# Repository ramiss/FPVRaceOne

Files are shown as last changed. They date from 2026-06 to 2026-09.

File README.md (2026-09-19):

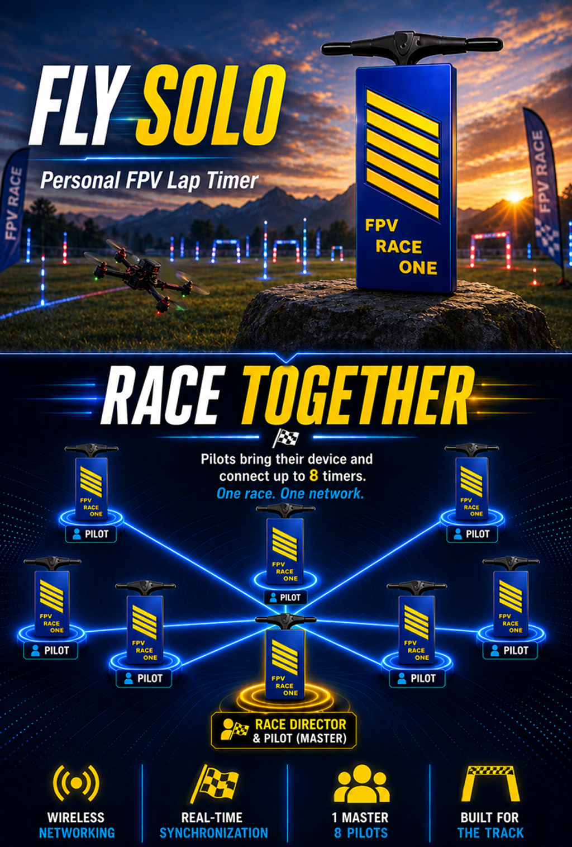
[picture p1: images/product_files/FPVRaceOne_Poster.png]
Poster


# FPVRaceOne

**Personal FPV Lap Timer**

[Build one yourself](docs/BUILD_FROM_SCRATCH.md) OR
[Purchase FPVRaceOne ready to use](https://fpvwidgets.square.site)



A single node personal lap timing solution for 5.8 GHz FPV drones that can be networked to other units (8 total) for multi-pilot racing. Perfect for personal race or practice sessions with one unit (indoor and large scale) up to MultiGP race events with multiple units. No additional networking hardware required — just plug in a USB power, connect over wifi, calibrate, and fly.

**Up to 8 devices can wirelessly network with each other to act as a single multi-node lap timer (no additional hardware or software needed)** — one device is set to master mode and acts as race director with up to 7 additional clients. Manually connect clients or have the master automatically recruit clients in range.  Master can see all pilot times and control the race, while single pilots can remain logged into their device and see all other racer times - or initiate individual practice races. 

**Documentation**  
[Quick Start](QUICKSTART.md) - To get started as a single pilot with the bare minimum information  
[Getting Started](docs/GETTING_STARTED.md) - For a more comprehensive step by step guide  
[User Guide](docs/USER_GUIDE.md) - The full manual, but not necessarily a step by step  
[Build From Scratch](docs/BUILD_FROM_SCRATCH.md) - Wiring, assembly and flashing, if you'd rather build your own

---

## Screenshots - Single Mode

| Race Screen | Configuration |
|:---:|:---:|
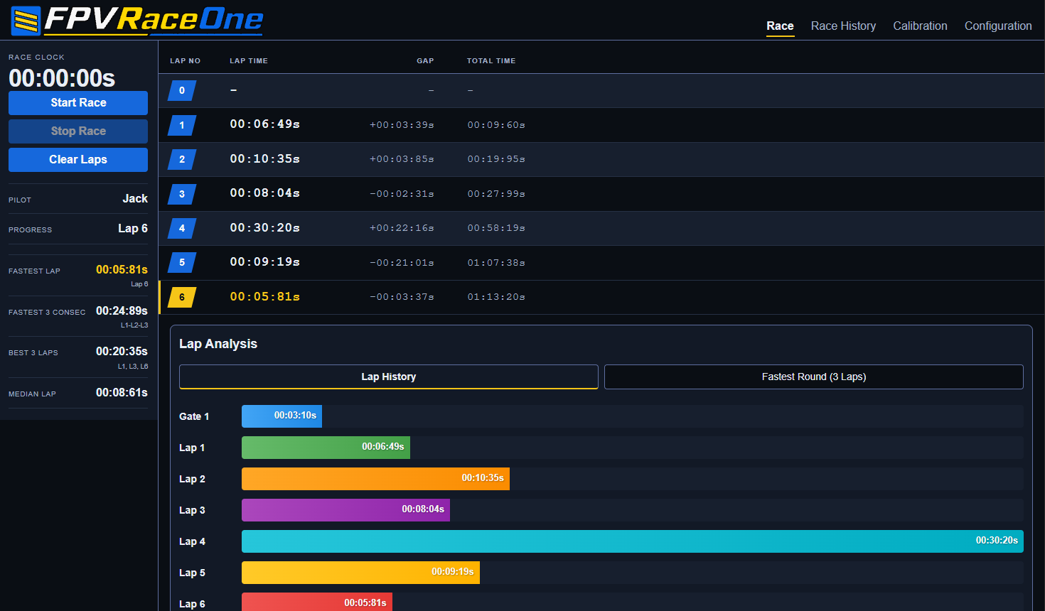
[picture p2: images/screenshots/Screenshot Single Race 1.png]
Race Screen
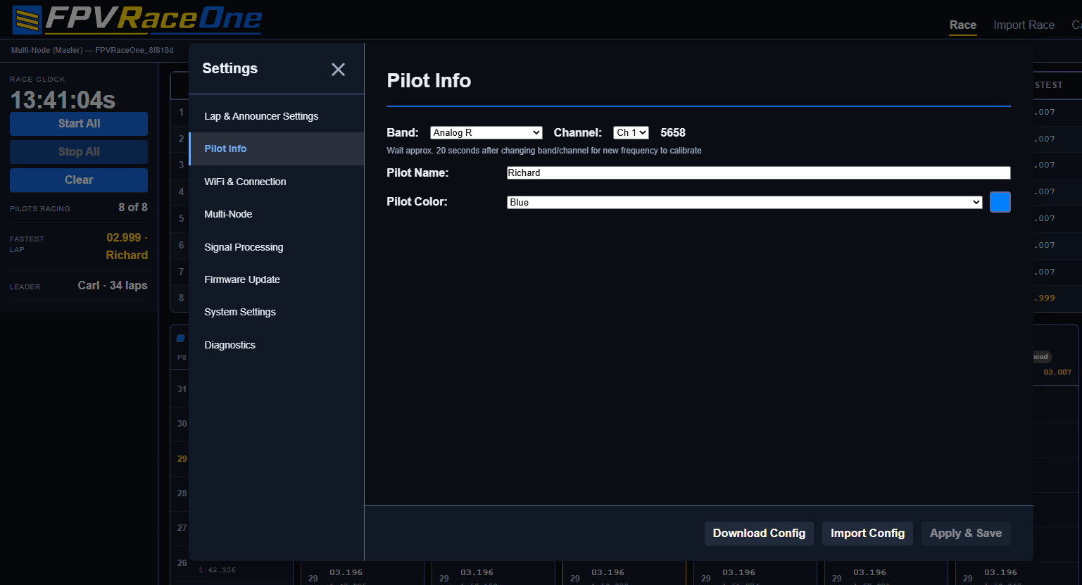
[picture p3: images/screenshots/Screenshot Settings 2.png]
Config Menu
|  |  |

| Calibration Wizard — Recording | Calibration Wizard — Complete |
|:---:|:---:|
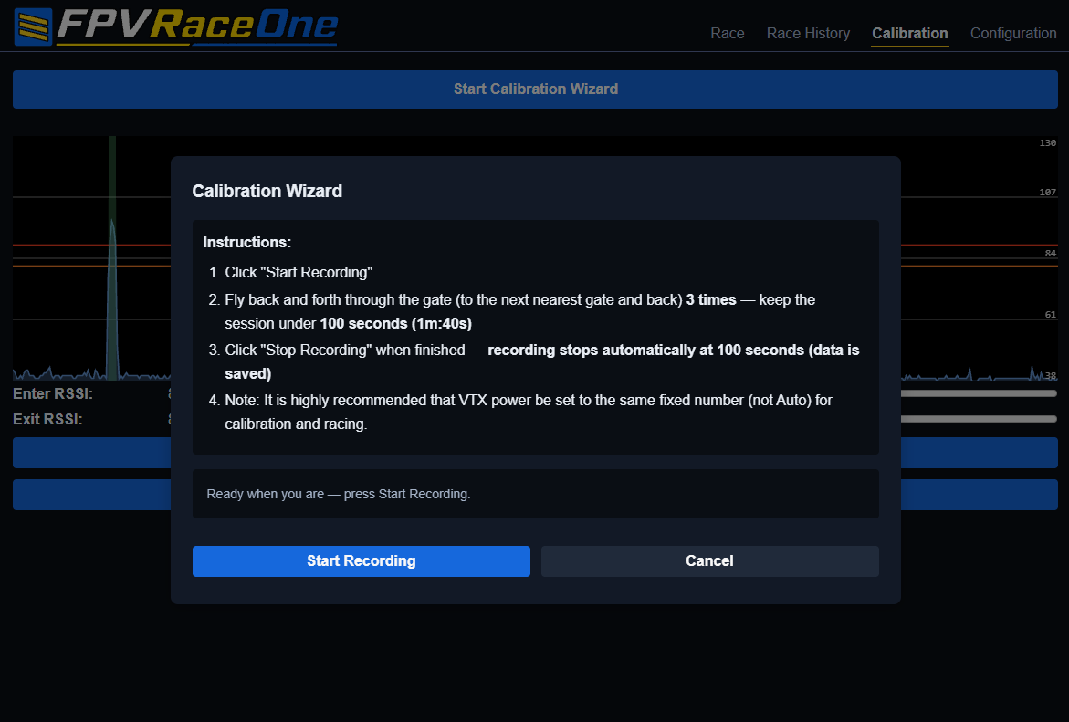
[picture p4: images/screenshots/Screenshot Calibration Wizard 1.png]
Calibration Recording
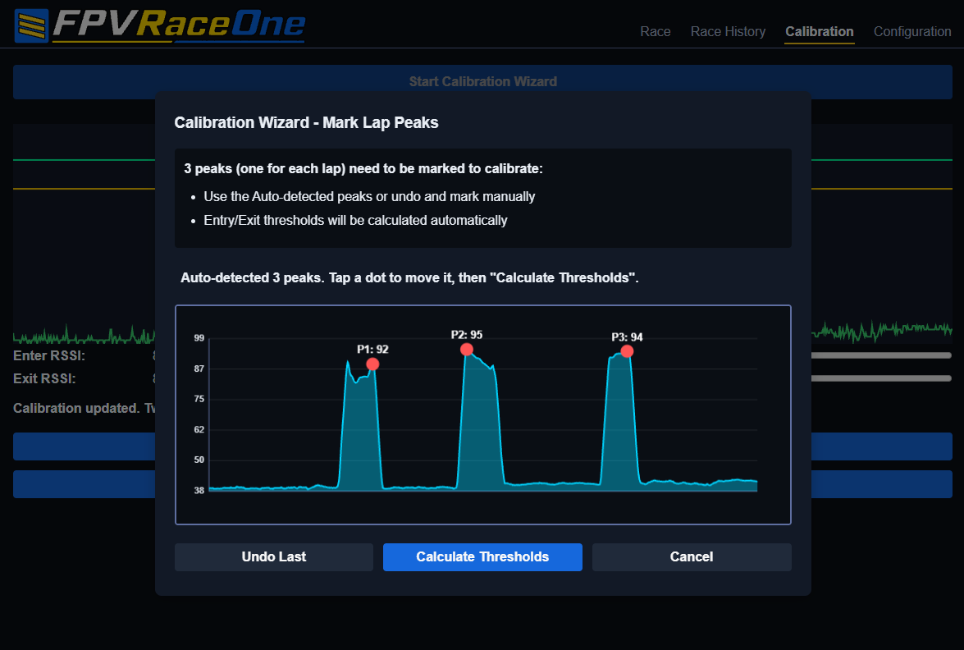
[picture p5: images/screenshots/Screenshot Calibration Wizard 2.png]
Calibration Complete
|  |  |

## Screenshots - Multi Mode

| Master Race Screen | Master Pilot Edit |
|:---:|:---:|
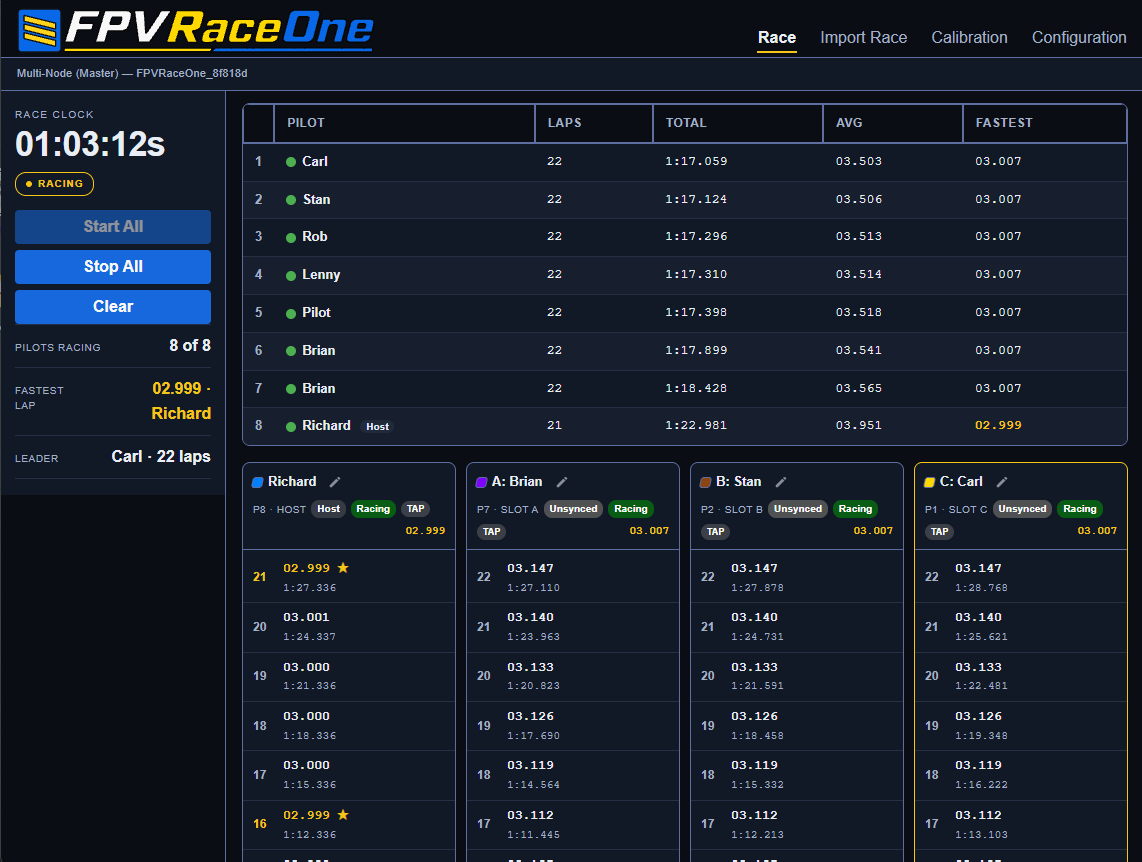
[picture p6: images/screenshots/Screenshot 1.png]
Master Race Screen
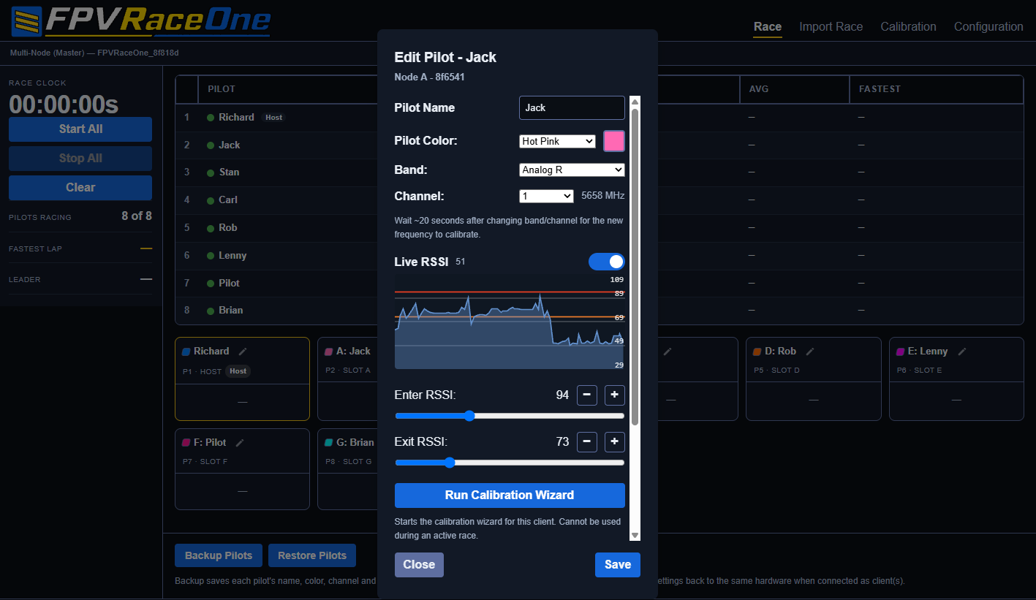
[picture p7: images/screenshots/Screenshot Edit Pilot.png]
Master Pilot Edit
|  |  |

## 14 Themes to choose from (4 samples below)

<p>
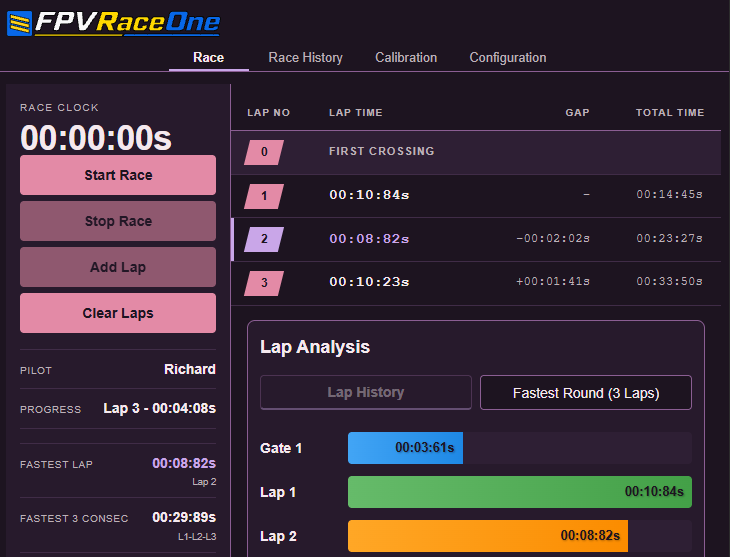
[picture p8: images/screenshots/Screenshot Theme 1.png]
Theme example 1
  
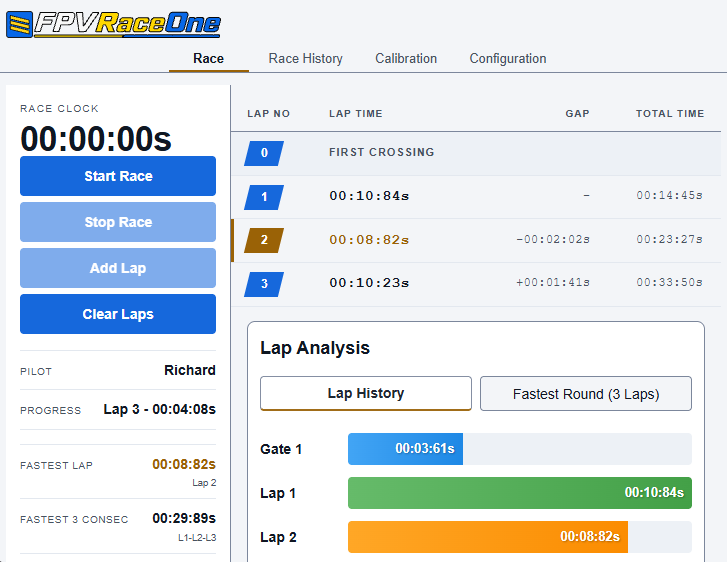
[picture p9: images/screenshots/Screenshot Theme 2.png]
Theme example 2
  
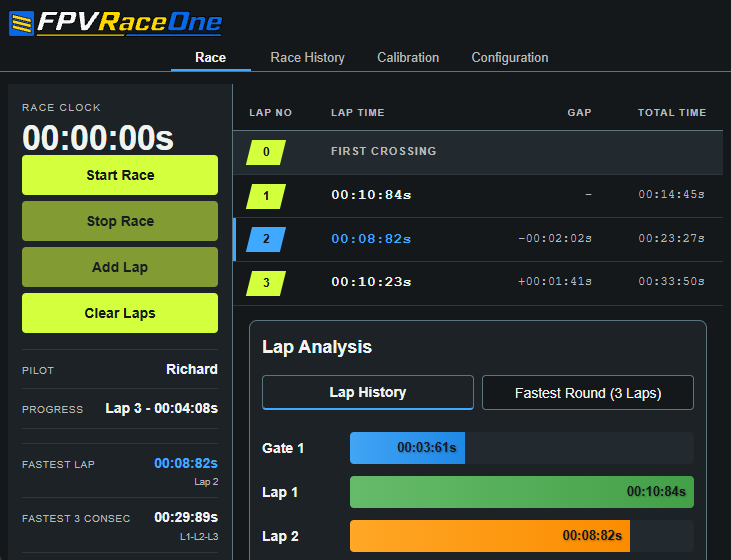
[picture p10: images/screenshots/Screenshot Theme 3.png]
Theme example 3
  
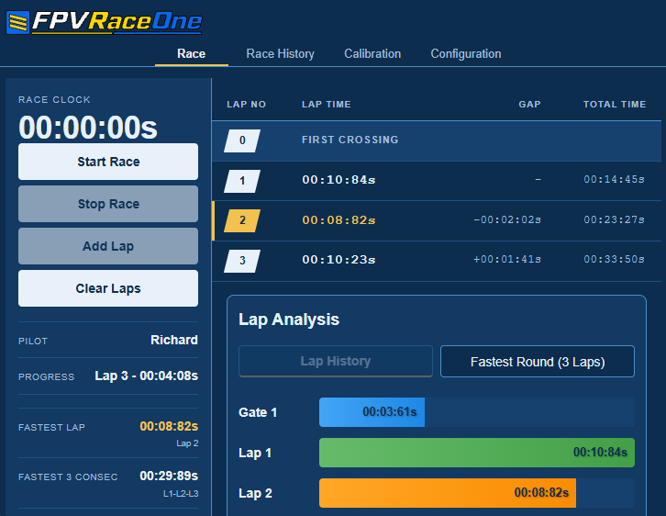
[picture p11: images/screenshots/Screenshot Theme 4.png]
Theme example 4
  
</p>

---

## How It Works

FPVRaceOne uses an RX5808 video receiver module to monitor your drone's video transmitter RSSI (signal strength). As you fly through the timing gate:

1. **Approach** — RSSI rises above the Enter threshold → crossing begins
2. **Peak** — RSSI peaks when you're closest to the gate
3. **Exit** — RSSI falls below the Exit threshold → lap time recorded

**Note that FPVRaceOne has an automatic calibration wizard to take the guess work out of setting the RSSI values (see below)**

```
RSSI  │     /\
      │    /  \
      │   /    \     ← Single clean peak
Enter ├──/──────\───
      │ /        \
Exit  ├/──────────\─
      └─────────────── Time
```

The time between consecutive peaks is your lap time. The signal processing pipeline is tuned with sensible defaults out of the box, with a single Pipeline Smoothing slider for fine-tuning the balance between responsiveness and noise rejection.

---

## Key Features

### Connectivity
- **WiFi Access Point** — works with any browser on any device (laptop, pc, phone or tablet) with wifi, no app required
- **Built-in Multi-Node Networking** — up to 8 lap timers can connect together to run a multi pilot race.

### Signal Processing

**Hardware-timed acquisition.** The ESP32-C6's ADC samples the RX5808's RSSI line
continuously into a DMA ring at **20 kHz**, completely independent of CPU
scheduling. 

**Single-stage filtering.** A running median with a small odd window
(**N = 3–15**, default **7**, set by the Pipeline Smoothing slider). A median
rejects isolated spike samples outright while preserving the true peak amplitude
of a fast pass — the property a mean-based filter doesn't have. Backed by a
two-sample enter debounce, so a brief noise burst cannot open a crossing, and a
watchdog that releases the crossing state if RSSI drifts up to the enter threshold
and stays there.

### RSSI Automatic Calibration Wizard
Guided calibration wizard with real-time RSSI charts: Fly 3 passes over the start gate (timer) and let the wizard auto calibrate
- Automatic 3-peak detection with manual override
- Enter / Exit threshold calculation with conservative safety margins (Enter ≈ 95 % of weakest peak, Exit = Enter − 4, raised above the noise floor)
- Peak-spread warning if the three peaks aren't reasonably equal — flagged for re-fly before applying
- Live RSSI chart shows exactly what the lap detector sees (final pipeline output)
**Note:** recording is capped at **100 seconds**, and the wizard stops on its own when it gets there. If the timer is short on memory it will grant a shorter window and tell you so on screen before you start. Nothing is recorded until you press **Start Recording**, so take your position at the gate first. Fly through the timing gate, on to the next closest gate, back through the gate (out to the next gate on the other side), and back through a third time — then land and press **Stop Recording**.

### Multi-Node Racing — Built-In Race Directing
Network **up to 8 devices** together using on-board Wifi (no router or extra hardware required). One device runs in **Master** mode (race director); up to seven **Client** devices join the master's WiFi and forward laps automatically. Each pilot should remain connected to their own device over wifi.  All devices in multi-mode will see the entire race board.

- **Master Recruit** — the master can automatically scan for FPVRaceOne clients in range and configure them to join the network. Or each client can search for a master and connect manually.
- **One-tap Start All / Stop All** — broadcast a synchronised race start to all pilot on the network
- **Live all-pilots dashboard on the master and clients** — each client renders as a card with pilot name, running indicator (●/○), live lap count, and last lap time, updated via Server-Sent Events with sub-second latency. Slot cards labelled A through G match what the director sees in serial logs
- **Master can edit and configure all pilots from the Race tab** — pencil icon on every slot card opens a per-pilot editor for name, color, band, channel, RSSI thresholds, and skip flag — works on the master's own host card too
- **Calibration Wizard from the modal** — run the full guided wizard against any connected client; the wizard records on the target client and pushes thresholds back when you click Apply
- **Live RSSI feed in the modal** — toggle on the right of the title polls the selected client at 5 Hz; the firmware-side peak-since-last sampler catches a brief gate pass even at that rate. Red Enter / orange Exit threshold lines track the sliders as you drag
- **Move (Swap) Pilot to Slot** — letter dropdown (A–G) reassigns a node to a different slot; if it's occupied, the two pilots swap places and both persist their new slot to NVS
- **DNF tracking** — a pilot who taps Stop locally during a master race shows up as **DNF** on the director's screen; the rest of the heat continues uninterrupted
- **Solo-practice override** — each client has an *Ignore Race Director Start/Stop if already racing* toggle so a director's broadcast doesn't kill an in-progress practice run
- **Master discovery** — clients can scan for available masters in range and pick one from a list (no manual SSID typing required)
- **Same UI on every device** — every client also runs as a fully featured standalone timer when no master is broadcasting

### Voice Announcements
- Spoken laps using your **browser's** built-in voice (Web Speech API) — no audio files on the device, so the announcer follows whichever device has the web UI open
- Configurable announcement format (pilot + lap + time, pilot + time, lap + time, time only)
- Per-pass beep or full speech, 2-lap and 3-lap consecutive variants
- Lap times of 60 seconds or longer are announced as "X minute(s) Y point ZZ" — long-track friendly
- Single on/off **Voice toggle** in Settings

### Race Analysis
- Real-time lap tracking with gap-to-best analysis
- Fastest lap highlighting
- Fastest 3 consecutive laps (RaceGOW format)
- Interactive race timeline + playback for every saved session
- Marshalling mode — add, remove, or edit laps after the race ended
- Download the session as JSON; re-import later. **Race history lives in RAM only on the current hardware — download to keep**.

### Firmware Updates
- **One-tap OTA from GitHub Releases** — built into the device. Enter your home WiFi once; the device joins, checks the latest release, downloads the firmware + filesystem images, flashes both, and reboots.
- Updates are blocked while a race is running. Failed downloads keep the previous firmware, so the device can't be bricked from a flaky network.
- Manual flashing via our custom tool FPVRaceOne-Flasher (Windows) — see [Flash the Firmware](docs/BUILD_FROM_SCRATCH.md#step-5--flash-the-firmware).

---

## Supported Bands & Frequencies

| Band | Channels (MHz) |
|---|---|
| **A (Boscam A)** | 5865, 5845, 5825, 5805, 5785, 5765, 5745, 5725 |
| **B (Boscam B)** | 5733, 5752, 5771, 5790, 5809, 5828, 5847, 5866 |
| **E (Boscam E)** | 5705, 5685, 5665, 5645, 5885, 5905, 5925, 5945 |
| **F (Fatshark)** | 5740, 5760, 5780, 5800, 5820, 5840, 5860, 5880 |
| **R (RaceBand)** | 5658, 5695, 5732, 5769, 5806, 5843, 5880, 5917 |
| **L (LowBand)** | 5362, 5399, 5436, 5473, 5510, 5547, 5584, 5621 |
| **DJI v1 25 MHz** | 5660, 5695, 5735, 5770, 5805, 5878, 5914, 5839 |
| **DJI v1 25 CE** | 5735, 5770, 5805, 5839 |
| **DJI v1 50** | 5695, 5770, 5878, 5839 |
| **DJI O3/O4 10/20** | 5669, 5705, 5768, 5804, 5839, 5876, 5912 |
| **DJI O3/O4 20 CE** | 5768, 5804, 5839 |
| **DJI O3/O4 40** | 5677, 5794, 5902 |
| **DJI O3/O4 40 CE** | 5794 |
| **DJI O4 RaceBand** | 5658, 5695, 5732, 5769, 5806, 5843, 5880, 5917 |
| **HDZero RaceBand** | 5658, 5695, 5732, 5769, 5806, 5843, 5880, 5917 |
| **HDZero E** | 5707 |
| **HDZero F** | 5740, 5760, 5800 |
| **HDZero CE** | 5732, 5769, 5806, 5843 |
| **Walksnail RaceBand** | 5658, 5659, 5732, 5769, 5806, 5843, 5880, 5917 |
| **Walksnail 25** | 5660, 5695, 5735, 5770, 5805, 5878, 5914, 5839 |
| **Walksnail 25 CE** | 5735, 5770, 5805, 5839 |
| **Walksnail 50** | 5695, 5770, 5878, 5839 |

---

## Quick Start

### Hardware

Pre-made and flashed hardware — [- Click here to purchase your FPVRaceOne at our store -](https://fpvwidgets.square.site)

Prefer to build your own? The wiring diagram, bill of materials, SPI conversion and a step-by-step flashing guide are in **[Build From Scratch →](docs/BUILD_FROM_SCRATCH.md)**.

- **[`case/`](case/)** — 3D-printable enclosure, ready-to-slice `.3mf` projects (single, four-up, and an ironed-lid variant). PETG, no supports — see [The 3D-Printed Case](docs/BUILD_FROM_SCRATCH.md#the-3d-printed-case)

**[Detailed hardware setup →](docs/GETTING_STARTED.md)**

### Connect via WiFi

1. Power on the device
2. Connect your phone or laptop to the `FPVRaceOne_XXXX` network (password: `fpvraceone`)
3. Open `http://192.168.4.1` in your browser (`http://192.168.5.1` in Master mode)
4. Go to **Settings → Set your VTx band and channel**
5. Go to **Calibration → Run the wizard** to set RSSI thresholds
6. Press **Start** and fly!

**[Complete user guide →](docs/USER_GUIDE.md)**

---

## Firmware Updates

FPVRaceOne can check for and automatically updates itself from **GitHub Releases** — no PlatformIO, no cables, no flashing tools required for normal updates.

1. Open the web UI → **Settings → Firmware Update**
2. Enter your home WiFi credentials (one-time)
3. Tap **Check for Updates** — the device briefly joins your home network, queries GitHub, then returns to AP mode
4. If a newer release is available you'll see the version and release notes — tap **Update Now**
5. The device flashes the filesystem, then the firmware, then reboots once. Total time ~1–3 minutes.
6. Hard reload your browser to guarantee new changes are loaded (Ctrl+Shift+R on Windows/Linux, Cmd+Shift+R on Mac. Tap-and-hold the refresh button on mobile Chrome to get "Hard reload")

Updates are automatically blocked while a race is running. 

---

## Project Status

**Product:** FPVRaceOne  
**Platform:** Seeed XIAO ESP32-C6  
**License:** MIT  
**Status:** Stable Release — actively maintained

### Changelog

See [CHANGELOG.md](CHANGELOG.md) for the version history.

---

## Credits

FPVRaceOne originated from FPVGate v1.2.0 by Louis Hitchcock, which itself originated as a fork and substantial rewrite of PhobosLT by Phobos. FPVRaceOne has since diverged into an independently developed project.
FPVGate is a fork of [PhobosLT](https://github.com/phobos-/PhobosLT) by phobos-. 

Thanks goes out to Louis Hitchcock for his understanding, patience and partnership.  Feel free to check out his work over at the FPVGate project.

---

## License

This project is licensed under the MIT License — see the [LICENSE](LICENSE) file for details.

---

*Built for pilots, by pilots.*

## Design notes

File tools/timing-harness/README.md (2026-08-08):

# FPVRaceOne timing test rig

Measures whether the lap timer is **late** or **inconsistent**, using a
deterministic synthetic stimulus instead of a real drone.

Real-world stimulus can't answer this. A servo swinging past an antenna has
millisecond-scale variance of its own, so you end up characterising the servo.
This rig replaces the RX5808's analog RSSI output with a precisely-timed
envelope generated by a second ESP32.

## What it measures

| Metric | Meaning | How |
|---|---|---|
| **Bias** | Is the timer systematically late? | mean(reported lap − known interval) |
| **Jitter** | Is the timer inconsistent? | stdev of that error |
| **Latency** | Absolute stimulus→detection delay | marker GPIO, timed on the emulator |
| **Min pass width** | Fastest detectable gate pass | duration sweep |

### Why no clock synchronisation is needed

A lap time is a **difference measured entirely by FPVRaceOne's own clock**. The
emulator generates pulses exactly *T* apart; the device reports lap time *L*;
the error is `L − T`. No relationship between the two clocks is involved, so USB
latency and jitter are irrelevant.

Absolute latency works the same way — the emulator timestamps both its own
stimulus and the device's marker edge on one hardware timer.

## Hardware

- **Emulator**: ESP32-WROOM-32. Chosen because it is the only ESP32 variant with
  a built-in DAC — the C6, C3 and S3 have none. 8-bit also matches `readRssi()`'s
  own quantisation exactly.
- **DUT**: the XIAO ESP32-C6 FPVRaceOne unit.

## Wiring

```
ESP32 WROOM-32 (emulator)              XIAO ESP32-C6 (FPVRaceOne)

  GPIO25 / DAC1  ──[2.2k]──┬────────── A2  = GPIO2   PIN_RX5808_RSSI
  (header pin 9)           │
                         [1.0k]
                           │
  GND (pin 14/32/38) ──────┴────────── GND           common ground, REQUIRED

  GPIO4 (pin 26, input) ◄───────────── D3  = GPIO21  PIN_TIMING_MARKER
```

The divider drops the DAC's 0–3.3 V to ~1.03 V, matching the RX5808's 0–1 V
output and landing full scale near `RSSI_SCALE_MAX` (2400 counts ≈ 1.026 V under
`ADC_6db`). Keep 2.2k/1.0k rather than scaling up — it holds source impedance at
~690 Ω for clean ADC sampling.

**Disconnect the real RX5808 from the RSSI line only.** Two sources fighting
invalidates everything. The three SPI lines can stay wired — the emulator is
analog-only and ignores them.

> Note: the XIAO C6 block in `lib/CONFIG/config.h` uses **Arduino aliases, not raw
> GPIO numbers**. `PIN_RX5808_RSSI` is `A2` = GPIO2. Don't take the pin numbers
> from the ESP32C3 block above it.

## Build and flash

**1. FPVRaceOne** — set the marker on in `lib/CONFIG/config.h`:

```c
#define TIMING_MARKER_ENABLED 1
```

Then `pio run -t upload`. Remember to set it back to `0` before releasing —
without it the pin is never driven and the whole feature compiles away.

**2. Emulator** — from the main project's PlatformIO task list:

> **Upload RX5808 Emulator (Test Rig)**

or from a terminal:

```
pio run -t upload_emulator
```

The task picks the port by USB vendor ID and **refuses to upload to a
FPVRaceOne unit**: the WROOM-32 devkit presents a CP210x/CH340/FTDI bridge,
while the XIAO C6 presents Espressif native USB (0x303A). Set `EMULATOR_PORT`
to force a port if the heuristic guesses wrong.

## Running — GUI (recommended)

```
python tools/timing-harness/gui.py
```

Buttons for the three tests in the order you should run them, editable stimulus
settings, auto-detected ports, and plain-language interpretation of every
result. Tkinter only, so no install beyond pyserial.

## Running — command line

```bash
python harness.py --list                       # find the two ports

# Validate the analog path BEFORE trusting any timing number
python harness.py --emu COM7 --dut COM5 level --value 200

# Accuracy + consistency
python harness.py --emu COM7 --dut COM5 interval --count 50 --interval 3000

# Minimum detectable pass width
python harness.py --emu COM7 --dut COM5 sweep --widths 100,80,60,40,30,20,15,10
```

The GUI imports its measurement logic from `harness.py`, so the two cannot
drift apart.

### Suggested sequence

1. `level` — confirm the device's RSSI tracks the commanded DC value. This
   validates the divider before any timing is measured.
2. `interval` in **polled** mode — record bias, stdev, latency.
3. Switch Settings → Signal Processing → Sampling mode → **DMA continuous**,
   reboot, **re-run the calibration wizard** (peak-hold changes what the numbers
   mean, so old thresholds don't carry over), then repeat.
4. `sweep` in both modes — this is where DMA peak-hold should separate from
   polled, if it does at all.
5. Cross-check against Diagnostics → RSSI Sample Timing and CPU Load from the
   same runs, so bench and on-device instrumentation corroborate each other.

## Gotcha: Min Lap silently discards passes

Lap detection is gated by **Min Lap** (default **5000 ms**). Any crossing sooner
than that after the previous one is discarded *by design*. Gate 1 is exempt.

So a run whose pass interval is shorter than Min Lap reports **exactly one lap**
and looks like total detection failure, when the firmware is behaving perfectly:

```
Passes generated : 30
Laps reported    : 1        <- every pass after Gate 1 hit the minLap guard
```

Both tools now read the device's Min Lap over USB and refuse to run rather than
produce that misleading result. Three ways forward:

- Keep the default 6000 ms interval (above the 5000 ms Min Lap).
- Set Min Lap to 0 in Settings — allows much shorter intervals.
- Tick **Force device Min Lap = 0** in the GUI, which sets it for the run and
  restores it afterwards. This turns a ~16 minute sweep into about 4.

## A note on reading amplitude from the Calibration chart

Don't. The chart streams RSSI at 10 Hz (one sample per 100 ms), so a 40 ms pass
is usually sampled on its rising or falling edge, not at the peak — the trace
under-reports amplitude badly for short pulses.

Use **Check Analog Path** instead. It holds steady DC levels for ~800 ms each,
which the 10 Hz stream resolves properly, and fits the gain across eight points.

## Interpreting results

**Bias** largely cancels for lap times — the same delay applies to both
crossings and subtracts out. A large bias matters mainly for head-to-head racing
between two *different* devices, where the delays may differ.

**Jitter is the one that costs you.** Lap-time error is
`jitter(crossing 2) − jitter(crossing 1)`, so consistency is what shows up in the
recorded lap.

**Detection rate in the sweep** is the quantitative form of "how fast a drone
can we detect". If polled and DMA converge here, DMA is not earning its
complexity.

## Limitations

This reproduces the RSSI **envelope**, not RF. No multipath, no antenna nulls, no
interference. It faithfully exercises the acquisition and detection pipeline; it
does **not** predict real-world detection reliability. Worth stating plainly so
the results aren't over-claimed.

The first lap of each run is discarded — FPVRaceOne's first crossing is Gate 1,
which *starts* a lap rather than completing one, so its reported time is not an
inter-pulse interval.

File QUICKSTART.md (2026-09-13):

# FPVRaceOne Quick Start

The 5-minute path from unboxing to first lap. For detail on any step —
hardware, multi-node racing, firmware updates, troubleshooting — see
**[Getting Started](docs/GETTING_STARTED.md)**.

## 1. Power and connect

- Plug a USB-C power source into the FPVRaceOne; wait ~10 seconds for the AP to come up
- Place the timer at the timing gate (typically the first gate), with the stripes (front of the unit) facing inwards towards the center of the gate (facing the drone as it passes)
  Note: make sure the timer has a clear line of sight to your browsing device.  You may need to attach it higher on the gate if there is grass or other obstacles in the way.  
- Connect your phone / laptop to WiFi **`FPVRaceOne_XXXX`** (password **`fpvraceone`**)
- Open **`http://192.168.4.1`** in any browser

## 2. Set your VTx band and channel

**Settings → Pilot Info → Band** and **Channel** to match your drone's VTx.
Auto-saves on selection.

## 3. Calibrate

1. Power on your drone with **VTx on a fixed power level** (not auto); let it warm up ~30 s
2. **Calibration** tab → **Start Calibration Wizard**. Read the instructions, get into position — nothing records yet
3. Press **Start Recording**, then fly **3 passes** through the start gate (through, around, back — repeat)
4. Press **Stop Recording** → review the three detected peaks → **Calculate Thresholds**

The new Enter/Exit values are saved to the timer automatically. Close the wizard,
or fine-tune the sliders on the Calibration tab and press **Save RSSI Thresholds**.

## 4. Race

**Race** tab → **Start Race** → fly! → **Stop Race** when done. The session is
saved automatically. **Download** the session JSON before unplugging if you
want to keep it — race history isn't persisted across reboots.

---

## Default Settings (Quick Reference)

| Setting | Value |
|---|---|
| WiFi | `FPVRaceOne_XXXX` / `fpvraceone` |
| Web address | `http://192.168.4.1` |
| Min lap time | 5 seconds |
| Max laps | Infinite (0) |
| Pipeline Smoothing | Level 5 |
| Gate-1 Bootstrap | Off |

---

**Next:** [Getting Started](docs/GETTING_STARTED.md) covers multi-node race
directing, OTA firmware updates, the Edit Pilot modal, the full
troubleshooting tables, and tips for race day.

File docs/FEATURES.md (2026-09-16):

# FPVRaceOne Technical Features Reference

In-depth technical documentation of all FPVRaceOne capabilities.

**Navigation:** [Home](../README.md) | [Getting Started](GETTING_STARTED.md) | [User Guide](USER_GUIDE.md)

---

## Table of Contents

1. [Connectivity](#connectivity)
2. [Signal Processing](#signal-processing)
3. [Lap Detection](#lap-detection)
4. [Calibration Wizard](#calibration-wizard)
5. [Voice Announcements](#voice-announcements)
6. [Race Analysis](#race-analysis)
7. [Race History & Data Management](#race-history--data-management)
8. [Multi-Node Racing](#multi-node-racing)
9. [Configuration Management](#configuration-management)
10. [OTA Updates](#ota-updates)
11. [Self-Test System](#self-test-system)
12. [Technical Architecture](#technical-architecture)

---

## Connectivity

### WiFi Access Point

FPVRaceOne creates its own WiFi network — no router required.

| Property | Value |
|---|---|
| SSID | `FPVRaceOne_XXXX` (last 4 MAC digits) |
| Security | WPA2-PSK |
| Default password | `fpvraceone` |
| IP address | `192.168.4.1` (Single / Client), `192.168.5.1` (Master) |
| Band | 2.4 GHz |
| Max clients | 1 pilot per device (master also allows up to 7 units to connect) |
| AP inactivity timeout | 60 s — a silent station drops within a minute so its slot frees up |

No captive DNS — connected devices should retain their cellular internet connection on most platforms (Samsung devices block this and forces one or the other).

The USB-C connector on the device is used for **power and flashing only** — there is no user-facing USB control protocol in the current firmware.

---

## Signal Processing

### ADC Input

- **Hardware:** Seeed XIAO ESP32-C6 12-bit ADC
- **Attenuation:** 6 dB (input range 0–1.75 V)
- **Scale:** 1 V ≈ 2340 counts; full-scale divisor = 2400
- **Output:** 0–255 (8-bit, clamped)

### Acquisition — DMA Continuous with Peak Hold

The shipping default (`adcMode = 1`). Selected at boot; changing it requires a
reboot.

| Property | Value |
|---|---|
| Mode | `adc_continuous` (hardware-timed, DMA into a ring buffer) |
| Sample rate | 20 kHz (`ADC_DMA_SAMPLE_HZ`) |
| Frame size | 128 bytes = 32 conversions (`ADC_DMA_FRAME_BYTES`) |
| ISR rate | ~625 Hz |
| ISR work | Reduce the completed frame to its **maximum** |
| Read | `__atomic_exchange_n` — returns the running peak and zeroes it in one instruction |

Every `readRssi()` therefore returns the highest value the hardware saw since the
previous read, so a narrow peak cannot be lost to a late main loop. When no frame
has completed since the last read (loop running faster than 625 Hz) the previous
DMA sample is held rather than falling back to `analogRead()` — the two drivers
report different scales, so mixing one in would inject a false trough.

**Scale correction.** The oneshot and continuous drivers do not return the same
counts for the same voltage on the C6. Measured on hardware with a DC sweep:

```
polled : rssi = 0.888 * input + 4.6
DMA    : rssi = 1.706 * input + 10.4      → 1.921x higher
```

The DMA path is divided by that ratio (`RSSI_DMA_GAIN_NUM = 1921`) so both modes
report the same RSSI for the same voltage and a calibration transfers between
them. Re-derive with the timing harness's "Check Analog Path" in each mode if a
future chip or IDF revision shifts it.

The legacy **polled** path (`adcMode = 0`, one `analogRead()` per loop, ~200–500 Hz)
still exists in firmware but is no longer selectable in the UI. Measured lap
jitter: DMA 0.00 ms vs polled 1.21 ms.

### Filtering — Single-Stage Running Median

One stage. Odd window, sized by the Pipeline Smoothing slider (`v1Smoothing`):

| Slider | 0 | 1 | 2 | 3 | 4 | 5 | 6 | 7 | 8 | 9 | 10 |
|---|---|---|---|---|---|---|---|---|---|---|---|
| **N** | 3 | 3 | 5 | 5 | 7 | **7** | 9 | 11 | 13 | 13 | 15 |

Default level 5 → N = 7 → ~14–35 ms window at 500–200 Hz loop rate. The window is
re-read every sample, so the slider takes effect mid-race without a restart.

A median rejects isolated spikes while preserving true peak amplitude. Design
intent matches RotorHazard's `FastRunningMedian`; the window is smaller because
their 1 kHz sample rate on a dedicated ATmega allowed N = 255.

> **Replaced a five-stage cascade** (Kalman → median-of-3 → 7-sample moving
> average → EMA → step limiter). Its combined lag smeared fast peaks enough that
> high-speed gate crossings sometimes failed to reach Enter. `lib/KALMAN/` is
> retained in the tree but is no longer referenced by the detection path.

Samples taken while the RX5808 is mid-tune are skipped entirely rather than
filtered — `readRssi()` returns 0 during a tune, and feeding those zeros through
would drag the filter down and suppress a real peak after a channel change.

### Gate Detection

- **2-sample enter debounce** (`kEnterHoldMin`) — consecutive samples at or above Enter RSSI before a crossing starts, backing up the median's spike rejection. Adds ~3–7 ms of latency
- **Exit on the first sample below Exit RSSI** — no confirm count
- **No peak margin** — reaching Enter on the filtered signal is by definition a valid pass, so no extra counts above Exit are required
- **Ceiling-drift watchdog** — if "in gate" for >3 s without an exit, state is force-reset (the antenna RSSI must have drifted up to enter)

Both the enter debounce and the watchdog are compile-time constants
(`kEnableEnterDebounce`, `kEnableCeilingWatchdog`) intended to stay on in
production; they exist as switches only for bench characterisation.

### Optional Gate-1 Bootstrap

When enabled, the first lap of a race is special-cased so a drone already inside the gate at race start still produces a clean first lap:

- Relaxed effective enter threshold (~exit + 4 counts)
- Lower 2-sample debounce
- Lower 3-count peak-above-exit margin
- If RSSI at race start is already ≥ enter, the peak is seeded so the first confirmed exit counts as Gate 1

---

## Lap Detection

### State Machine

```
IDLE
 │ (RSSI > Enter for N hold samples)
 ▼
ENTERED — tracking peak
 │ (RSSI falls below Exit for M confirm samples)
 ▼
LAP CONFIRMED → record timestamp, trigger events
 │
COOLDOWN (minimum lap time)
 │
IDLE
```

### Timing Accuracy

| Factor | Impact | Notes |
|---|---|---|
| RSSI sampling rate | ~10 ms | 100 Hz loop |
| Peak detection | ±10 ms | Per-sample resolution |
| System timer | < 1 ms | `millis()` |
| Lap timestamp | At peak sample | Recorded at the sample where the peak was reached |

### Minimum Lap Time

Laps triggered within the minimum lap time are silently ignored. This prevents double-counting when the drone lingers near the gate or crashes close to it.

---

## Calibration Wizard

### Recording Phase

- Firmware stores up to 5000 RSSI samples with millisecond timestamps in a dedicated calibration buffer
- The wizard records the **final pipeline output** (post running-median) — what the lap detector actually sees
- One sample every 20 ms (~50 Hz)
- Multiple fly-over passes can be recorded in a single session, but **3 passes is the sweet spot** for the threshold calculator

### Analysis Phase

After recording stops, the full dataset is streamed to the browser in pages (500 samples/page) and rendered on a chart.

The wizard auto-detects the three highest peaks and overlays markers; any marker can be dragged manually to correct a missed detection.

**Threshold calculation:**

| Threshold | Formula | Reason |
|---|---|---|
| Enter RSSI | `round(0.95 × min(peakA, peakB, peakC))` | 5 % headroom keyed to the *weakest* peak so even the weakest pass triggers |
| Exit RSSI | `Enter − 4`, raised above noise floor | Tight hysteresis tuned for close-pattern tracks; never below 35th-percentile noise + 3 |

Both values are clamped to `[30, 255]` and Exit is forced ≥ 4 below Enter as a fallback hysteresis.

### Peak-Spread Warning

If the three peaks differ in height by more than ~15 % (weakest / strongest < 0.85), the wizard surfaces a non-blocking warning recommending a re-fly. False positives are cheap (the user can ignore and continue); false negatives leave the pilot with sub-optimal calibration without ever knowing.

### Overview Mode

- After recording, the calibration chart replaces the live scanner with the full recorded dataset
- The live scanner can be restored at any time by exiting overview mode
- The live signal can be **paused** to examine a specific moment; Enter/Exit lines move in real time as sliders are adjusted even while paused

---

## Voice Announcements

Lap announcements are spoken by the **browser** that's logged into the web UI, not by the device. The web app uses the standard **Web Speech API** (`SpeechSynthesisUtterance`) so the actual voice quality and accent depends on the OS the browser is running on — modern Chrome/Edge/Safari all ship a usable English voice.

Implication: whichever device has the web UI open with "Enable Voice" turned on is the speaker. The race director's laptop is usually the right choice; pilot phones can stay silent so the gate doesn't sound like a chorus.

### Announcement Formats

| Format | Example |
|---|---|
| Pilot + Lap + Time | "Richard Lap 5, 12.34" |
| Pilot + Time | "Richard, 12.34" |
| Lap + Time | "Lap 5, 12.34" |
| Time Only | "12.34" |

### Announcer Types

| Type | Behaviour |
|---|---|
| None | Silent — only the firmware-driven start/stop beeps |
| Beep | Short beep on each lap, no speech |
| Lap Time | Speaks every lap |
| 2 Consecutive | Speaks the combined time of the last two laps |
| 3 Consecutive | Speaks the combined time of the last three laps (RaceGOW format) |

### Phonetic Name

If the Phonetic Name field is populated, it is used in place of the Pilot Name for the announcement. This lets you get correct pronunciation of non-phonetic spellings ("Ree-shar" for "Richard") without changing the display name shown elsewhere.

---

## Race Analysis

### Statistics

| Metric | Calculation |
|---|---|
| Fastest Lap | Minimum lap time, excluding Gate 1 |
| Median Lap | Middle value of sorted lap times |
| Best 3 Laps | Sum of 3 lowest individual lap times |
| Fastest 3 Consecutive | Minimum sum of any 3 back-to-back laps |

### Charts

- **Lap History** — Horizontal bars for last 10 laps; bar width proportional to time; each lap a distinct colour
- **Fastest Round** — Vertical bars for the 3-consecutive laps with the best combined time

The fastest lap row is highlighted gold in the lap table.

---

## Race History & Data Management

### Automatic Capture

Races are added to the in-memory log when:
- **Stop Race** is clicked
- **Clear Laps** is clicked (if laps exist)
- The Max-laps auto-stop fires

### Storage

Race history on the current hardware is **session-scoped (RAM-only)**. The XIAO ESP32-C6 build does not reserve a LittleFS slot for race storage — saved laps live in the web UI's state and a parallel in-firmware buffer, both of which clear on reboot.

The web UI surfaces this with a yellow banner reminding the user to **download** the session JSON before unplugging. Once downloaded, the JSON file is the durable record; re-import to view or re-edit later.

A persistent-storage path exists in the firmware code (`RaceHistory::saveRace`, `/races/race_<id>.json` layout) and is exercised by builds that have either an SD card or a dedicated LittleFS race partition. Neither is present on the C6 product configuration.

### JSON Format

```json
{
  "id": "race_1703001234567",
  "timestamp": "2024-12-04T14:30:45Z",
  "pilot": { "name": "Pilot Name", "callsign": "Callsign", "color": "#0080FF" },
  "frequency": { "band": "R", "channel": 1, "mhz": 5658 },
  "laps": [
    { "number": 0, "time": 8450, "name": "Gate 1" },
    { "number": 1, "time": 12340, "name": "Lap 1" }
  ],
  "stats": {
    "fastest_lap": 12340,
    "fastest_lap_number": 1,
    "median": 12340,
    "best_3_sum": 0,
    "best_consecutive_3": 0
  }
}
```

### Marshalling Mode

Laps can be added or removed from any saved race after the fact. All statistics and charts recalculate immediately. Changes are saved automatically.

### Export / Import

- Export individual races or full history as JSON
- Import merges races by ID — existing races are not overwritten

---

## Multi-Node Racing

Network up to **8 FPVRaceOne devices** together — one **Master** + up to seven **Clients** — without a router. The master runs an Access Point that every client joins; lap events stream back over plain HTTP and Server-Sent Events.

### Roles

| Role | Behaviour |
|---|---|
| **Single** (default) | Standalone — no inter-device traffic |
| **Master** | Race director. Hosts the WiFi AP that clients join; renders the multi-node Race tab; broadcasts Start All / Stop All |
| **Client** | Joins the master's AP. Presents the same race UI as standalone, plus a card on the master with live state |

Switching roles requires a reboot — the **Apply Multi-Node & Reboot** button only enables when Node Mode actually changes, so other multi-node settings can be tweaked without forcing a restart.

### Discovery

Clients can scan for available masters in range (`mnScanNetworks()`): every `FPVRaceOne_*` AP within signal is listed and tappable to autofill the Master SSID field.

### Master Race Tab

Each connected client appears as a card showing pilot name, running indicator, lap count, and last lap time. State updates stream from clients via 1 Hz heartbeats and are pushed to the browser as Server-Sent Events (`multiNodeState` event).

| Indicator | Meaning |
|---|---|
| ● **Running** | Client's lap timer is running |
| ○ **Stopped** | Client is idle |
| ⚠ **DNF** | Client pressed Stop locally during a master-broadcast race (early quit) |

### Start / Stop Broadcast

- **Start All** posts to every online client sequentially — calls land within ~350 ms of each other
- **Stop All** posts to every online client. The master's UI updates immediately on each acknowledged stop rather than waiting for the next heartbeat
- Each client decides what to do with the broadcast based on its own *Ignore Race Director Start/Stop if already racing* toggle (default off → honour broadcast)
- The client's local UI flips into race-running state — Start button looks pressed, Stop becomes the active button — same as if the pilot had pressed Start locally
- Race-mode broadcasts are not subject to the 2 s director-state throttle described in [Observability](#observability-serial-log)

### Early Quit Notification

When a client's pilot presses **Stop** locally during an active master-broadcast race, the client posts `/api/multinode/quit` to the master. The master sets `quitEarly = true` on that node and the card flips to **DNF** until the next master-broadcast Start All.

This is what lets a director keep a heat running cleanly when one pilot crashes or batteries out — they tap Stop on their own device, the rest of the field continues racing without interruption, and the director sees exactly who DNF'd.

### Solo-Practice Override

Each client has an **Ignore Race Director Start/Stop if already racing** toggle (`mnSkipMasterStart` in config). When on:

- A master Start All broadcast is silently ignored if the client's timer is already running locally
- The pilot can keep practising while a director runs heats on the rest of the field
- Toggle off to rejoin the directed race format

### Edit Pilot Modal from the Race Tab

Every slot card on the master's Race tab (including the master's own host
card) has a pencil icon that opens a per-pilot editor. The same modal
serves client pilots and the master; controls that don't apply to the host
(Move / Swap, Kick) are hidden on the host card.

The modal can:

- Edit pilot name, color, band/channel, RSSI thresholds, and the skip flag
- Run the **Calibration Wizard** against the selected node — for a client
  the wizard records on that client and pushes thresholds back through
  the master; for the host it runs locally
- Show a **Live RSSI** chart from the selected node at 5 Hz. The firmware
  returns the peak signal from the preceding 200 ms so a brief gate pass
  is caught even at that polling rate. The toggle on the right of the
  title defaults OFF and confirms before enabling during a race
- **Move (Swap) Pilot to Slot** — letter dropdown (A–G) reassigns the
  node to a different slot. If the target slot is occupied, the two
  pilots swap places and both clients persist their new slot through
  reboots
- **Kick from Slot** pauses the client's reconnection attempts for one
  minute so another unit can take its place

Save commits changes and keeps the modal open with a brief "Saved ✓"
feedback. The middle section scrolls; Save/Close stay pinned at the bottom.

### Live RSSI Proxy

Two endpoints feed the Edit Pilot modal's chart:

| Endpoint | What it returns |
|---|---|
| `GET /timer/rssi` | `{"rssi": N}` — the peak signal observed since the previous request, sampled at the firmware's full rate. A 5 Hz poll catches the true peak from the preceding 200 ms rather than a random instantaneous value |
| `GET /api/multinode/rssi?nodeId=N` (master only) | Proxies to the named client's `/timer/rssi` over the AP. A successful round-trip also keeps the master's heartbeat watchdog quiet, so the live view can't false-time-out the client it's watching |

Polling defaults to OFF when the modal opens. Enabling the live feed
during an active race prompts a confirmation dialog explaining the WiFi
bandwidth cost.

### Master Recruit Nearby Units

`POST /api/multinode/recruit?force=0|1` queues a recruit job on the master:

1. Drop the master's AP
2. Scan for every `FPVRaceOne_*` AP in range
3. For each match (skipping units already in Client / Master mode unless
   `force=1` is set), join the target, configure it as a client pointed
   at this master, and reboot it
4. Restart the master's own AP

Total downtime is roughly 60 seconds — a full-screen overlay on the
director's browser holds focus during the pass and confirms completion
when the AP returns.

---

## Configuration Management

### Storage

All device configuration is stored in EEPROM with a version stamp. When the version doesn't match (e.g. after a firmware update that adds new fields), the device loads defaults.

A backup is also written to LittleFS which can be restored if EEPROM is invalidated.

### Versioning

`CONFIG_VERSION` is incremented whenever the config struct changes. When the stored version doesn't match firmware expectation, the device loads defaults (no destructive migration). The current version is defined in `lib/CONFIG/config.h`.

### Settings Save Behaviour

| Setting | How it saves |
|---|---|
| Band / Channel | Auto-saved on selection |
| RSSI thresholds (sliders) | Staged; saved by "Save RSSI Thresholds" button |
| All Settings tab fields | Staged; saved by "Save Configuration" button |
| Calibration thresholds | Saved immediately by wizard "Apply" button |
| WiFi credentials | Saved by "Apply WiFi & Reboot" button |

The **Save Configuration** button highlights orange with a pulse animation when there are unsaved staged changes. It returns to its inactive (greyed-out) state after a successful save.

### Config Fields

Key config fields stored per device:

- Band, channel, frequency
- Enter RSSI, Exit RSSI
- Min lap time, max laps
- Announcer type, rate, voice, lap format, phonetic name
- Pilot name, callsign, colour
- LED preset, brightness, speed, colours, manual override
- WiFi (AP + home) SSID, password, external antenna, TX power
- RSSI sensitivity
- Pipeline Smoothing level (`v1Smoothing`), Gate-1 Bootstrap toggle
- Multi-node: node mode, master SSID, skip-master-start toggle, preferred slot (client re-requests its last-assigned slot on registration so slots survive reboots), client race-audio opt-in
- OTA: home WiFi credentials, include-prereleases toggle
- Theme, selected voice

---

## OTA Updates

The device pulls release artefacts directly from GitHub Releases. There is no PlatformIO requirement and no manual upload step for normal updates.

### End-User Flow

1. **Settings → Firmware Update** — enter Home WiFi credentials (saved permanently after the first time)
2. Tap **Check for Updates** — the device briefly drops the AP, joins the home network, hits `https://api.github.com/repos/<owner>/<repo>/releases/latest`, and reads the asset list
3. If the published `tag_name` is newer than the installed `firmware_version.h` build, the user is prompted with the version + release notes
4. Tap **Update Now** — the device downloads `FPVRaceOne-littlefs.bin`, flashes the LittleFS partition, then downloads `FPVRaceOne-firmware.bin`, flashes the OTA partition, and reboots once
5. If any download fails, the previous firmware/filesystem is preserved — the device cannot be bricked from a flaky network

### Release Asset Naming

The CI workflow produces two binaries per release:

- `FPVRaceOne-firmware.bin` — application image (flashed to OTA_0/1)
- `FPVRaceOne-littlefs.bin` — filesystem image (flashed to LittleFS)

### Manual Flashing (Recovery)

For first-time setup of new hardware or recovery if the device won't boot, `pio run -e seeed_xiao_esp32c6 -t upload` and `-t uploadfs` are still supported. See [Flash the Firmware](BUILD_FROM_SCRATCH.md#step-5--flash-the-firmware) for the GUI flasher, and [Building the Firmware From Source](BUILD_FROM_SCRATCH.md#building-the-firmware-from-source) for the PlatformIO path.

### Race-Time Safety

Updates are blocked while a race is running. Attempting to start an update during a race returns an error.

---

## Self-Test System

Access via **Settings → Diagnostics → Run System Self-Test**.

The self-test exercises hardware, storage, and software paths and reports pass/fail with detail text. Results can be downloaded as a diagnostic log to attach to a GitHub issue.

Categories covered include EEPROM, LittleFS, WiFi AP / station, lap timer, race history, web server file presence, OTA partition health, RSSI sampling punctuality, per-task CPU load, and the **RSSI Noise Floor** check.

**RSSI Noise Floor** is the one that tells you the receiver is alive and correctly
wired. It samples for one second on the frequency you have configured and reports
the floor, mean and peak against your Exit threshold. There is no SPI readback on
an RX5808, so a genuine noise signature is the available evidence that the module
is powered, tuned and reaching the ADC — which is why this replaced the two band
sweeps that used to sit here. Those blocked the web server for 2.16 s and, on a
test rig, were actually measuring the emulator's DAC rather than the receiver.

---

## Observability (Serial Log)

The firmware emits five structured log streams to the USB-CDC serial port,
all tagged so a postmortem grep is easy:

| Tag | Cadence | Format |
|---|---|---|
| `[HEAP]` | Every 10 s | `free=N min=N maxBlk=N sta=N sse=N` — current free heap, minimum-ever free, largest contiguous block, AP station count, attached SSE clients. Low-heap watchdog auto-reboots when `free < 20 KB` or `maxBlk < 8 KB` for 10 seconds straight |
| `[AP]` | On event | `STA connected/disconnected: <mac>  (now N stations)` — every AP-level association/disassociation. Non-client station disconnects also trigger an SSE eviction line to reclaim heap from orphaned `EventSource` clients |
| `[CORE0]` | Every 10 s + on-event | `window 10s: longest sub-call <name>=<ms>, longest tick gap=<ms>` — names the slowest sub-call seen in the last 10 seconds and the worst gap between iterations. A per-call line fires immediately if any single sub-call takes ≥ 100 ms |
| `[MULTINODE] connected:` | Every 10 s | `A=Sam B=Bob C=Lenny ...` — slot letter + pilot name for every currently-online client. `(none)` if nobody is connected |
| `[MULTINODE]` events | Immediate | `New node X (...)`, `Re-registered node X (...)`, `Updated node X (...)`, `Node X (Pilot) timed out`, `Node X (Pilot) reconnected via heartbeat`, `Node X (Pilot) quit early`, `Node X (Pilot) manually removed`. Slot is shown as a letter (A–G), matching the UI |

Steady-state keep-alive registrations are **silent** — only first-time
joins, recoveries from offline, and changes to user-visible identity
fields produce a line. This keeps the trace usable as a problem
detector instead of a firehose.

### Director-state broadcast throttle

Director-state mirror pushes to clients are rate-limited to **once per
2 seconds** so a burst of state changes coalesces into a single push
instead of stacking up. Race-critical broadcasts (pre-arm, start, stop)
are **not** throttled — their timing matters more than mirror updates.

---

## Technical Architecture

### Firmware Structure

```
src/
└── main.cpp              — Entry point; sampling loop on Core 1, WiFi/HTTP on Core 0

lib/
├── CONFIG/               — Configuration struct, EEPROM, serialisation
├── DEBUG/                — Debug logger (web-streamed, no hot-path delays)
├── KALMAN/               — Kalman filter (unused; not in the detection path)
├── LAPTIMER/             — Single 5-stage filter pipeline + gate state machine + lap events
├── RX5808/               — RX5808 SPI driver and ADC read
├── MULTINODE/            — Master/client coordination (heartbeats, broadcasts, quit notifications)
├── OTA/                  — GitHub-Releases-driven over-the-air update flow
├── WEBSERVER/            — ESPAsyncWebServer HTTP + SSE
└── ...
```

Other library directories (`RACEHISTORY`, `TRACKMANAGER`, `USB`, …) compile in but are inert on the current C6 product configuration — they're carried for future hardware revisions that may have an SD card, dedicated race-history partition, or a need for a host-side USB control protocol.

### Web Interface

```
data/
├── index.html            — Single-page application
├── style.css             — Responsive styles, multiple themes, save-button dirty state
├── script.js             — UI logic, staged config, race control, calibration, multi-node
├── audio-announcer.js    — Browser Web Speech API wrapper for lap announcements
└── smoothie.js           — Live RSSI chart library
```

### Two-Core Architecture

| Core | Responsibilities |
|---|---|
| Core 1 (main loop) | RSSI sampling, full filter pipeline, gate detection, lap events, audio |
| Core 0 (parallel task) | WiFi stack, HTTP server, SSE streaming, multi-node POSTs, OTA download |

Network calls run on Core 0 specifically so they never stall RSSI reads during lap events.

### SSE Streaming

The browser receives several streams of Server-Sent Events:
- Live RSSI samples (high-frequency)
- Race state changes (`raceState`, `masterRaceState`)
- Multi-node node updates (`multiNodeState`)
- Debug log lines (when the diagnostics tab is open)

SSE is one-way (server → client) and avoids WebSocket overhead for the high-frequency RSSI feed.

### Memory Layout (XIAO ESP32-C6)

| Partition | Size | Contents |
|---|---|---|
| Bootloader | ~32 KB | ESP32 bootloader |
| Partition table | 4 KB | Partition layout |
| OTA_0 (App0) | 2 MB | Primary firmware |
| OTA_1 (App1) | 2 MB | OTA update staging |
| LittleFS | ~1.5 MB | Web files, race history, audio |

---

**Questions or issues? [Open a GitHub issue](https://github.com/ramiss/FPVRaceOne/issues)**

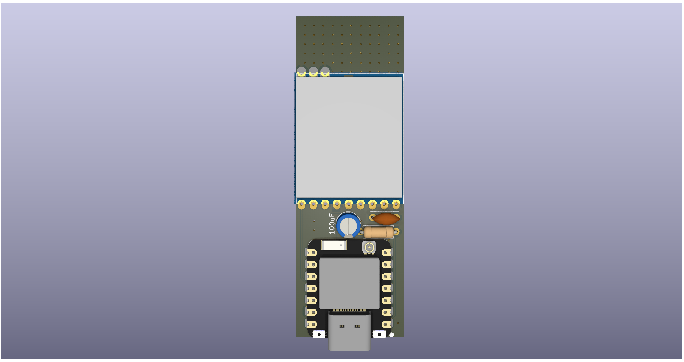
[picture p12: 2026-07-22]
Schematic/FPVRaceOne_top.png

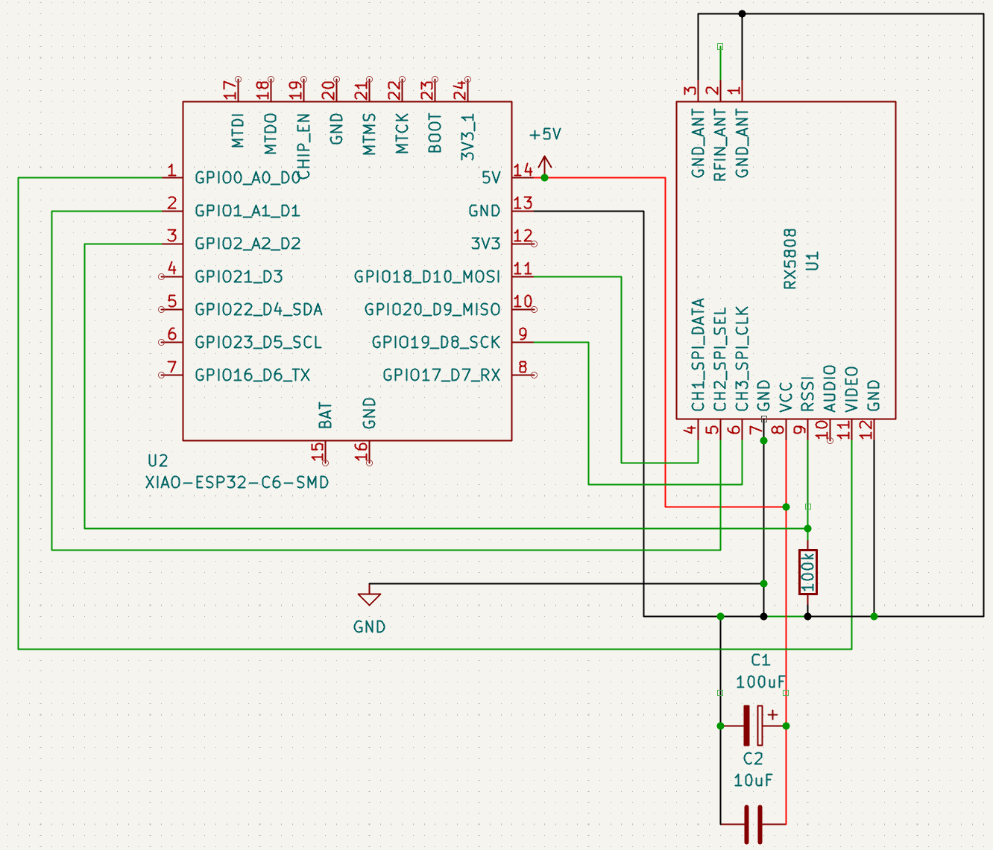
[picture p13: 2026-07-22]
Schematic/Schematic_v1_20260722.png

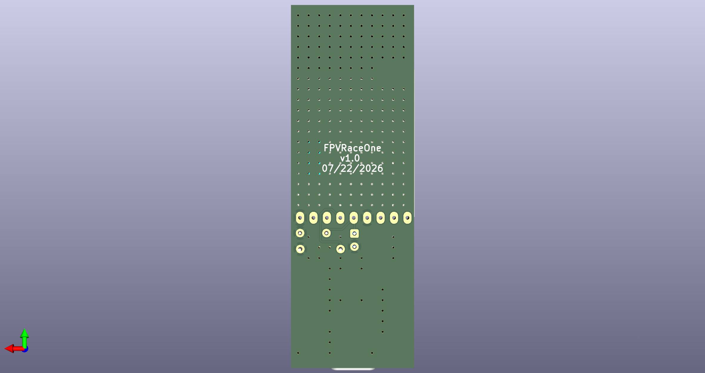
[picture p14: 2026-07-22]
Schematic/FPVRaceOne_rear.png

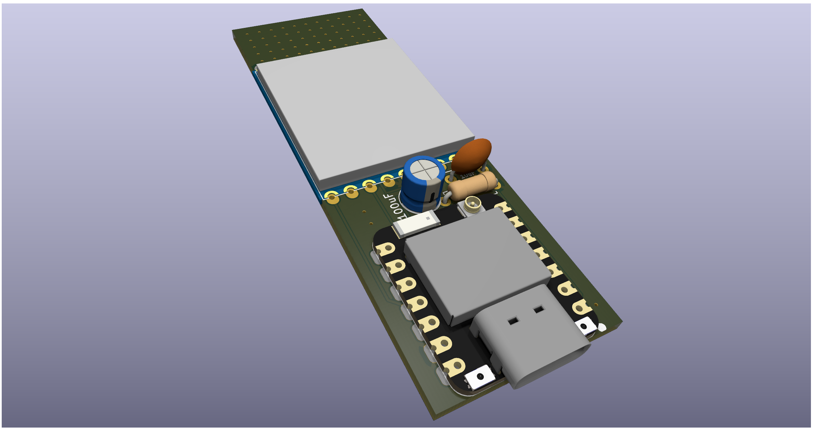
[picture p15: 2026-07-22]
Schematic/FPVRaceOne.png

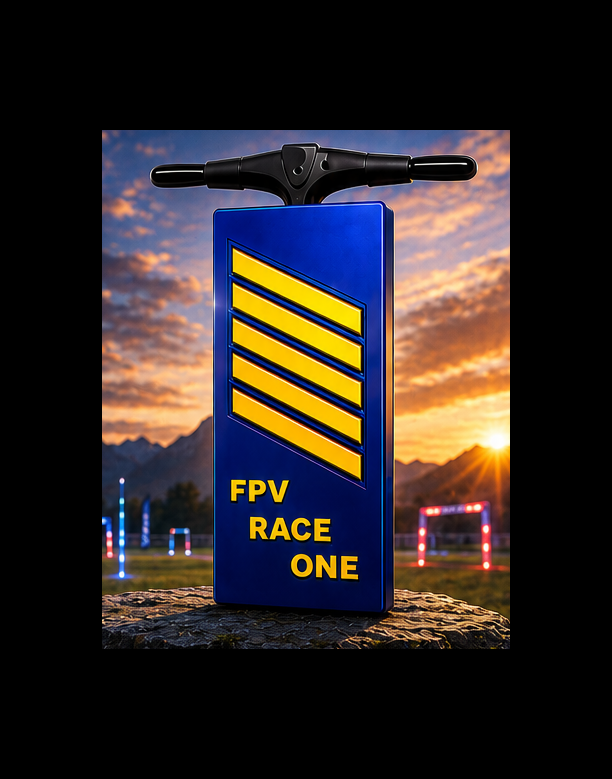
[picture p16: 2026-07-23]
images/product_files/FPVRaceOne_Hero_bg.png

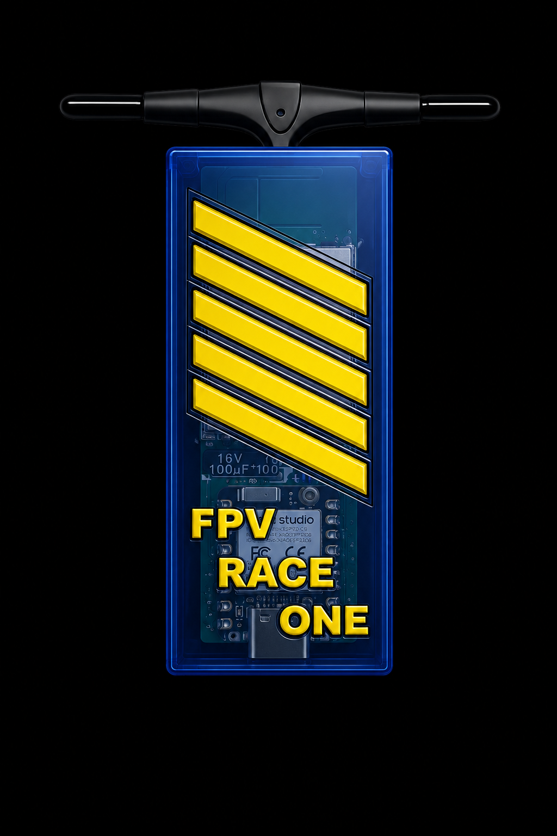
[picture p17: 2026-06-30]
images/product_files/FPVRaceOne-Transparent.png

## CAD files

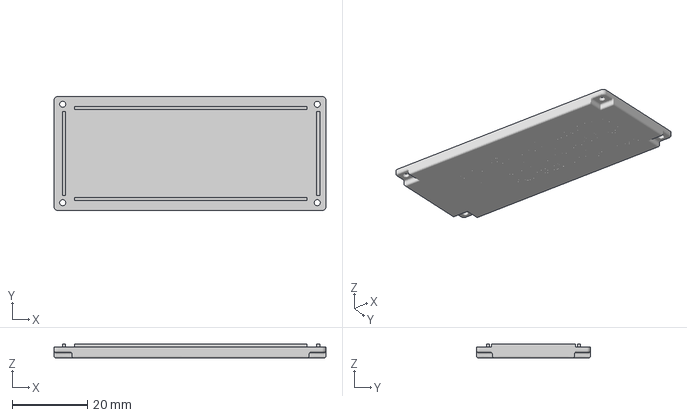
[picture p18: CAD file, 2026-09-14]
case/Bottom.3mf
72.4 x 30.4 x 3.75 mm

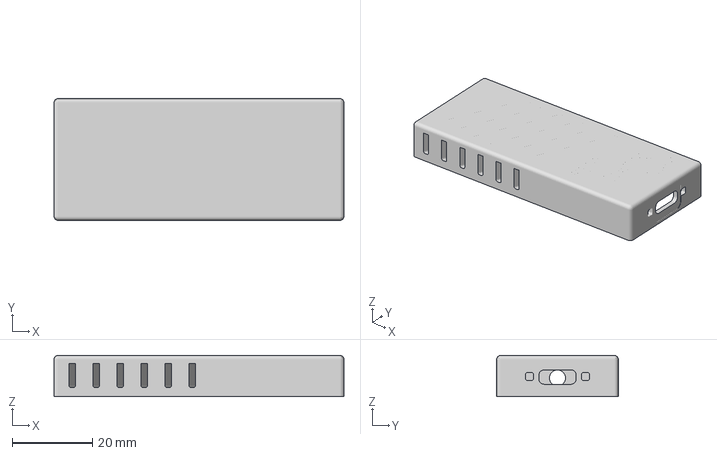
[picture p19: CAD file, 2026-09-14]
case/Top.3mf
72.4 x 30.4 x 10.2 mm

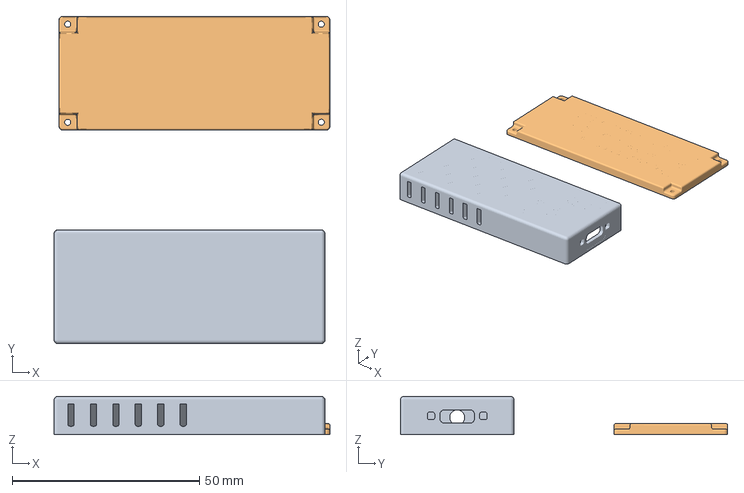
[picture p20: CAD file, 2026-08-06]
case/FPVRaceOne_Case_20260730_ironed.3mf
73.7 x 87.5 x 10.3 mm
Top
Bottom

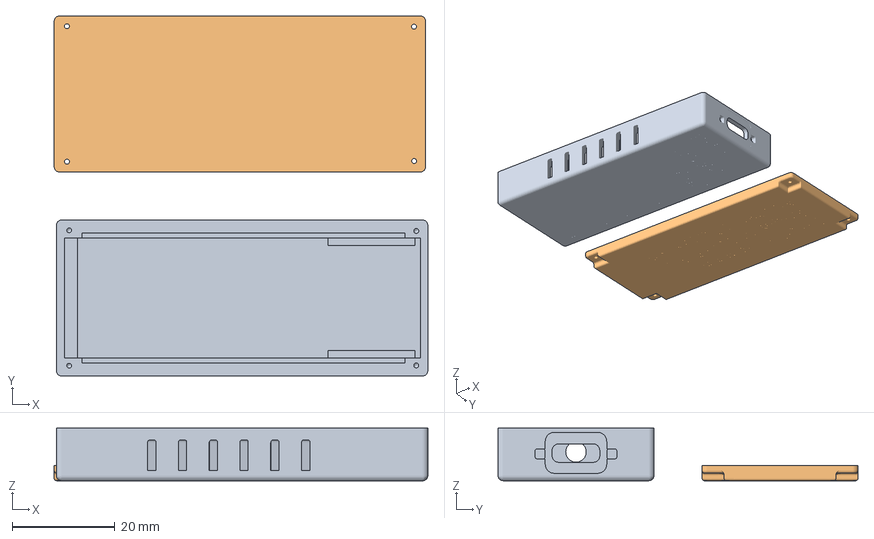
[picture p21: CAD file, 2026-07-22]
case/FPVRaceOne_Case_20260722.3mf
72.8 x 70.2 x 10.2 mm
Top
Bottom

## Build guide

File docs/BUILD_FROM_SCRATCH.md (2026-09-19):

# Build an FPVRaceOne From Scratch

How to build your own FPVRaceOne lap timer from parts — wiring, assembly, and
flashing.

**Navigation:** [Home](../README.md) | [Getting Started](GETTING_STARTED.md) | [User Guide](USER_GUIDE.md) | [Flashing](#step-5--flash-the-firmware)

> Don't want to build one? A fully assembled, flashed and cased unit is
> available at the [FPVWidgets store](https://fpvwidgets.square.site).

**Note: you will need a Windows pc or laptop to use our free firmware flasher** ... or use a 3rd party ESP32 flasher or build the firmware yourself (see bottom of this page)

---

## Table of Contents

1. [What You'll Need](#what-youll-need)
2. [Step 1 — Put the RX5808 in SPI Mode](#step-1--put-the-rx5808-in-spi-mode)
3. [Step 2 — Wiring](#step-2--wiring)
4. [Step 3 — The Support Components](#step-3--the-support-components)
5. [Step 4 — Check Before You Power It](#step-4--check-before-you-power-it)
6. [Step 5 — Flash the Firmware](#step-5--flash-the-firmware)
7. [Step 6 — First Power-On](#step-6--first-power-on)
8. [Step 7 — Verify the Build](#step-7--verify-the-build)
9. [The 3D-Printed Case](#the-3d-printed-case)
10. [Fitting your build in the case](#fitting-your-build-in-the-case)
11. [Building the Firmware From Source](#building-the-firmware-from-source)
12. [Troubleshooting](#troubleshooting)

---

## What You'll Need

### Parts

| Qty | Part | Notes |
|----:|---|---|
| 1 | **Seeed Studio XIAO ESP32-C6** | The only supported board. Not the C3, S3, or nRF variants — the pin map and the 160 MHz timing budget are specific to the C6 |
| 1 | **RX5808 5.8 GHz receiver module** | **Must be SPI-capable** — see [Step 1](#step-1--put-the-rx5808-in-spi-mode) |
| 1 | **R1 — 100 kΩ resistor** | ¼ W or smaller; pulls the RSSI line down |
| 1 | **C1 — 100 µF electrolytic capacitor** | 10 V or higher, across the RX5808 supply |
| 1 | **C2 — 10 µF capacitor** | Electrolytic or ceramic, across the RX5808 supply |
| 1 | **5.8 GHz antenna** | Fits the u.FL / IPEX connector on the edge of the RX5808 module |
| 1 | **2.4 GHz WiFi antenna, u.FL / IPEX** | For the **XIAO's** connector — see [Step 3](#step-3--the-support-components). Not optional: the firmware switches the radio to this connector at boot. A XIAO ESP32-C6 usually ships with one in the box |
| — | **Silicone wire, 28–30 AWG** | Seven short runs; fine stranded wire is much kinder to the RX5808 pads |
| 1 | **USB-C cable and a power source** | Any phone charger or USB power bank. See [Getting Started](GETTING_STARTED.md#what-you-need) for runtime estimates |
| 1 | **Printed case** *(recommended)* | Ready-to-slice `.3mf` files in [`case/`](../case/) — see [The 3D-Printed Case](#the-3d-printed-case). PETG; prints without supports |

### Tools

- A fine-tip soldering iron (a chisel tip will bridge the RX5808 pads)
- Flux, solder, tweezers
- A multimeter — used for the continuity check in [Step 4](#step-4--check-before-you-power-it), which is the one step that stops a wiring
  mistake from becoming a dead module
- A hot-air station or a second iron, if your RX5808 needs the SPI conversion

### Skill level

Soldering to the RX5808's castellated edge pads is the hard part. The pads are
small and close together, and the module's ground plane pulls heat away. If
you've reflowed a 0603 part or repaired a flight controller, you'll be fine.

---

## Step 1 — Put the RX5808 in SPI Mode

**FPVRaceOne sets the receive frequency over SPI.** A module still in its
default hardware-channel mode will power up and produce an RSSI reading, but it
will sit on whatever channel its jumpers select and ignore every band/channel
change you make in the web UI — so laps get timed on the wrong frequency, or
not at all.

Many modules manufactured in the last few years ship SPI-ready, but there is no
way to tell from the listing and no guarantee from the seller. **The conversion
is the removal of a single resistor**, arrowed in the photo at the bottom of the
wiring diagram below.

1. Remove the metal shield can by heating the solder on the edges of the can and carefully lifting the can.
2. Find the resistor arrowed in the diagram (bottom of wiring diagram below), along the bottom edge of the board
   near the crystal.
3. Remove it with hot air, or by walking a fine iron tip back and forth across
   both ends with plenty of flux until it lets go. 

Take your time. There are parts either side of it, and a slip here ends the
module.

---

## Step 2 — Wiring

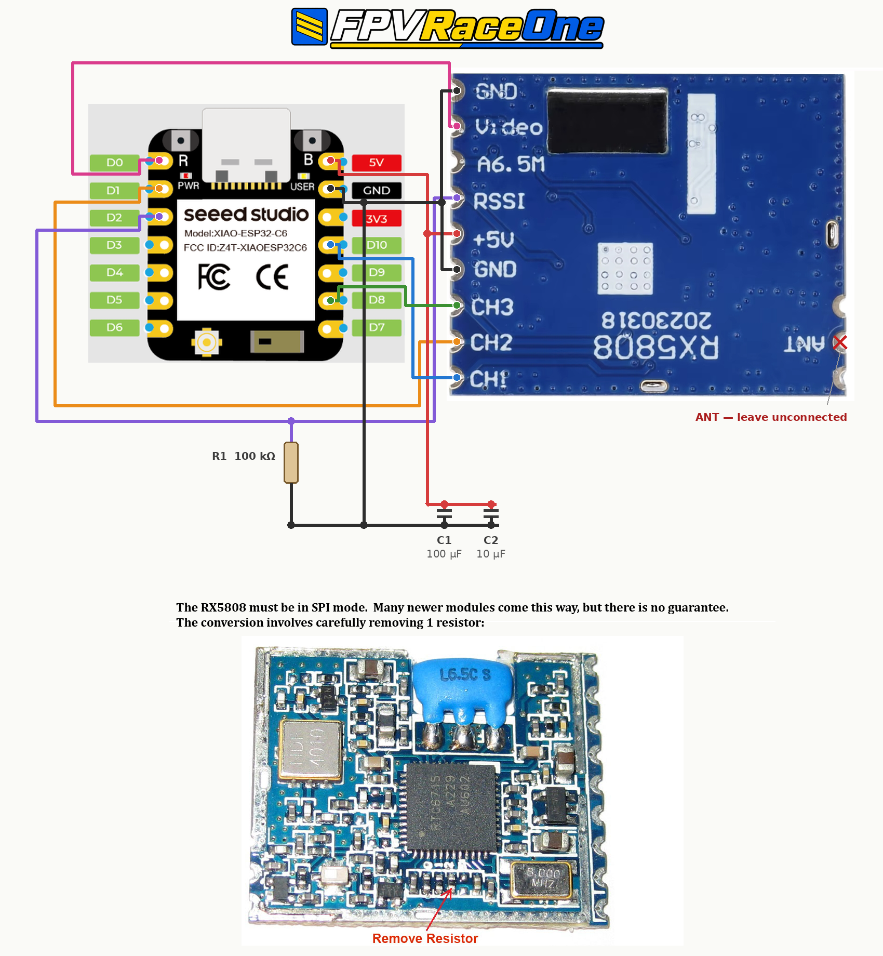
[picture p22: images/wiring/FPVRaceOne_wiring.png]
FPVRaceOne wiring diagram


Seven connections. The wire colours below match the diagram.

| Wire | XIAO ESP32-C6 | RX5808 pad | What it carries |
|---|---|---|---|
| 🔵 Blue | **D10** | **CH1** | SPI data |
| 🟠 Orange | **D1** | **CH2** | SPI select (latch enable) |
| 🟢 Green | **D8** | **CH3** | SPI clock |
| 🟣 Purple | **D2** | **RSSI** | Analog signal strength — this is the one that times your laps |
| 🔴 Red | **5V** | **+5V** | Module power |
| ⚫ Black | **GND** | **GND** | Ground — the RX5808 has two GND pads; the diagram uses the one beside +5V |
| 🩷 Pink | **D0** | **Video** | (Shown for completeness). **Optional** — the firmware currently does not use the video feed |

Note:
- **Power the module from USB (5V), not the 3V3 pads.** The RX5808 needs the full 5 V rail.
  The XIAO passes USB 5 V straight through to its `5V` pad, so a USB-C supply
  feeds the ESP32 and RX5808 module directly.
- **Leave the RX5808's `ANT` pad unconnected** — it's marked with a red ✗ on the
  diagram. Your 2.4 GHz antenna goes on the u.FL connector at the ESP32.

**IMPORTANT! The ESP32 needs its own 2.4 GHz antenna**
The firmware uses the ESP32's external u.FL connector at boot to enable a smooth web experience in noisy track environments, so
without an antenna fitted, the ESP32 radio is driving an open connector at full power and could be damaged. Details
in [Step 3](#step-3--the-support-components).

---

## Step 3 — The Support Components

None of these is optional. Without R1 and the capacitors the RSSI trace wanders
and the calibration wizard produces thresholds that don't hold; without the WiFi
antenna the web UI is barely usable at the far end of a track.

**R1 — 100 kΩ, from the RSSI wire to ground.** Connect it anywhere along the
purple line: one leg on the D2 / RSSI net, the other on the ground rail. It
holds the input at a known level instead of letting it float, which is what
keeps your noise floor flat when no VTX is transmitting.

**C1 (100 µF) and C2 (10 µF) — both across the RX5808 supply**, positive leg on
the red 5 V rail, negative leg on the black ground rail. Put them as close to
the module's `+5V` and `GND` pads as the build allows. The receiver's current
draw is lumpy; these keep that off the rail the ADC is measuring against.
Observe polarity on the electrolytics.

### The two antennas

This build has **two** antennas and they are treated differently:

| Connector | Antenna | Carries |
|---|---|---|
| On the **RX5808** module edge | 5.8 GHz | The video signal being timed |
| On the **XIAO ESP32-C6** | 2.4 GHz | The WiFi the web UI runs over |

**Fit a 2.4 GHz antenna to the XIAO.** The firmware drives the C6's RF switch
over to the external connector during boot, before WiFi starts. That is a
deliberate choice: the onboard ceramic antenna is fine on a bench, but at a track
you are walking a phone or laptop away from a timer that may be strapped high on
a gate, and the external antenna is what keeps the UI responsive at that range.

This is **not a setting you can turn off.** FPVRaceOne treats the external
antenna as part of the hardware definition — the value is pinned on and the
Settings toggle for it is hidden, precisely so a unit can't be left transmitting
into a connector that has nothing attached. Build accordingly: no antenna on the
XIAO means the radio is driving an open connector, and your usable range
collapses to a few metres.

u.FL connectors are fragile and rated for only a handful of mating cycles. Press
the plug straight down until it clicks; don't rock it on, and don't pull on the
cable to remove it.

**Leave the RX5808 antenna pad unconnected** You want the 5.8Ghz video detection to be close range only, so do not connect an antenna to the module.

---

## Step 4 — Check Before You Power It

Do this with the multimeter, before anything is plugged in. It takes two
minutes and it's the difference between a working timer and a dead RX5808.

1. **5V to GND** — no continuity. A short here kills the module the instant you
   plug in USB
2. **Each signal pin to its pad** — continuity on all four: D10↔CH1, D1↔CH2,
   D8↔CH3, D2↔RSSI
3. **Each signal pin to its neighbours** — no continuity. Bridged CH pads are
   the most common failure on this build
4. **Electrolytic polarity** — negative stripe to ground on both C1 and C2
5. **D2 to GND** — should read about 100 kΩ, which confirms R1 is actually in
   circuit

---

## Step 5 — Flash the Firmware

Brand-new hardware has no bootloader, no partition table and no filesystem, so
it needs a **Recovery**-mode flash — the full image written from offset 0x0. The
FPVRaceOne Flasher does this in one click; updates after this first flash can
be done over the air from the web UI.

### Get the flasher (Windows only)

Download **[FPVRaceOne-Flasher.exe](https://github.com/ramiss/FPVRaceOne-Flasher/releases/latest/download/FPVRaceOne-Flasher.exe)**
(Windows, portable — no installer). The link always resolves to the current
build, which then lets you pick any published firmware release.

### Flash it

1. **Plug the XIAO into your computer with a USB-C data cable.** Charge-only
   cables are the number one cause of "no devices found" — if nothing appears in
   Step 4 below, try a different cable first
2. **Run `FPVRaceOne-Flasher.exe`.** Windows SmartScreen may warn about an
   unrecognised publisher; choose *More info → Run anyway*
3. Under **Firmware source**, leave **Download from GitHub** selected
4. Under **Devices (ESP32)**, confirm your board is listed and ticked — it shows
   as something like `COM7 — USB Serial Device`. Click **Refresh** if it isn't
   there
5. Under **Version**, pick the release you want. The newest is at the top. Tick
   **Include pre-releases (beta)** only if you're deliberately testing one
6. Under **Flash mode**, select **Recovery — full reflash for a bricked device
   (merged + filesystem)**. This is the correct mode for new hardware: it writes
   the bootloader, partition table and filesystem, which Update mode leaves
   alone
7. Click **Flash**. The log pane shows the download, then the erase and write.
   It takes about a minute
8. Wait for the success line, then unplug and replug the device

> **If the flasher can't connect**, put the C6 into bootloader mode by hand:
> hold the **B** (boot) button, tap **R** (reset), then release **B**. The two
> buttons flank the USB connector — they're labelled on the diagram above.
> Click **Refresh**, then **Flash** again.

### Update vs Recovery mode

You only need Recovery once. After that the device updates itself over the air
from **Settings → Firmware Update** — no cable, no tools. Manual flashing is for
new hardware, a device that won't boot, or local development.

| Mode | Writes | Use it for |
|---|---|---|
| **Update** | `FPVRaceOne-firmware.bin` (app at `0x10000`) + `FPVRaceOne-littlefs.bin` (filesystem at `0x380000`) | Normal manual reflash. Leaves the bootloader and partition table alone, and **keeps your settings** |
| **Recovery** | `FPVRaceOne-merged.bin` (full image at `0x0` — bootloader, partition table, boot_app0, firmware) + the filesystem | New hardware, or a device whose bootloader or partition table is corrupt |

**Recovery erases every saved setting** — band, channel, calibration, pilot name,
WiFi credentials — because it overwrites the whole flash. On a board you're
building that's exactly what you want. On a configured unit, use Update.

**Update mode migrates the partition layout for you.** The layout changed in
2026-08 (the app partitions grew by reclaiming unused filesystem space). A unit
flashed before that keeps its old table, because neither an over-the-air update
nor a normal Update-mode flash rewrites the partition table. You don't have to do
anything about this: Update mode reads the table off the device first, and if it's
out of date it writes the new table plus a boot-selector reset before the
firmware, saying so in the log. Your settings survive — that path doesn't touch
NVS.

Two safeguards worth knowing about:

- If the table can't be read, the flasher flashes normally rather than guessing.
  It only rewrites on a *confirmed* mismatch.
- Releases published after the change use manifest schema 2, so an **older
  flasher build refuses them outright** with "please update the tool" instead of
  writing images to offsets your device doesn't recognise. If you see that
  message, download the current flasher.

The device tells you too: if an over-the-air update can't fit your unit's
partitions, the Firmware Update page says so and points you here.

---

## Step 6 — First Power-On

1. Check the **2.4 GHz antenna is on the XIAO's u.FL connector** before you power
   up — the radio switches to it during boot
2. Power the device from USB-C and wait 10–15 seconds
3. On your phone or laptop, look for the WiFi network **`FPVRaceOne_XXXX`**
   (XXXX = the last 4 digits of the device's MAC address)
4. Password: **`fpvraceone`**
5. Open **`http://192.168.4.1`** in a browser

If the access point appears and the page loads, the XIAO half of the build is
good.

Then walk away from it. A unit with its WiFi antenna fitted should hold a
connection across a typical track; if you lose the page after ten or fifteen
metres, the antenna is the first thing to check — a missing or half-seated u.FL
plug still gives you a strong signal standing next to the timer, so this only
shows up at range.

---

## Step 7 — Verify the Build

The firmware can tell you whether the receiver is actually wired correctly —
you don't have to guess.

1. Attach the 5.8 GHz antenna to the RX5808's u.FL connector
2. In the web UI, go to **Settings → Diagnostics**
3. Click **Run System Self-Test**

Read the **RSSI Noise Floor** result. It samples the receiver for one second on
your currently configured frequency and reports the floor, mean and peak:

- **A plausible floor and mean, comfortably below your Exit threshold** — the
  RX5808 is powered, in SPI mode, tuned where you asked, and its RSSI output is
  reaching D2. The build is good.
- **A flat reading of 0, or a value pinned at the top of the range** — the RSSI
  wire, R1, or the module's power is wrong. Go back to
  [Step 4](#step-4--check-before-you-power-it).
- **A noise floor sitting at or above your Exit threshold** — either the bench
  is genuinely noisy (a powered VTX in the room will do it), or the module never
  took the SPI frequency and is parked on a busy channel. Power down any nearby
  VTX and re-run before suspecting the wiring.

Then set your band and channel in **Settings**, and run the **Calibration
Wizard** — [Getting Started](GETTING_STARTED.md#run-the-calibration-wizard) walks
through it.

---

## The 3D-Printed Case

Printable files live in **[`case/`](../case/)**. The enclosure is two parts — a
**Top** and a **Bottom** — and everything in the folder is some arrangement of
those two.

| File | Contains | Use it when |
|---|---|---|
| **[`FPVRaceOne_Case_20260730.3mf`](../case/FPVRaceOne_Case_20260730.3mf)** | Top + Bottom, one complete case, with print settings | **Start here.** One timer, ready to slice |
| **[`FPVRaceOne_Case_20260730_ironed.3mf`](../case/FPVRaceOne_Case_20260730_ironed.3mf)** | Same case, ironing enabled on top surfaces | You want a smoother lid — costs extra print time |
| **[`FPVRaceOne_Case_20260730_x4.3mf`](../case/FPVRaceOne_Case_20260730_x4.3mf)** | Four complete cases (8 parts) on one plate | Building several timers for a multi-node setup |
| **[`Top.3mf`](../case/Top.3mf)** / **[`Bottom.3mf`](../case/Bottom.3mf)** | Bare geometry, one part each, no print settings | Reprinting a single half, or bringing the model into another slicer / CAD tool |

### Print settings

The three `FPVRaceOne_Case_*` files are **Bambu Studio projects** — open one and
the settings below come with it, already configured:

| Setting | Value |
|---|---|
| Printer profile | Bambu Lab A1 mini, 0.4 mm nozzle |
| Layer height | 0.08 mm |
| Walls | 3 |
| Infill | 30 % |
| Supports | **Off** — the parts are designed to print without them |
| Brim | None |
| Filament | PETG (slot 1) |

Nothing here is exotic apart from the fine 0.08 mm layer height, so any 0.4 mm
FDM printer will manage it. On a different machine, load `Top.3mf` and
`Bottom.3mf` into your own slicer and carry those values across — supports off
and no brim are the two worth keeping.

PETG is the recommended material: a timer sits out in the sun on a gate all day,
and PLA softens at temperatures a black case reaches easily.

## Fitting your build in the case

The case is designed around a compact board layout, so a hand-wired build needs
to be tidy to close up. Worth planning before you solder:

- Keep the wire runs between the XIAO and the RX5808 as short as the diagram
  allows — long loops are what stop the halves meeting.
- Put R1 and the two capacitors close to the pads they serve (also better
  electrically, see [Step 3](#step-3--the-support-components)) rather than out
  on flying leads.
- Route both antenna pigtails out before you seat the boards; a u.FL lead
  trapped under a board is the usual reason a lid won't sit flat.

If it won't quite close, print the case at 100 % and check your wire gauge
first — 28-30 AWG silicone is specified in the parts list for exactly this
reason, and thicker wire is the most common culprit.

---

## Building the Firmware From Source

Optional — the released binaries in Step 5 are the same thing. You'd do this to
modify the firmware.

You'll need [PlatformIO](https://platformio.org/) (the VS Code extension, or
the standalone CLI).

```bash
git clone https://github.com/ramiss/FPVRaceOne.git
cd FPVRaceOne

# Firmware
pio run -e seeed_xiao_esp32c6 -t upload

# Web UI filesystem — required, and separate from the firmware
pio run -e seeed_xiao_esp32c6 -t uploadfs
```

Both steps are needed: `upload` writes the application, `uploadfs` writes the
LittleFS image holding the web UI. Flash the firmware without the filesystem
and the device boots but serves nothing.

There is also a **`seeed_xiao_esp32c6_release`** environment. It's the same
build with the bench instrumentation compiled out (`HARNESS_LOG_ENABLED=0`,
`TIMING_MARKER_ENABLED=0`) and is what published releases are built from. Use
it for anything you intend to fly:

```bash
pio run -e seeed_xiao_esp32c6_release -t upload
pio run -e seeed_xiao_esp32c6_release -t uploadfs
```

---

## Troubleshooting

| Symptom | Likely cause |
|---|---|
| No `FPVRaceOne_XXXX` WiFi network after 20 s | Firmware didn't flash, or the filesystem image is missing. Reflash in Recovery mode |
| WiFi appears but `192.168.4.1` doesn't load | Filesystem not written. Recovery mode writes both — Update mode after a failed firmware-only flash will not |
| WiFi is strong next to the timer but drops a few metres away | No antenna on the **XIAO's** u.FL, or the plug isn't fully clicked down. The firmware always uses the external connector, so an open one gives you a usable signal only at arm's length |
| Band/channel changes work but WiFi range is poor | The two antennas are swapped — 5.8 GHz belongs on the RX5808, 2.4 GHz on the XIAO |
| Flasher shows "no ESP32 devices found" | Charge-only USB cable, or the board needs manual bootloader mode (hold **B**, tap **R**, release **B**) |
| Flasher reports "please update the tool" | The release uses a newer manifest than your flasher build. Download the current `FPVRaceOne-Flasher.exe` |
| Self-test RSSI reads a flat 0 | RSSI wire not on **D2**, R1 missing, or the RX5808 has no 5 V |
| RSSI reads high and never moves | RSSI line shorted to 5 V, or R1 wired to the wrong net |
| Band/channel changes have no effect on RSSI | The RX5808 is not in SPI mode — revisit [Step 1](#step-1--put-the-rx5808-in-spi-mode) |
| Noise floor close to the Exit threshold | A powered VTX nearby, or the module is parked on a busy channel because SPI never took |
| Laps detected erratically or not at all | Re-run the Calibration Wizard. If it still misbehaves, check C1/C2 are present and close to the module |

---

**[← Back to README](../README.md)**

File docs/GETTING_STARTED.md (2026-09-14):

# Getting Started with FPVRaceOne

Complete guide to setting up and configuring your FPVRaceOne lap timer.

**Navigation:** [Home](../README.md) | [User Guide](USER_GUIDE.md) | [Features](FEATURES.md)

---

## Table of Contents

1. [What You Need](#what-you-need)
2. [Connect to FPVRaceOne](#connect-to-fpvraceone)
3. [Configure Your VTx Frequency](#configure-your-vtx-frequency)
4. [Set Pilot Information](#set-pilot-information)
5. [Run the Calibration Wizard](#run-the-calibration-wizard)
6. [First Race](#first-race)
7. [Multi-Node Racing (Optional)](#multi-node-racing-optional)
8. [Firmware Updates (OTA)](#firmware-updates-ota)
9. [Tips](#tips)
10. [Troubleshooting](#troubleshooting)
11. [Default Settings Reference](#default-settings-reference)

---

## What You Need

1. A pre-flashed FPVRaceOne lap timer and a phone, tablet, or laptop with WiFi
2. Any USB-C compatible battery bank or power supply (not included). If you'd
   rather run off your LiPo / Li-ion packs, search "USB-C Power Supply Cable
   for GoPro" — there are adapters in the ~$10 range

**Battery life estimates:**

| USB power bank | Approximate runtime |
|---|---|
| 1000 mAh | 1.5 – 2.5 hours |
| 2000 mAh | 3 – 5 hours |
| 5000 mAh | 8 – 12 hours |

The USB-C connector is used for **power and manual flashing** only. All
racing, calibration, and configuration happens through the WiFi web UI.

---

## Connect to FPVRaceOne

### WiFi (Default)

1. Power on your FPVRaceOne lap timer device and wait 10–15 seconds
2. Place the timer at the timing gate (typically the first gate), with the stripes (front of the unit) facing inwards towards the center of the gate (facing the drone as it passes)
   Note: make sure the timer has a clear line of sight to your browsing device.  You may need to attach it higher on the gate if there is grass or other obstacles in the way.  
3. On your phone or laptop, connect to the WiFi network: **`FPVRaceOne_XXXX`**  
   *(XXXX = last 4 digits of the device MAC address)*
4. Password: **`fpvraceone`**
5. Open a browser and go to: **`http://192.168.4.1`**

> Most mobile devices can connect to FPVRaceOne WiFi and maintain cellular internet simultaneously. Unfortunately, Samsung phones force a choice between local WiFi and cellular data; everything else lets both coexist.

The USB-C connector on the device is used for **power** and for **manual flashing** if needed. There is no user-facing USB control protocol in the current firmware — all racing, calibration, and configuration happens through the WiFi web UI.

---

## Configure Your VTx Frequency

1. Open the **Settings** tab (gear icon)
2. In the **Pilot Info** section, select your **Band** and **Channel** to match your drone's VTx
3. The frequency (MHz) updates automatically below the selector
4. The band/channel change is **auto-saved** immediately

**Common setups:**

| System | Band | Example |
|---|---|---|
| Analog 5.8 GHz | RaceBand (R) | R1 = 5658 MHz |
| DJI O3 / O4 | DJI O3/O4-20 | 5669–5912 MHz |
| HDZero | HDZero-R | 5658–5917 MHz |
| Walksnail | WLKSnail-R | 5658–5917 MHz |

---

## Set Pilot Information

In the **Pilot Info** section:

| Field | Description |
|---|---|
| **Pilot Name** | Full name — used in voice announcements and race records |
| **Callsign** | Short display name (max 10 chars) — shown in the UI |
| **Phonetic Name** | How TTS pronounces your name |
| **Pilot Color** | Your racing color, used in race history and display |

In the **TTS Settings** section, choose your **Announcer Type** and **Lap Announcement Format**. Lap announcements are spoken by the browser's built-in voice, so the actual voice depends on the device you have the web UI open on — no audio files live on the device itself.

All settings in the Settings panel are **staged** until you click **Save Configuration** (the button highlights orange when there are unsaved changes).

---

## Run the Calibration Wizard

Proper calibration is the most important step for accurate timing.

### Step 1: Launch the Wizard

1. Navigate to the **Calibration** tab
2. Click **"Start Calibration Wizard"**

### Step 2: Record a Fly-Over

1. Power on your drone and let the VTx warm up for 30 seconds
2. Important: set your VTX to a fixed power level (not auto / dynamic)
3. Read the instructions on screen and get into position. **Nothing is recorded
   until you press Start Recording**, so there's no rush here
4. Click **Start Recording** — the button turns red and becomes **Stop Recording**,
   and a live sample count appears
5. Fly your drone through the gate at race speed — **exactly 3 passes** is ideal.
   Fly through the start gate to the next gate and back through the start gate (x3).
6. Click **Stop Recording**

Recording stops on its own at **100 seconds** if you don't. If the timer is short
on memory it grants a shorter window and says so on screen before you start.

The wizard auto-detects the three highest peaks and overlays them on the chart. If detection misses one, drag a marker manually.

### Step 3: Review the Peak-Spread Check

If the three peaks differ in height by more than ~15 %, the wizard shows a warning recommending you re-fly. Equal-height peaks calibrate better — re-flying takes 30 seconds and is almost always worth it. If the spread is acceptable, just continue.

### Step 4: Apply

The wizard calculates thresholds with conservative safety margins:

- **Enter RSSI** ≈ 95 % of the *weakest* of the three peaks (~5 % headroom for lap-to-lap variation)
- **Exit RSSI** = Enter − 4 (tight hysteresis tuned for close-pattern tracks; raised above the recording's noise floor if needed)

Tap **Calculate Thresholds** and the wizard works the values out and **saves them
to the timer straight away** — you don't have to confirm anything to keep them.
The results screen tells you it saved; close it with **Done**.

To fine-tune afterwards, adjust the Enter/Exit sliders on the Calibration tab and
press **Save RSSI Thresholds**. (If the automatic save fails — a client that
dropped off the network, say — the screen says so in red and leaves an **Apply
Thresholds** button to retry.)

### Step 5: Verify

Watch the live RSSI chart on the Calibration tab while flying one or two more passes. You should see a clean peak well above Enter, then drop below Exit on the way out. If detection misses or fires twice, see *Missing Laps* / *False Laps* in the troubleshooting section.

---

## First Race

1. Navigate to the **Race** tab
2. Click **"Start Race"**
3. Listen for the countdown and start beep
4. Fly through the gate — the first pass is recorded as **Gate 1 (hole shot)**
5. Subsequent passes are recorded as **Lap 1, Lap 2**, etc.
6. Click **"Stop Race"** when finished — the race is saved automatically

**[Full racing guide →](USER_GUIDE.md#racing)**

---

## Multi-Node Racing (Optional)

If you have a second device — or up to seven of them — pair them as a single race-directing network. No router, no extra hardware.

### Set Up the Master

1. Pick one device to be the race director
2. Open **Settings → Multi-Node Timing**
3. Set **Node Mode** = `Master` and tap **Apply Multi-Node & Reboot**
4. After reboot, note the master's AP name (e.g. `FPVRaceOne_AB12CD`)

### Set Up Each Client — Option A: Master Recruit (one tap)

1. On the **master**, open **Settings → Multi-Node Timing → Recruit Nearby Units**
2. The master scans for every `FPVRaceOne_*` AP in range, joins each one,
   switches it into Client mode, points it at the master's SSID, and reboots it
3. A full-screen overlay shows progress; the master's own AP drops for
   ~60 seconds during the pass — reconnect when it returns
4. By default, units already in `Client` or `Master` mode are skipped — tick
   "Force recruit nodes already configured as clients" to re-target them too

This is the fastest setup for ad-hoc events where pilots haven't pre-configured
their timers.

### Set Up Each Client — Option B: Manual

1. On the next device, open **Settings → Multi-Node Timing**
2. Set **Node Mode** = `Client`
3. Tap **Scan** to discover masters in range, or paste the master's SSID into **Master SSID**
4. Tap **Apply Multi-Node & Reboot**
5. After reboot, the client will join the master's WiFi automatically

### Race

- On the **master**, every connected client appears as a card on the Race
  tab with the pilot's name, lap count, and live state (● Running, ○
  Stopped, ⚠ DNF). Slot labels are letters **A** through **G**
- Tap **Start All** to start every pilot at once; tap **Stop All** to end the heat
- Each client also keeps its own local Start / Stop — useful for a pilot
  to drop out mid-heat (their card shows **DNF** on the master, the heat
  keeps going)

### Editing pilots from the master

Every slot card (including the **Host** card for the master itself) has a
pencil icon. Tap it to open the Edit Pilot modal where you can:

- Change pilot name, color, band, channel, RSSI thresholds, or skip flag
- Run the **Calibration Wizard** for that client remotely (the wizard
  records on the target client and pushes thresholds back) or locally
  for the host
- View **Live RSSI** from the selected client (toggle on the right of
  the title) — peak-detected at the firmware so even a 5 Hz poll catches
  brief gate passes
- **Move (Swap) Pilot to Slot** — pick a target letter; if occupied, the
  two pilots swap places, both clients persist the new slot to NVS
- **Kick from Slot** (clients only) — pauses the client's reconnect
  attempts for one minute so another unit can take its place

Save commits and keeps the modal open; Close dismisses.

### Tip — Solo Practice During a Heat

If you want to keep practising while a director is running heats on the other pilots, enable **"Ignore Race Director Start/Stop if already racing"** on your client (Settings → Multi-Node). Now a director's Start All won't reset your practice run.

**[Full multi-node guide →](USER_GUIDE.md#multi-node-timing)**

---

## Firmware Updates (OTA)

The device updates itself from GitHub Releases — no PlatformIO or cables required.

1. **Settings → Firmware Update** → enter your home WiFi credentials (one-time)
2. Tap **Check for Updates** — the device briefly joins your home network,
   queries GitHub, then returns to AP mode
3. If a newer release is available, tap **Update Now**. The device flashes
   filesystem + firmware and reboots once

Updates are blocked while a race is running. A failed download keeps the
previous firmware on the device — a flaky network can't brick it.

For manual flashing (new hardware, recovery, or development), see
[Flash the Firmware](BUILD_FROM_SCRATCH.md#step-5--flash-the-firmware).

---

## Tips

- **Race History** — Races are not persisted across power cycles on the
  current hardware. Use **Download** in the Race History tab to save the
  session JSON before unplugging
- **Config Backup** — The Settings footer has **Download** / **Import**
  buttons. Export your config before a major firmware update so you can
  restore band/channel/calibration in seconds afterwards
- **Voice on the director's laptop** — Enable the Voice toggle on the race
  director's device (and leave it off on pilot phones) so laps are called
  out without the gate sounding like a chorus
- **Recalibrate when you change frequency** — Calibration is per-frequency.
  If you fly on a different VTx band/channel for a session, run the wizard
  again so the Enter/Exit thresholds suit the new signal

---

## Troubleshooting

### No WiFi Network Appearing

- Wait 15 seconds after power-on for the AP to start
- Check the USB power supply is providing stable 5V
- Try pressing the BOOT/RESET button on the device

### No RSSI Reading / Signal Flat at Zero

- Verify the RX5808 module is seated correctly
- Check that the RSSI pin is connected (A2 on XIAO C6)
- Confirm band and channel match your VTx exactly
- Let the VTx warm up — cold VTx produces lower/unstable RSSI

### Missing Laps

- Lower Enter RSSI by 5 points
- Confirm the VTx has warmed up (30 seconds minimum)
- Check band and channel are set correctly
- In Settings → Signal Processing, lower the **Pipeline Smoothing** slider to reduce signal lag

### False / Extra Laps

- Increase **Minimum Lap Time** in Settings → Race Setup
- Raise Exit RSSI by 5 points
- In Settings → Signal Processing, raise the **Pipeline Smoothing** slider for extra noise rejection
- Move the timer further from the flight path

### Can't Connect to Web Interface

- Make sure you are connected to the `FPVRaceOne_XXXX` WiFi network
- Navigate directly to `http://192.168.4.1`
- Try a different browser or clear the browser cache
- Check that no VPN is active on your device

### Voice Announcements Not Working

- In Settings → TTS, turn the **Voice** toggle on and tap **Test Voice** to hear a sample announcement
- Check that your browser has not blocked autoplay audio (Chrome and Safari often require an initial user interaction on the page before audio plays)
- The announcement is spoken by the **browser's** built-in voice (Web Speech API), so the voice depends on the device the web UI is open on. On phones, system text-to-speech needs to be enabled in the OS settings; on desktops Chrome/Edge/Safari all ship a usable English voice out of the box

---

## Default Settings Reference

| Setting | Value |
|---|---|
| WiFi SSID / Password | `FPVRaceOne_XXXX` / `fpvraceone` |
| Web address (Single / Client) | `http://192.168.4.1` |
| Web address (Master) | `http://192.168.5.1` |
| Min lap time | 5 seconds |
| Max laps | Infinite (0) |
| Pipeline Smoothing | Level 5 |
| Gate-1 Bootstrap | Off |
| Voice | Off |

---

## Next Steps

- **[User Guide](USER_GUIDE.md)** — Master all features
- **[Features Guide](FEATURES.md)** — In-depth technical reference
- **[Build From Scratch](BUILD_FROM_SCRATCH.md)** — Wiring and assembly, plus [manual flashing](BUILD_FROM_SCRATCH.md#step-5--flash-the-firmware) for new hardware or recovery

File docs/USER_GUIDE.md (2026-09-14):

# FPVRaceOne User Guide

Complete guide to using all features of your FPVRaceOne lap timer.

**Navigation:** [Home](../README.md) | [Getting Started](GETTING_STARTED.md) | [Features](FEATURES.md)

---

## Table of Contents

1. [Connecting](#connecting)
2. [Web Interface Overview](#web-interface-overview)
3. [Settings](#settings)
4. [Calibration](#calibration)
5. [Racing](#racing)
6. [Race Analysis](#race-analysis)
7. [Race History](#race-history)
8. [Advanced Features](#advanced-features)
9. [Tips & Best Practices](#tips--best-practices)

---

## Connecting

### WiFi

FPVRaceOne broadcasts its own WiFi Access Point on startup.

1. Power on the device and wait 10–15 seconds
2. Connect to **`FPVRaceOne_XXXX`** (last 4 digits of MAC address)
3. Password: **`fpvraceone`**
4. Open a browser and go to **`http://192.168.4.1`**

> No captive portal — your phone or laptop can stay connected to FPVRaceOne WiFi while maintaining a cellular internet connection. (Note: Samsung devices do not allow wifi to a non-internet AP and cellular at the same time).

### Status LEDs

Two small LEDs are visible through the holes on the underside of the case, just to one side of the USB-C connector — one yellow, one red.

| LED | What it means |
|-----|---|
| **Yellow** | Web server status. **Off** during boot. **Slow blink (~1 Hz)** once the WiFi AP is up and the web UI is ready for clients. Off again only if the firmware has stopped serving — almost always a sign to check the serial monitor. |
| **Red** | Not used. **Briefly on** at every power-up, then **off**. |

So the quick health check after power-up: red flickers once, yellow comes on blinking after a couple of seconds → device is ready to accept WiFi connections at `http://192.168.4.1` (or `http://192.168.5.1` in Master mode).

---

## Web Interface Overview

The interface is organised into four main tabs:

### Race Tab

The primary racing interface.

- **Timer** — Current race elapsed time
- **Lap Counter** — Current lap / max laps (if configured)
- **Control Buttons** — Start Race, Stop Race, Add Lap (manual), Clear Laps
- **Lap Table** — All recorded laps with times and gap-to-previous
- **Statistics** — Fastest lap, median, best 3 laps (sum and consecutive)
- **Charts** — Lap history bar chart and fastest 3-consecutive round chart

### Calibration Tab

RSSI threshold setup and the calibration wizard.

- Live RSSI signal chart
- Calibration Wizard (guided fly-over recording + auto threshold calculation)
- Enter / Exit threshold sliders with save button
- Pause / resume live signal view for threshold fine-tuning

### Race History Tab

Session-scoped log of races completed since the last power-up.

- Race list with timestamps, pilot info, and summary stats
- Expand any race for full lap-by-lap analysis + interactive timeline / playback
- Edit race names and tags
- Marshalling mode — add, remove, or edit laps after the race ended
- Download individual races or the whole session as JSON
- Import races from a previously-downloaded JSON

> **Races are not persisted across power cycles** on the current hardware (no SD card, no flash slot reserved for race storage). Once you're done racing, **download** the session JSON to keep the data — the next reboot starts with an empty list.

### Settings Tab

All configuration, organised into sections with a floating footer.

> **Save Configuration button:** The button highlights **orange** (with a pulse animation) whenever you have unsaved changes. Click it to commit everything to the device. It returns to its inactive state once saved successfully.

---

## Settings

### Race Setup

| Setting | Description |
|---|---|
| **Max Laps** | 0 = infinite; 1–50 = auto-stop when reached |
| **Min Lap Time** | Reject gate triggers closer together than this (seconds) |

### TTS Settings

Lap announcements are spoken by your **browser's** built-in voice (Web Speech API) — the device itself doesn't carry any audio files, so the voice you hear is whichever one your phone or laptop's OS provides for English.

| Setting | Options |
|---|---|
| **Announcer Type** | None / Beep / Lap Time / 2 Consecutive Laps / 3 Consecutive Laps |
| **Lap Announcement Format** | Pilot + Lap + Time / Pilot + Time / Lap + Time / Time Only |
| **Announcer Rate** | 0.1–2.0× playback speed |

**Voice** is controlled by a single on/off toggle. **Test Voice** plays a
sample announcement with your current pilot name. Lap times of 60 seconds
or longer are announced as "X minute(s) Y point ZZ".

Because the audio comes from the browser, **the device that's logged in to the web UI is the one that speaks** — handy if you want the race director's laptop to call out laps while pilot phones stay silent (just don't enable voice on the pilot pages).

### Pilot Info

| Setting | Description |
|---|---|
| **Band & Channel** | Must match your drone's VTx exactly |
| **Pilot Name** | Full name for voice announcements and race records |
| **Callsign** | Short display name (max 10 chars) |
| **Phonetic Name** | How TTS pronounces your name |
| **Pilot Color** | Used in race history and display |

Band and channel changes are **auto-saved** immediately on selection.

### Signal Processing

#### How RSSI is sampled

The ADC runs in **continuous DMA mode at 20 kHz**, sampling the RX5808's RSSI
line into a hardware ring buffer with no CPU involvement. An interrupt reduces
each completed 32-conversion frame to its **maximum** — about 625 times per
second — and each read returns and clears that running peak.

The point of this is that **a peak can never be missed because software was
busy**. A timer that calls `analogRead()` once per main-loop iteration samples at
roughly 200–500 Hz, and a fast gate pass can slip between two of those samples.
With peak-hold DMA, every read carries the highest value the hardware saw since
the last read, whatever the software was doing in between.

#### How RSSI is filtered

**One stage: a running median.** Window size is odd and comes from the
**Pipeline Smoothing** slider:

| Slider | Window | Suited to |
|---|---|---|
| 0–1 | N = 3 | Near-raw, maximum peak fidelity |
| 2–3 | N = 5 | High-speed racing (100+ mph), clean RF |
| 4–5 | N = 7 | **Default** — race speeds, mixed RF |
| 6 | N = 9 | |
| 7 | N = 11 | Slower race pace / noisier RF |
| 8–9 | N = 13 | |
| 10 | N = 15 | Cruise / freestyle / very noisy environment |

A median throws out isolated spike samples while keeping the true peak height of
a fast pass intact — which is exactly what an averaging filter cannot do. At the
default N = 7 the window spans roughly 14–35 ms, well inside the 50–100 ms peak
of a racing pass.

> **Changed from earlier firmware.** This replaced a five-stage cascade
> (Kalman → median-of-3 → 7-sample moving average → EMA → step limiter). The
> accumulated lag smeared fast peaks badly enough that real gate crossings
> sometimes never reached the Enter threshold. The Kalman, moving-average, EMA
> and step-limiter stages no longer exist in the detection path.

**Detection parameters (built in, not exposed):**

| Parameter | Default | Notes |
|---|---|---|
| Enter hold samples | 2 | Consecutive samples at/above Enter RSSI before a crossing starts. Backs up the median so a short noise burst can't open one |
| Exit | 1 sample | The crossing ends as soon as the filtered value falls below Exit — no confirm count |
| Peak margin above exit | none | If the filtered signal reached Enter, the pass is valid by definition; no extra margin is required |
| Ceiling-drift watchdog | 3 s | If "in gate" longer than this without exit, state is force-reset so a baseline drift up to Enter can't lock detection |

**Gate-1 Bootstrap (toggle):** When on, the first lap of a race is special-cased so a drone already inside the gate at race start still produces a clean first lap (relaxed enter, lower 2-sample debounce, 3-count peak margin). When off, Gate 1 behaves like any other gate.

### LED Setup

Configures the on-device status LED (preset, brightness, colour). Used to indicate WiFi state, race state, and lap events.

### Multi-Node Timing

Network up to **8 FPVRaceOne devices** together — no router, no hub, no extra hardware. One device acts as the race-director **Master** and up to **7 Clients** join its WiFi. Lap events stream back to the master in real time so the director sees every pilot's race on a single screen.

#### Roles

| Mode | What it does |
|---|---|
| **Single** (default) | Standalone — no inter-device traffic |
| **Master** | Hosts the AP that clients join. Renders the multi-node Race tab with a card per pilot. Broadcasts Start All / Stop All |
| **Client** | Connects to a master AP. Forwards lap counts and times via 1 Hz heartbeats. Honours master Start / Stop unless overridden |

#### Settings (Settings → Multi-Node)

| Setting | Visible when | Description |
|---|---|---|
| **Node Mode** | Always | Single / Master / Client. Changing this requires reboot — the **Apply Multi-Node & Reboot** button only enables when the mode changes |
| **Master SSID** | Client | The master device's AP name (e.g. `FPVRaceOne_AB12CD`). Type it manually or use **Scan** to discover masters in range |
| **Scan for Masters** | Client | Lists every `FPVRaceOne_*` AP within range — tap one to autofill |
| **Recruit Nearby Units** | Master | Master scans for every `FPVRaceOne_*` AP in range, joins each, sets it to Client mode, points it at the master's SSID, and reboots it. Tick "Force recruit nodes already configured as clients" to re-target units that are already in Master or Client mode. The master's AP drops for ~60 s during the pass; a full-screen overlay shows progress |
| **Ignore Race Director Start/Stop if already racing** | Client | When on, a master Start/Stop broadcast is ignored if the client is already mid-race locally. Lets a pilot keep practising while a heat is being run on the others |

#### Race-Directing Flow

1. **Master** Race tab shows a card per connected client labelled by slot letter (A through G), with pilot name, running indicator, lap count, and last lap time
2. Tap **Start All** — every client starts simultaneously
3. As pilots fly, each client streams its laps back. The master cards update live (Server-Sent Events, sub-second latency)
4. Tap **Stop All** — every client stops cleanly
5. If a pilot crashes out, they tap **Stop** on their own client. The master sees a **DNF** badge on that pilot's card; the rest of the heat continues uninterrupted

#### State Indicators on Master Cards

| Indicator | Meaning |
|---|---|
| ● **Running** | Client's lap timer is running |
| ○ **Stopped** | Client is idle |
| ⚠ **DNF** | Client pressed Stop locally during an active master-broadcast race |

#### Edit Pilot Modal (Master)

Tap the pencil icon on any pilot card — **including the host's own card** — to
open the per-pilot editor. The same modal is used for client pilots and the
master; fields that don't apply to the host (Move / Swap, Kick) are hidden
automatically.

Fields:

| Field | Notes |
|---|---|
| **Pilot Name / Color** | Color dropdown auto-uses black text on light backgrounds (Gold, Green, Cyan, White, Spring Green) for legibility on the slot card |
| **Band / Channel** | Frequency in MHz updates live |
| **Live RSSI** | Toggle on the right of the title (default OFF). When ON, the master polls the selected node at 5 Hz; the firmware's peak-since-last sampler catches a brief gate pass even at that rate. Red Enter / orange Exit threshold lines track the sliders as you drag. Confirms before turning on during an active race |
| **Enter RSSI / Exit RSSI** | Sliders with +/− step buttons. Threshold lines on the Live RSSI chart move in real time |
| **Run Calibration Wizard** | For a client: the wizard records on that client and pushes thresholds back via the master proxy. For the host: runs locally. Only one wizard can be active at a time, blocked during an active race |
| **Move (Swap) Pilot to Slot** | Dropdown showing every slot letter A–G with its current occupant. If the target is occupied, the two pilots swap places and both persist their new slot to NVS. Hidden on the host card |
| **Ignore Race Director Start/Stop** | Same toggle as Settings → Multi-Node |
| **Kick From Slot** | Pauses the client's reconnect attempts for one minute so another unit can take its place. Hidden on the host card |

**Save** commits changes and **keeps the modal open** so you can continue
tweaking (briefly shows "Saved ✓"). **Close** dismisses. The modal body
scrolls if it overflows the viewport; Save / Close stay pinned at the bottom.

### Firmware Update

The device updates itself from GitHub Releases.

1. Enter your **Home WiFi** credentials (one-time, saved automatically)
2. Tap **Check for Updates** — the device briefly joins your home network, queries GitHub, returns to AP mode
3. If a newer release exists, you'll see the version + release notes — tap **Update Now**
4. The device flashes the filesystem image, then the firmware image, then reboots once. Total time ~1–3 minutes
5. Your device may briefly disconnect from the device's AP during the update — reconnect when prompted

**Safety:**
- Updates are blocked while a race is running
- Failed downloads keep the previous firmware — there is no risk of bricking
- Manual flashing is still available for first-time setup or recovery — the Windows flasher tool in [Flash the Firmware](BUILD_FROM_SCRATCH.md#step-5--flash-the-firmware), or PlatformIO in [Building the Firmware From Source](BUILD_FROM_SCRATCH.md#building-the-firmware-from-source)

### WiFi & Connection

| Setting | Description |
|---|---|
| **Antenna** | Switch between internal PCB antenna and external connector (takes effect on next boot) |
| **TX Power** | WiFi transmit power in dBm, 2–21 (takes effect on next boot). Lower values reduce range and interference; raise it back to 21 for maximum AP range |

The Home WiFi fields used by the firmware updater (Settings → Firmware Update) double as station-mode credentials — once entered, the device can join your home WiFi for OTA pulls.

### System Settings

| Section | Options |
|---|---|
| **Appearance** | Theme — 14 to choose from, including light variants. Default is **FPVRaceOne**; **FPVRaceOne Day** is its light counterpart |
| **Device** | Reboot button (required for antenna and TX power changes to take effect) |
| **Race Tab** | "Always hide download reminder banner" — permanently dismiss the *races are lost on flash* banner once you've started downloading races regularly |
| **Developer** | **Dev Mode (Simulate Laps)** — when on, tap a pilot's name on the Race tab to inject a random simulated lap. Useful for testing multi-node UI without real quads |

---

## Calibration

### Understanding RSSI Thresholds

- **Enter RSSI** — Gate crossing begins when signal rises *above* this value
- **Exit RSSI** — Lap is recorded when signal falls *below* this value after peaking

```
RSSI  │     /\
      │    /  \
Enter ├───/────\────
      │  /      \
Exit  ├─/────────\──
      └────────────── Time
```

Enter must always be higher than Exit. The lap timestamp is recorded at the peak.

### Using the Calibration Wizard

1. Go to the **Calibration** tab and click **"Start Calibration Wizard"**. The wizard opens with instructions showing and **nothing recording yet** — take your position at the gate first
2. Click **Start Recording** (it turns red and becomes **Stop Recording**), fly **3 gate passes** at race speed, then click **Stop Recording**. Recording also stops by itself at 100 seconds
3. The wizard auto-detects the three highest peaks and overlays markers — drag any marker if a peak was misidentified
4. If the three peaks differ in height by >15 %, the wizard recommends a re-fly. Equal-height peaks calibrate better; re-flying takes 30 seconds and is almost always worth it
5. Click **Calculate Thresholds** — the wizard shows the recommended **Enter** and **Exit** values and **saves them to the timer immediately**. Close with **Done**

You don't need to confirm the result to keep it. To change it afterwards, use the
Enter/Exit sliders on the Calibration tab and press **Save RSSI Thresholds**. If
the automatic save fails, the results screen says so in red and offers an
**Apply Thresholds** button to retry.

**How the thresholds are picked:**

- **Enter** ≈ 95 % of the *weakest* of the three peaks — leaves about 5 % headroom for lap-to-lap variation. Tight enough that adjacent gates in close-pattern layouts typically don't trigger
- **Exit** = Enter − 4 — tight hysteresis tuned for close-pattern tracks where gates are close together, raised above the recording's 35th-percentile noise floor if needed

### Manual Threshold Adjustment

Use the **Enter** and **Exit** sliders in the Calibration tab for fine-tuning. The live RSSI chart shows the signal and threshold lines in real time.

- **Save RSSI Thresholds** highlights **orange** the moment a slider value differs from what's saved — it's the same dirty-state pattern as the Save Configuration button. Click it to commit
- You can also **pause** the live chart to examine a specific moment, then **resume** the live feed
- After a calibration wizard run the chart enters **overview mode** showing the recorded pass; the **Pause Scanner** button changes label to **Exit Wizard**. Clicking it with unsaved threshold changes prompts you to confirm: *"You have not saved the new values. Are you sure you want to exit?"*

### Calibration Tips

| Problem | Fix |
|---|-----|
| Missing laps | Lower Enter RSSI by 5 points; lower **Pipeline Smoothing** in Settings → Signal Processing for less lag |
| False / extra laps | Raise Exit RSSI by 5, increase Min Lap Time, or raise **Pipeline Smoothing** to reject more noise |
| Inconsistent detection | Ensure VTx has warmed up 30+ seconds; rerun the wizard with cleaner peaks |
| Drone already in gate at start triggers spurious Lap 1 | Enable **Gate-1 Bootstrap** in Settings → Signal Processing |

---

## Racing

### Starting a Race

1. Go to the **Race** tab
2. Click **"Start Race"**
3. Listen for the countdown — "Arm your quad… starting on the tone…"
4. A random 1–5 second delay ends with a start beep at 880 Hz
5. Fly! The first gate pass is **Gate 1** (hole shot)

### During a Race

- The timer runs from the start beep
- Each gate pass registers a lap; voice announces each one (if enabled)
- Click **"Add Lap"** to manually register a lap at the current time if the gate missed a pass
- The lap table and statistics update in real time

### Stopping a Race

Click **"Stop Race"** — the race is saved automatically to history.

If Max Laps is set, the race stops automatically when the count is reached.

### Clearing Laps

Click **"Clear Laps"** — saves the current race to history first, then resets the timer and table.

---

## Race Analysis

### Statistics

| Metric | Description |
|---|---|
| **Fastest Lap** | Quickest single lap and which lap number it was |
| **Median Lap** | Middle value of all laps — best consistency indicator |
| **Best 3 Laps** | Sum of the 3 fastest individual laps (MultiGP scoring) |
| **Fastest 3 Consecutive** | Best back-to-back 3-lap sequence (RaceGOW format) |

Gate 1 (hole shot) is excluded from all best-lap calculations.

### Charts

- **Lap History** — Colour-coded horizontal bars for the last 10 laps; width proportional to time
- **Fastest Round** — Vertical bars for the 3 consecutive laps with the best combined time

The fastest lap row is highlighted in **gold** in the lap table.

---

## Race History

Each race you finish is logged to the **Race History** tab automatically. The log lives in RAM only — power-cycling the device clears it, so **download what you want to keep** before unplugging.

### Viewing and Editing

- Click any race card to expand the full lap table, statistics, charts, and the interactive timeline
- Click **Edit** to add a name or tag to the race
- Click **Download** to save the race as a JSON file

### Marshalling Mode

Edit laps after a race is complete:

- **Add a lap** — Click between two existing laps, enter the lap time in seconds
- **Remove a lap** — Click the remove button next to any lap and confirm

Statistics and charts update immediately. Changes are saved into the same in-memory record (so they survive subsequent edits, but still won't survive a reboot — download first).

### Export / Import

- **Download All Races** — Saves the current session's history as a single JSON file
- **Import Races** — Loads a previously-downloaded JSON. On hardware without persistent storage (i.e. this one), importing **replaces** the in-memory history rather than merging

---

## Advanced Features

### Pipeline Smoothing

The single Pipeline Smoothing slider in **Settings → Signal Processing** sets the
**window size of the running median** (see [Signal Processing](#signal-processing)
for the full mapping):

- **Level 5 (default)** = N = 7, roughly a 14–35 ms window
- **Lower** = smaller window, faster response and better peak fidelity, more noise passes through
- **Higher** = larger window, more noise rejection, more lag

Most pilots never need to touch this. Adjust it only if calibration consistently misses laps (lower it) or constantly fires twice (raise it).

### Multi-Node Race Directing

Pair two or more devices for head-to-head racing. See [Multi-Node Timing](#multi-node-timing) above. Common patterns:

- **Solo practice while a master is broadcasting** — turn on *Skip Master Start* on the client so a director's Start All doesn't reset your local race
- **Pilot drops out mid-heat** — the pilot presses Stop on their client; the master sees a **DNF** badge on that pilot's card and the rest of the race continues uninterrupted

### Config Backup & Restore

In **Settings → footer**:
- **Download Config** — Saves all settings as a JSON file
- **Import Config** — Restores settings from a previously downloaded JSON

Export your config before any firmware update.

### Theme Selection

Two colour themes are available in **Settings → Device → Theme**: Material
Oceanic (default, dark) and Material Lighter. The logo automatically
switches between black and white versions to match.

---

## Tips & Best Practices

**For accurate timing:**
- Let the VTx warm up for 30 seconds before calibrating
- Recalibrate if you change frequency or fly with other pilots in the same band
- Use Minimum Lap Time to prevent false triggers from crashes near the gate

**For signal quality:**
- Position the RX5808 antenna to face the gate opening
- Keep the timer module away from other strong RF sources (video transmitters on the bench, etc.)

**For racing:**
- Enable voice announcements on the race director's device so laps are called out without anyone watching the screen
- Download your race session JSON before unplugging the device — race history is not retained across power cycles
- Export your config too if you've spent time fine-tuning, especially before a firmware update

---

**Questions or issues? [Open a GitHub issue](https://github.com/ramiss/FPVRaceOne/issues)**

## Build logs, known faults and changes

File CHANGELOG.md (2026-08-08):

# Changelog

All notable changes to FPVRaceOne will be documented in this file.

> Entries 1.4.x and earlier describe code paths that predate the C6 product
> configuration. **Track Management, SD-card race storage, distance tracking,
> and on-device PiperTTS are NOT present in current C6 builds** — those
> features were stripped during the rename / re-platform from FPVGate.
> Treat 1.4.x entries as historical context, not as feature claims.

## [Unreleased]

### Changed — multinode: skip-enabled pilots' lap times stay visible

- A pilot with **Ignore Race Director** on used to hide its lap times behind
  a "Solo race in progress (ignoring race director)" placeholder on the
  master's Race tab and on its own Multi Race tab. Now the card shows the
  actual lap times — same as every other card — with a small orange
  "Ignoring race director" label above so the director still knows the pilot
  is outside the official race. The leaderboard still excludes them, so
  their times read like a DNF entry rather than competing for rank.
- The client's Multi Race tab (which already received the master's full
  director-state push regardless of skipEnabled) now also shows the client's
  own solo lap times on its own card, so the skip-enabled pilot can observe
  the director's race in parallel with their own.

### Added — multinode: Backup / Restore Pilots

- Master Race tab now has **Backup Pilots** / **Restore Pilots** buttons.
  Backup downloads a JSON file with every node's pilot name, color,
  band / channel / freq, enter / exit RSSI, slot, and master/skip flag —
  each entry keyed by the unit's WiFi MAC. Restore parses the file, matches
  saved entries against the currently online nodes by MAC, and shows a
  preview modal with one checkbox per pilot. Online-and-matched entries are
  selectable; offline-but-matched and not-detected-at-all entries are listed
  but greyed out, so the director can see exactly what would be skipped.
  Calibration is hardware-specific (different receivers / antennas drift to
  different baseline RSSI), so the MAC key guarantees a pilot's saved enter /
  exit thresholds only land back on the same physical unit they came from.
- Restore is blocked while a race is running. Apply re-resolves MAC → current
  nodeId at apply time, so kicks or recruits while the modal was open can't
  push a saved pilot's settings to the wrong slot.
- Master entry in the director-state payload (`/api/multinode/nodes`,
  `multiNodeState` SSE) now carries `"mac"` so the backup file can record
  the host device's identity — without this the master's calibration could
  never be matched on a later restore.

### Fixed — OTA: retry transient WiFi and GitHub failures

- WiFi association now retries up to 3 times. Single-shot association on the
  C6 intermittently fails (~20-30 %) after the AP+STA mode change — the radio
  hasn't fully settled, SSID isn't found on the cached channel, or DHCP times
  out. A clean disconnect + 300 ms pause + WiFi.begin restart per attempt
  recovers cleanly. State message updates as `(attempt N/3)` so the user can
  see retries in flight.
- GitHub releases API call retries up to 3 times on negative HTTPClient codes
  (TLS handshake / DNS / read-timeout / connection-refused). Positive codes
  (200, 404, 5xx) are real responses and aren't retried.

### Fixed — multinode: client could falsely report "connected" while master never knew it existed

- `_postToMasterWithResponse` only read the HTTP response body when the status
  code was 200, so the heartbeat path's "NOT_FOUND" fast-recovery branch was
  dead code — the client never saw the master's 404 reply and instead spent
  10+ seconds in `_heartbeatFailCount` limbo before noticing the connection
  was bogus. Now reads the body for any positive HTTP code.
- `handleHeartbeat` matched on `nodeId` alone with no MAC check, so when one
  client's stale `_myNodeId` collided with another live device's slot, the
  collision client's heartbeats kept "succeeding" against the wrong slot's
  entry — the client thought it was connected while the master only ever
  knew about the legitimate device. Heartbeat payload now includes the
  client's MAC; the master rejects with 404 NOT_FOUND on mismatch, which
  (combined with the fix above) triggers an immediate re-register-with-
  nodeId-0 path that gets the colliding client a fresh free slot.

### Fixed — OTA: Check for Updates rebooted the device

- The check ran synchronously inside the AsyncWebServer request handler, so
  the WiFi mode changes (especially the master-mode AP teardown) ripped out
  the TCP connection the handler was still on — ESPAsyncWebServer panicked
  trying to flush the response and the device rebooted. `OtaManager::init`
  reset state to `IDLE` on the next boot, leaving the frontend's overlay
  spinning forever against `state:0`.
- Check now uses the same async pattern the apply path already uses:
  `requestCheck()` queues a flag and returns immediately; `OtaManager::loop()`
  on Core 0 runs the actual `checkForUpdate()`. The handler returns 202
  immediately, so AsyncWebServer can flush cleanly before the AP goes down.

### Fixed — OTA: master-mode home-WiFi excursion was unreliable

- **Master mode Check for Updates** no longer fails with *"Could not reach
  GitHub releases API"* under client-mesh load. The C6's AP+STA mode shared
  the radio with the AP's beacons + client retune traffic, which chewed
  through LwIP TCP slots before the outbound HTTPS handshake could
  complete. Master OTA now fully tears the AP down for the duration of the
  excursion (same pattern Recruit Nearby Units already uses) and restarts it
  via the canonical `Webserver::startAP()` helper afterwards. Director's
  browser disconnects for ~15–20 s during the check and auto-reconnects
  when the AP comes back; the existing `/api/update/status` polling picks
  up the cached result.
- Client mode disconnect now explicitly re-issues `WiFi.begin(masterSSID)`
  on completion, so the webserver's STA reconnect logic targets the master
  on its next tick instead of retrying the home SSID for ~2 minutes.

### Added — OTA: multi-node pause/resume

- **Check for Updates now safe to run on a master with connected pilots, or
  on a client connected to a master.** Previously the home-WiFi excursion
  starved the STA radio (on a client) or churned the LwIP TCP slot pool
  alongside active client traffic (on a master), surfacing as a `HTTP -1`
  connection-refused error against GitHub
- Before reaching for home WiFi, the device temporarily pauses multi-node
  networking: master-side handlers reject client polls so TCP slots free up,
  and a client disconnects its STA from the master so the radio is free for
  home WiFi. The persisted multi-node mode is unchanged — when the check (or
  apply, or cancel) finishes, the mesh wakes back up automatically
- Confirm dialog before the check explains the consequence in plain English
  ("there are 3 pilots currently connected to this master…") so a director
  can bail out without committing
- 5-minute safety auto-resume catches the case where the user closes the tab
  mid-flow, so the mesh never stays paused indefinitely

### Changed — OTA: human-readable error messages

- GitHub API failures now translate ESP HTTPClient's negative error codes
  (`-1`, `-7`, etc.) into actionable English. Previously surfaced as the
  cryptic `"GitHub API returned HTTP -1"`; now reads e.g. *"Could not reach
  GitHub releases API — your home WiFi may have no internet (or a captive
  portal is blocking it). Verify the saved network is online and try again."*
- Asset preflight and download-and-flash errors use the same translation,
  with a "likely cause + next step" line replacing the bare numeric code

## [1.5.0] - 2026-06-19

Major refresh covering Q1–Q2 2026 work on multi-node race directing, heap /
Core-0 robustness, and Edit-Pilot UX. Versions 1.4.2 through 1.4.x were
never tagged; this entry replaces them.

### Added — Edit Pilot Modal & Master-Side Pilot Control

- Edit Pilot modal accessible from the pencil icon on **every** slot card on
  the master's Race tab — including the master's own host card. Same modal
  for client and master; controls that don't apply to host (Move/Swap,
  Kick) hide automatically when `nodeId === 0`
- **Move (Swap) Pilot to Slot** dropdown — letter list A–G shows each
  slot's current occupant. If the target is occupied, the two pilots swap
  places and both clients persist their new slot to NVS via
  `mnPreferredSlot`
- **Calibration Wizard** runs directly from the modal. For clients, the
  wizard records on the target client and pushes thresholds back via
  master-side proxy endpoints (`/api/multinode/calibration/{start,data,stop}`);
  for the host it runs locally. Only one wizard active at a time, blocked
  during an active race
- **Live RSSI** view in the modal with toggle on the right of the title.
  Defaults OFF; surfaces a `confirm()` dialog when enabled during an
  active race. Auto-zooming y-axis adapts to slider drags
- Modal scrolls when content overflows; Save / Close stay pinned at the
  bottom. Save commits and **keeps the modal open** (was auto-closing);
  brief "Saved ✓" feedback confirms the write
- Master self-edit short-circuit in `/api/multinode/editPilot` — when
  `nodeId === 0` the patch is applied to the master's local Config
  directly instead of trying to HTTP-proxy to itself
- Master entry in director-state JSON now carries `bandIndex`,
  `channelIndex`, `frequency`, `skipEnabled`, `enterRssi`, `exitRssi` —
  fixes the bug where the modal showed defaults and clicking Save
  silently overwrote real settings with junk

### Added — Live RSSI Proxy

- `GET /timer/rssi` returns `{"rssi": N}` from
  `LapTimer::getRssiPeakSinceLast()` — peak-since-last-call sampled at
  full firmware rate (~hundreds of Hz). 5 Hz polling now catches the true
  peak of a brief gate pass instead of a random instantaneous value
- `GET /api/multinode/rssi?nodeId=N` (master-only) proxies to the client.
  On HTTP 200 the master also calls `MultiNodeManager::touchNode()` on
  the target — every successful round-trip is proof of life, so the
  heartbeat watchdog can't false-fire while the link is in heavy use

### Added — Recruit Nearby Units

- `POST /api/multinode/recruit?force=0|1` queues a recruit job processed on
  Core 0: drop the master's AP → STA-scan for `FPVRaceOne_*` APs →
  configure each (unless already in Master / Client mode and `force=0`)
  as a Client pointed at the master → reboot it → restart the master's AP.
  Director's browser shows a full-screen overlay during the ~60 s pass

### Added — Slot Letters (A–G)

- UI uses slot letters everywhere a slot id appears: pilot card header,
  edit modal subtitle, kick/remove confirms, multi-node tab card label,
  solo-racer dialog, callsign fallback (`Node A`), race export fallback
- Firmware serial logs use letters too — `[MULTINODE] connected: A=Sam
  B=Bob C=Lenny ...`, `Node X (Pilot) timed out`, `Re-registered node X`,
  etc.
- Backend IDs stay numeric; the letter is a display-layer convention

### Added — Calibration UX

- **Save RSSI Thresholds** button highlights orange and pulses when slider
  values differ from what's saved (same pattern as Save Configuration)
- "You have not saved the new values. Are you sure you want to exit?"
  confirm dialog when leaving overview mode via Exit Wizard with unsaved
  changes
- `EXIT_GAP` reduced from 7 to 4 — tighter hysteresis tuned for
  close-pattern tracks; final clamp adjusted to match

### Added — Audio

- Voice Enable / Disable buttons replaced with a single on/off toggle
- Lap times ≥ 60 s announced as "X minute(s) Y point ZZ" — long-track
  friendly. Below 60 s the pre-recorded digit clip path is unchanged
- Piper-TTS exclusive branches pre-process raw cleanText to substitute
  long-time floats with the spoken phrase before TTS, so the minutes
  word appears even when format-pattern matchers are skipped
- Pre-arm countdown 5 → 4 gap tightened from ~2 s to ~1 s (extra
  `await setTimeout(1000)` removed; pad-to-1-second loop handles the
  rest)

### Added — Multi-Node Robustness & Diagnostics

- AP slot cap raised from 5 (single) / 4 (client AP) / 9 (master) to **9 across all modes** — a unit demoted from master with 7 ex-clients still trying to reattach can't lock the director's phone out
- WiFi AP **inactivity timeout** set to 60 s via `esp_wifi_set_inactive_time()` (IDF default 5 min) — silent stations drop within a minute so ghost slots free up promptly
- Client STA reconnect **backoff** — 5 s for attempts 1–5, 15 s for 6–13, 30 s for 14+ with **full-channel scan** (`WiFi.begin()` instead of `WiFi.reconnect()`) so a master reboot that lands on a different channel is found within ~3 min
- `handleRegister` gains a `bool& stateChanged` out parameter — steady-state 5 s keep-alive registrations no longer fire `pushMultiNodeState()`, eliminating the constant 600-800 ms `multinode` sub-call stall observed at ~1.4 broadcasts/sec with 7 clients
- `_checkNodeTimeouts()` ignores the `currentTimeMs` parameter (stale by tens of ms by the time it runs) and reads `millis()` fresh inside the function — eliminates the cross-task race that caused "Node X reconnected via heartbeat / Node X timed out 2 ms later" pairs in serial traces
- `MULTINODE_NODE_TIMEOUT_MS` raised 4 → 6 s — accommodates two missed heartbeats plus scheduler jitter
- `MultiNodeManager::handleHeartbeat()` now logs `[MULTINODE] Node X (Pilot) reconnected via heartbeat` on offline→online transitions (was silent)
- `_broadcastDirectorState()` **rate-limited to 1 broadcast / 2 s** via `_lastDirectorBroadcastMs`. Race-critical broadcasts (`_broadcastRacePreArm` / `_broadcastRaceStart` / `_broadcastRaceStop`) are **not** throttled
- `_buildDirectorStatePayload` rewritten as a single-`String` build with capacity reserved up front; eliminates the dozen-realloc-per-broadcast pattern that fragmented the heap. `MultiNodeManager::getNodesToJson()` (which allocated a 8 KB DynamicJsonDocument) no longer called from this path
- SSE zombie cleanup — on `AP_STADISCONNECTED` for a non-multinode MAC, the master calls `events.close()`. Without this, dead browser SSE clients linger indefinitely in `AsyncEventSource`'s client list, every `events.send()` queues a message destined for nobody, and heap drips ~1 KB/sec until fragmentation wedges the master

### Added — Heap & Core-0 Observability

- `[HEAP]` log every 10 s: `free`, `min`-ever, `maxBlk` (largest contiguous), `sta` (AP station count), `sse` (SSE client count)
- Low-heap **auto-reboot watchdog** — sustained `free < 20 KB` or `maxBlk < 8 KB` for 10 s triggers `ESP.restart()`. Safety net against fragmentation wedges; not a substitute for fixing the leak source
- `[AP]` log on every station connect / disconnect with MAC and resulting count
- `[CORE0]` window summary every 10 s — names the worst sub-call in `parallelTask` and the worst preemption gap. Per-call line fires immediately when any single sub-call takes ≥ 100 ms
- `[MULTINODE] connected:` summary every 10 s listing slot=name for every online node

### Added — Pilot Card UI

- **Auto black text on light pilot colors** (Gold, Green, Cyan, White, Spring Green) via WCAG relative luminance threshold (`> 0.6`). Card badges (Host, Me, TAP, Racing) keep white text via `.mn-card-badge { color: #fff }` so they stay readable on the dark semi-transparent overlays
- Edit pencil icon now appears on the host pilot card in master mode (was suppressed)

### Changed

- Themes reduced from 23 to 2 (Material Oceanic default, Material Lighter). Orphaned `[data-theme="..."]` CSS blocks remain inert in `style.css` if a deployment wants to re-expose any of the old palettes
- `/api/multinode/editPilot` handler captures touched-field set **before** `conf->fromJson()` — calls `pushMultiNodeState()` only when an Edit-Pilot-relevant field changed (was firing on every Settings or Calibration-tab save)
- `MULTINODE_REGISTER_INTERVAL_MS` semantics — still 5 s, but registration is now a true keep-alive (silent unless something changes). First-time joins, recoveries, and identity-field updates still log loudly

### Fixed

- **Black pilot color silently reset to Blue** — `parseInt('000000', 16) === 0` and `0 || 0x0080FF` masked the user's selection. Replaced with `Number.isFinite()` check
- **Master "Edit Host" overwrote band/channel/skip with defaults** — modal was reading missing JSON fields, falling back to defaults, and `mnSavePilotModal` sent every field on every Save. Fixed by mirroring those fields on the master JSON entry in `_buildDirectorStatePayload`
- **Wizard Apply Thresholds for master-self didn't sync the Calibration tab** — `applyCalculatedThresholds` now routes through `editPilot` when `mnNodeMode === 1` (any nodeId, including 0). Master-self path also explicitly syncs `enterRssiInput.value`, the global `enterRssi`, `baselineConfig`, and clears `stagedConfig` keys so the dirty indicator clears
- **Save RSSI on Calibration tab didn't refresh `mnCurrentNodes`** — `/config` handler now calls `pushMultiNodeState()` after writing config (gated to actual Edit-Pilot-relevant fields)
- **Multinode timeout false positives within 2 ms of a heartbeat arriving** — see `_checkNodeTimeouts` fresh-millis change above
- **Edit Pilot modal showed previous pilot's stale RSSI trace** — `_mnModalRssiClearCanvas()` resets the series, the axis-init flag, and paints the canvas background on every modal open
- **Modal Live RSSI canvas was 0×0 in some cases** — `streamTo()` was being called before layout completed. Added explicit `width="300" height="130"` canvas attributes plus an `await _waitForCanvasLayout()` rAF loop that polls `offsetWidth/Height` until non-zero
- **First-call axis race** — the live-zoom code unconditionally recomputes y-axis range from current slider + trace data on every sync (was locked after first call, so slider drags pushed the line off-screen when the range was tight)

### Technical — Release Artifacts

- CI now produces **four** release assets: `FPVRaceOne-firmware.bin` (OTA), `FPVRaceOne-littlefs.bin` (filesystem), `FPVRaceOne-merged.bin` (full-flash recovery image), and `flash-manifest.json` (schema-1 machine-readable manifest naming the offsets)
- The dedicated **[FPVRaceOne Flasher Windows app](https://github.com/ramiss/FPVRaceOne-Flasher/releases/latest/download/FPVRaceOne-Flasher.exe)** reads the manifest, so partition-table changes never drift the documented offsets. Recovery mode flashes `merged + filesystem`; Update mode flashes `firmware + filesystem`

## [1.4.1] - 2024-12-14

### Added - SD Card Configuration Backup/Restore
- **Config Backup System** - Automatic and manual configuration backup to SD card
  - Backup location: `/sd/config/config_backup.json`
  - Automatic backup on every config save
  - Manual restore via Configuration modal
  - Persists all settings: WiFi, RX5808, LED, pilot info, webhooks, race settings
  - UI controls in System Settings section
  - Visual feedback for backup/restore operations
- **Backup/Restore API Endpoints**
  - `POST /config/backup` - Create backup on SD card
  - `POST /config/restore` - Restore config from SD backup
  - `GET /config/backup/check` - Verify backup exists
  - Returns success/failure status with timestamps

### Added - Device-Side Settings Storage
- **Device Settings Persistence** - All settings now saved on device (config v6)
  - Added `selectedVoice` (String) - Persists selected TTS voice
  - Added `selectedTheme` (String) - Persists UI theme across clients
  - No more localStorage dependency for critical settings
  - Settings sync across all connected clients
  - Restored on device boot
- **Configuration Version 6** - Expanded config struct
  - Theme selector now saves to EEPROM
  - Voice selection persists through reboots
  - Automatic migration from config v5 to v6
  - Backwards compatible with older configs

### Added - Built-In Serial Monitor
- **Debug Logging System** - Real-time serial output in web interface
  - New DebugLogger class for structured logging
  - Circular buffer (100 lines) with timestamp and level
  - Log levels: DEBUG, INFO, WARNING, ERROR
  - Replaces all `Serial.println()` calls with `DEBUG_LOG()` macros
  - Zero performance impact when debug disabled
- **Serial Monitor UI** - Live debug viewer in Diagnostics tab
  - Server-Sent Events (SSE) stream for real-time updates
  - Auto-scroll with manual scroll lock
  - Color-coded log levels (gray/blue/orange/red)
  - Clear button to reset buffer
  - 100-line rolling buffer
  - No page refresh required
- **Debug API Endpoints**
  - `GET /debug/logs` - Retrieve current log buffer
  - `GET /debug/stream` - SSE stream for live updates
  - `POST /debug/clear` - Clear log buffer

### Added - mDNS Improvements
- **Enhanced mDNS Support** - Better device discovery and connectivity
  - Hostname: `fpvraceone.local` (replaces IP addresses)
  - Service advertisement: `_http._tcp` on port 80
  - Works in both AP and Station modes
  - Automatic service re-registration after WiFi changes
  - TXT records with version and device info
  - Fallback to IP address if mDNS unavailable

### Added - Race History Enhancements
- **Improved Gate 1 Handling** - Separated from lap counting
  - Gate 1 labeled as "Gate 1" (not "Lap 1")
  - Lap count excludes Gate 1 pass
  - First actual lap correctly numbered as "Lap 1"
  - Gate 1 time calculated as race start to first gate pass
- **Total Race Time Display** - Shows cumulative race duration
  - Displayed in race list view
  - Shown in race details stats
  - Format: MM:SS.mmm or HH:MM:SS.mmm
  - Sum of all lap times including Gate 1
- **Improved Details View UX** - Better race history navigation
  - Details now appear directly below selected race (slide-down)
  - Smooth scroll to details view
  - No more scrolling to bottom of page
  - Click another race to move details

### Added - Race Timeline and Playback
- **Interactive Timeline Visualization** - Visual race event timeline
  - Horizontal gradient timeline bar
  - Flag-shaped markers for each event
  - Color-coded: Green (start), Yellow (Gate 1), Blue (laps), Red (stop)
  - Positioned by percentage of total race time
  - Lap time indicators between events showing deltas
  - Race Start/Stop positioned above timeline
  - Gate 1/Laps positioned below timeline
  - Clean layout with text backgrounds for readability
- **Race Playback System** - Replay saved races
  - Play/Stop controls for race replay
  - Animated playhead showing current position
  - Real-time webhook triggers during playback
  - OSD updates during playback
  - LED flash on each event
  - Accurate timing based on recorded lap times
  - Optional webhook toggle (useful for testing)
- **Playback API Endpoints**
  - `POST /timer/playbackStart` - Trigger race start event
  - `POST /timer/playbackLap` - Trigger lap event (with lap number)
  - `POST /timer/playbackStop` - Trigger race stop event
  - All playback endpoints fire webhooks and broadcast SSE events

### Fixed - LED Settings Persistence Bug
- **LED Preset Reversion** - Fixed LEDs reverting to default on page refresh
  - Split `changeLedPreset()` into UI-only and device command functions
  - Page load now reads `ledPreset` from device config
  - Manual override flag prevents status changes overriding user settings
  - LEDs maintain user-selected preset through WiFi client connections
- **LED Status Override** - Fixed `STATUS_USER_CONNECTED` overriding LED preset
  - Modified `setStatus()` to check manual override flag
  - Non-critical status changes ignored when manual override active
  - Race events still override (intentional behavior)

### Changed
- **Configuration Structure** - Expanded device config (v6)
  - Added voice and theme persistence fields
  - Increased buffer sizes for string storage
  - JSON serialization for backup/restore
- **Race History UI** - Enhanced visualization and UX
  - Timeline component with CSS triangle flags
  - Playback controls integrated into details view
  - Better event spacing and overlap handling
  - Improved mobile responsiveness
- **Debug Output** - Structured logging system
  - All debug output now through DebugLogger
  - Consistent log format with timestamps
  - Web-accessible debug console
  - Reduced serial clutter in production

### Technical
- **New Libraries**
  - `lib/DEBUG/debuglogger.h` - Circular buffer debug logging system
- **Configuration** - Config v6 schema
  - Config struct: ~220 bytes (within EEPROM limits)
  - Migration path: v5 → v6 automatic
- **Storage** - SD card structure expansion
  - `/sd/config/` directory for backups
  - Atomic write operations for backup files
  - JSON format for human-readable backups
- **Frontend Enhancements**
  - Timeline rendering with flexbox layout
  - Playback state machine with setTimeout scheduling
  - SSE debug log streaming
  - Config backup/restore UI controls
- **WebServer** - New endpoints (lines 459-503 in webserver.cpp)
  - Playback endpoints for timeline feature
  - Debug endpoints for serial monitor
  - Config backup/restore endpoints

## [1.4.0] - 2024-12-10

### Added - Track Management System
- **Track Library** - Create and manage track profiles with complete metadata
  - Track name, tags, and custom notes
  - Distance specification in meters for lap distance tracking
  - Track images (upload via web interface)
  - Up to 50 tracks stored on SD card or LittleFS
  - Individual track files: `/tracks/track_<id>.json`
  - Track images: `/tracks/images/track_<id>.jpg`
- **Track Selection** - Choose active track before racing
  - Dropdown selector in Configuration tab
  - Selected track persists to EEPROM
  - Track info displayed during race
- **Track CRUD Operations** - Full management via web interface
  - Create new track
  - Edit existing track (name, distance, tags, notes)
  - Delete track (with confirmation)
  - Import/export tracks
  - Track search and filtering

### Added - Distance Tracking
- **Real-Time Distance Display** - Track total distance travelled during race
  - Live distance counter updates every 100ms
  - Shows distance per lap (when track selected)
  - Shows total distance travelled
  - Shows distance remaining (finite lap races)
  - Displays in race interface: "Lap 1: 12.34s | 125/500m"
- **Race Distance Statistics** - Distance data stored with race history
  - Total race distance recorded
  - Track association (trackId and trackName)
  - Distance displayed in race history
  - Race history shows: "Track: MyTrack (1250m)"
  - Per-lap distance calculations in race details
- **LapTimer Integration** - Distance calculation in timing engine
  - `setTrack()` - Associates track with timer
  - `getTotalDistance()` - Returns total distance travelled
  - `getDistanceRemaining()` - Returns distance to finish
  - Automatic distance increment on lap completion
  - Distance reset on race start

### Added - Enhanced Race Editing
- **Race Metadata Editing** - Edit race information after completion
  - Edit race name
  - Edit race tags
  - Edit race notes
  - Associate/change track
  - Update total distance
  - Metadata saved separately from lap times
- **Lap Time Editing** - Full lap manipulation (expanded from v1.3.2)
  - Add lap at any position
  - Remove lap with confirmation
  - Edit individual lap times (NEW)
  - Drag-and-drop lap reordering (NEW)
  - Real-time statistics recalculation
  - Separate API endpoints for metadata vs lap changes
- **Edit UI Improvements** - Better race editing experience
  - Tabbed interface: Info tab and Laps tab
  - Track selector dropdown in edit modal
  - Visual lap editor with inline controls
  - Validation for lap time formats
  - Confirmation dialogs for destructive actions

### Added - API Endpoints
- **Track Management API**
  - `GET /tracks` - List all tracks
  - `POST /tracks/create` - Create new track
  - `POST /tracks/update` - Update existing track
  - `POST /tracks/delete` - Delete track
  - `POST /tracks/select` - Set active track
  - `GET /tracks/image/<id>` - Retrieve track image
- **Distance Tracking API**
  - `GET /timer/distance` - Get current distance stats
  - Returns: totalDistance, distanceRemaining, trackId, trackName
- **Enhanced Race API**
  - `POST /races/update` - Update race metadata only
  - `POST /races/updateLaps` - Update race lap times only
  - Separated for better granularity and performance

### Changed
- **Race History Structure** - Enhanced race data format
  - Added `trackId` field (uint32_t)
  - Added `trackName` field (String)
  - Added `totalDistance` field (float, in meters)
  - Added `notes` field for race notes
  - Backwards compatible with older races (null values)
- **Configuration** - Expanded config storage
  - Added `selectedTrackId` (uint32_t) - persists to EEPROM
  - Config version remains v3 (compatible)
  - Selected track restored on boot
- **Race Interface** - Improved race display
  - Current lap time shown during race
  - Distance counter (when track selected)
  - Track name displayed in race stats
  - Distance remaining countdown (finite lap races)
- **Race History UI** - Enhanced history display
  - Track name and total distance in history list
  - Distance statistics in race details
  - Track filter in history search
  - Improved edit modal with tabbed interface

### Fixed
- **Race Saving** - Fixed race data not including distance information
- **Lap Distance Calculation** - Fixed per-lap distance display
- **Track Selection Persistence** - Fixed selected track not restoring after reboot

### Technical
- **New Libraries**
  - `lib/TRACKMANAGER/` - Track management system
  - `trackmanager.h` - Track struct and TrackManager class
  - `trackmanager.cpp` - CRUD operations and storage
- **LapTimer Enhancements**
  - Added track pointer and distance tracking fields
  - `setTrack()`, `getTotalDistance()`, `getDistanceRemaining()` methods
  - Distance calculation in `finishLap()`
- **Frontend Enhancements**
  - Track management UI in Configuration modal
  - Distance polling system (100ms interval)
  - Enhanced race edit modal with tabs
  - Track selector components
- **Storage Structure**
  - `/tracks/` directory for track files
  - `/tracks/images/` for track images
  - Individual track files: `track_<timestamp>.json`
  - SD card preferred, LittleFS fallback

## [1.3.3] - 2024-12-10

### Added
- **Modern Configuration UI** - Complete redesign of configuration interface
  - Full-screen overlay modal with sidebar navigation
  - 6 organized sections: Lap & Announcer Settings, Pilot Info, LED Setup, WiFi & Connection, System Settings, Diagnostics
  - Mobile-responsive design with horizontal tabs on small screens
  - Click-outside-to-close and ESC key support
  - Based on Mainsail Interface settings design
  - Cleaner, more intuitive user experience
- **WebSocket Stability** - SSE keepalive mechanism
  - Automatic ping every 15 seconds to prevent connection timeout
  - Fixes RSSI disconnection requiring page refresh
  - Ensures stable long-running connections
  - Added `WEB_SSE_KEEPALIVE_MS` constant (15000ms)

### Changed
- **Configuration Menu** - Transformed from tabbed interface to overlay modal
  - Merged TTS settings into "Lap & Announcer Settings" section
  - Separated WiFi configuration into dedicated section
  - Improved visual hierarchy and organization
  - Settings footer with Save, Download, and Import actions

### Fixed
- **Duplicate Element IDs** - Resolved JavaScript targeting issues
  - Removed old config tab content causing duplicate IDs
  - Fixed battery monitoring toggle not working correctly
  - Fixed LED animation speed visibility for specific presets
- **WiFi Configuration** - Fixed non-functional WiFi settings
  - Properly wired Apply and Reset buttons
  - Moved Connection Mode selector to WiFi section
  - Added device restart warning for WiFi changes
- **UI Rendering** - Removed stray backtick-n characters from HTML output

### Technical
- Updated `data/index.html` - New settings modal structure with sidebar navigation
- Updated `data/style.css` - Complete modal styling system (lines 934-1418)
- Updated `data/script.js` - Modal management functions (openSettingsModal, closeSettingsModal, switchSettingsSection)
- Updated `lib/WEBSERVER/webserver.h` - Added sseKeepaliveMs timer and WEB_SSE_KEEPALIVE_MS constant
- Updated `lib/WEBSERVER/webserver.cpp` - SSE keepalive ping implementation in handleWebUpdate()

## [1.3.2] - 2024-12-10

### Added
- **WiFi Status Display** - Real-time WiFi connection status indicator in web interface
  - Shows AP mode with connected client count
  - Shows Station mode with connection status and signal strength (Weak/Fair/Good/Strong)
  - Visual indicators: AP mode (blue), STA connected (green), disconnected (red)
  - Auto-refreshes every 5 seconds via `/api/wifi` endpoint
  - Added `updateWiFiStatus()` and `startWiFiStatusPolling()` functions
  - CSS styling for all WiFi status states
- **Marshalling Mode** - Edit saved race data after completion
  - Add or remove laps from completed races
  - Add lap: Insert new lap time at specific position
  - Remove lap: Delete lap from race (with confirmation)
  - Real-time recalculation of race statistics (fastest lap, median, best 3, etc.)
  - Full UI with lap editing controls in race history details view
  - Changes saved to race history (SD card or LittleFS)
  - Useful for correcting false triggers or missed laps
- **LED Settings Persistence** - All LED configuration now saves to EEPROM and persists across reboots
  - Added `ledPreset`, `ledSpeed`, `ledFadeColor`, `ledStrobeColor`, `ledManualOverride` to config struct
  - Config version bumped to v3 for automatic migration
  - LED settings automatically restored on device boot
  - Page refresh now loads current LED state from device
  - All LED changes (/led/preset, /led/brightness, /led/speed, /led/color, /led/fadecolor, /led/strobecolor, /led/override) now save to config
- **Race History File Structure** - Improved organization for race storage
  - Individual race files: `/sd/races/race_<timestamp>.json`
  - Index file: `/sd/races/races_index.json` (tracks all races)
  - Automatic directory creation on SD card
  - Better performance when loading/saving races
  - Easier to manage individual race files
  - LittleFS fallback maintains same structure

### Changed
- **Default LED Preset** - Rainbow Wave is now the default LED effect (was Solid Colour in web UI)
- **Config JSON Buffer** - Increased from 256 to 512 bytes to accommodate expanded LED settings
- **Frontend LED Loading** - Web interface now properly loads all LED settings from device config on page load
  - Loads preset, brightness, speed, all colors, and manual override state
  - Removed old ledMode (0-3) mapping logic in favor of direct ledPreset usage
- **Race History Loading** - Now properly loads from individual files with index
  - Faster loading of large race histories
  - Better error handling for corrupted files
  - Automatic migration from old `races.json` format

### Fixed
- **Gate 1 Timing Bug** - Fixed Gate 1 lap time calculation
  - Gate 1 time now correctly represents time from race start to first gate pass
  - Previously was showing incorrect timing
  - Lap numbering remains consistent (Gate 1, Lap 1, Lap 2, etc.)
- **Race History Not Saving** - Fixed races not persisting to SD card
  - Race history now properly saves after each race
  - SD card mounting and file writing verified
  - Individual file structure prevents data loss
- **LED Settings Reset on Page Refresh** - LED configuration now persists properly instead of reverting to defaults
- **Solid Colour Default Bug** - Fixed page loading with wrong LED preset (was showing Solid Colour instead of saved preset)
- **WiFi Network Join** - Station mode now properly joins existing WiFi networks
  - SSID and password correctly applied from configuration
  - Fallback to AP mode if connection fails (with LED indication)
  - Connection status properly displayed in web interface

### Technical
- Updated `lib/CONFIG/config.h` - Added 5 new LED config fields, incremented CONFIG_VERSION to 3
- Updated `lib/CONFIG/config.cpp` - Added getters/setters, JSON serialization, and defaults for new LED fields
- Updated `lib/WEBSERVER/webserver.cpp` - All LED endpoints now call config setters to persist changes, added `/api/wifi` endpoint
- Updated `src/main.cpp` - LED initialization now loads all settings from config (preset, speed, colors, override)
- Updated `data/script.js` - Added WiFi status polling, marshalling mode functions, improved race history handling
- Updated `data/index.html` - Added WiFi status display element, marshalling mode UI
- Updated `data/style.css` - Added WiFi status indicator styling
- Updated `lib/RACEHISTORY/racehistory.cpp` - Implemented individual file storage, added lap editing functions
- Updated `lib/RACEHISTORY/racehistory.h` - Added `addLap()`, `removeLap()` methods
- Updated `lib/LAPTIMER/laptimer.cpp` - Fixed Gate 1 timing calculation
- Config struct size: ~140 bytes (well within 256 byte EEPROM reservation)

## [1.3.1] - 2024-12-08

### Fixed
- **Race History Storage** - Fixed race history not being initialized with storage backend
  - Races now properly save to SD card/LittleFS after each session
  - Added automatic race history reload when SD card is mounted
  - Previously, race history was not persisting across reboots
- **Calibration Wizard Threshold Calculation** - Complete overhaul for better accuracy
  - Now calculates thresholds as drops from peak (25% and 40%) instead of rises from baseline
  - Entry RSSI: 25% down from peak (catches rising edge well into spike)
  - Exit RSSI: 40% down from peak (catches falling edge, still above baseline)
  - Typically results in ~20-30 RSSI difference (was often 60+ before)
  - Much more accurate and intuitive threshold values

### Changed
- **Calibration Wizard UI** - Simplified to 3-peak marking system
  - Users now only mark the 3 highest peaks (one per lap)
  - Previously required 6 marks (entry and exit for each lap)
  - Updated instructions to clarify peak-only marking
- **Calibration Chart Display** - Enhanced visual smoothing
  - Added 15-point moving average filter (visual only, doesn't affect data)
  - Added filled area under RSSI line matching main chart style
  - Makes peaks much easier to identify and mark accurately

### Technical
- Updated `src/main.cpp` - Added `raceHistory.init(&storage)` call
- Updated `data/index.html` - Simplified wizard instructions
- Updated `data/script.js` - New threshold calculation and visual smoothing
- Cleaned up temporary files and test directories from repository

## [1.3.0] - 2024-12-04

### Added - Mobile & iOS Support
- **iOS/Safari Audio Support**: Full audio functionality on iOS devices
  - Automatic audio context unlocking on user interaction
  - Shared AudioContext for beep tones to prevent suspension
  - Web Audio API properly resumed on iOS/Safari
  - Web Speech API voice loading for iOS
- **Mobile-Responsive Interface**: Optimized web interface for phones and tablets
  - Responsive tables and navigation with flex-wrap
  - Mobile-optimized chart heights (250px)
  - Single-column stat boxes on phones
  - Touch-friendly buttons and controls
- **Vibration Feedback**: Race start vibration (works even in silent mode)
  - 500ms vibration on race start
  - Vibration API integration for mobile devices

### Added - USB Connectivity & Desktop
- **USB Serial CDC**: Direct USB connection for low-latency communication
  - Zero-latency local connection
  - Automatic USB/WiFi detection and switching
- **Electron Desktop App**: Native desktop application
  - Windows, macOS, and Linux support
  - Native USB connectivity via serialport
  - Full feature parity with web interface
  - Bundled with all dependencies
- **Transport Abstraction Layer**: Unified API for WiFi and USB
  - `usb-transport.js` - WebUSB and native USB support
  - Single codebase works over both WiFi and USB
  - Automatic transport selection

### Added - OSD Overlay System
- **Live Race Display**: Dedicated OSD page for streaming
  - Real-time lap time updates via Server-Sent Events
  - Transparent background for OBS/StreamLabs overlay
  - Customizable layout with pilot name, lap times, race timer
  - Multi-monitor support
  - One-click URL copying for easy setup
- **OSD HTML/CSS/JS**: Complete overlay implementation
  - `osd.html`, `osd.css`, `osd.js`
  - Event-driven architecture for real-time updates

### Added - Cross-Device Race Storage
- **SD Card Race Storage**: Races stored on SD card for shared access
  - Race storage path: `/races.json` → `/sd/races/races.json`
  - Automatic `/sd/races/` directory creation
  - Cross-device accessibility (all connected devices see same data)
  - LittleFS fallback if SD card unavailable

### Added - Enhanced Race Management
- **Race Tagging**: Add custom tags to races for organization
- **Race Naming**: Name races for easy identification
- **Race Details View**: Comprehensive analysis with lap-by-lap breakdown
- **Fastest Round Analysis**: Best consecutive 3-lap combinations
- **Individual Race Export**: Download single races for sharing
- **Race Search & Filter**: Find races by name, tag, or date

### Added - Documentation
- **Comprehensive Wiki**: New wiki-style documentation
  - `docs/GETTING_STARTED.md` - Setup and flashing guide
  - `docs/USER_GUIDE.md` - Complete feature walkthrough
  - `docs/HARDWARE_GUIDE.md` - Components and wiring
  - `docs/FEATURES.md` - In-depth technical documentation
  - `docs/DEVELOPMENT.md` - Building and contributing
- **Updated README**: Clearer project overview and quick start

### Changed
- **Audio System**: iOS/Safari compatibility improvements
  - Beep tones use persistent AudioContext
  - Audio unlock during "Enable Audio" button press
  - PiperTTS AudioContext resume on iOS
- **LED Control**: Enhanced configuration options
  - Pattern selection with color pickers
  - Speed and brightness controls
  - Manual override mode
- **Battery Monitoring**: Improved UI with voltage tracking and alerts
- **Theme Support**: Multiple color themes (Oceanic, Darker, Lighter, Midnight)

### Fixed
- **PiperTTS on iOS**: Fixed suspended AudioContext preventing audio playback
- **Race Start Beeps on Mobile**: Fixed beep tones not playing on iOS/Safari
- **USBSerial Compilation Error**: Changed `USBSerial` to `Serial` for ESP32-S3
- **Audio Requiring Multiple Interactions**: Single interaction now unlocks all audio

### Technical
- **Server-Sent Events**: Real-time race updates for OSD and multi-client sync
- **WebUSB Support**: Browser-based USB communication
- **Electron Integration**: Desktop app with serialport
- **iOS Detection**: Platform and user agent detection for iOS/Safari
- **Media Queries**: Responsive CSS for mobile, tablet, desktop
- **Race Storage Migration**: Moved from internal flash to SD card

### Compatibility
- **Hardware**: ESP32-S3 DevKitC-1 (8MB Flash)
- **Browsers**: Chrome, Firefox, Safari (iOS 12+), Edge
- **WebUSB**: Chrome 89+, Edge 89+
- **Desktop App**: Windows 10+, macOS 10.13+, Linux (Ubuntu 18.04+)
- **Mobile**: iOS 12+, Android 8+
- **SD Card**: FAT32, 4GB-32GB recommended

### Known Issues
- iOS silent mode mutes audio (by design, cannot be bypassed)
- Vibration API only works on mobile devices
- WebUSB not available on Firefox or Safari
- Race migration from LittleFS to SD card not automatic

## [1.2.1] - 2024-12-01

### Added
- **SD Card Storage Support** - Audio files now stored on MicroSD card
- SD card pin configuration: GPIO39 (CS), GPIO36 (SCK), GPIO35 (MOSI), GPIO37 (MISO)
- Automatic sound migration from LittleFS to SD card on first boot
- `Storage::migrateSoundsToSD()` - Migration utility method
- `Storage::isSDAvailable()` - SD card status check
- SD-aware audio file streaming with LittleFS fallback
- Self-test diagnostics for SD card functionality
- SD_CARD_MIGRATION_GUIDE.md documentation

### Changed
- **Partition table optimized** - LittleFS reduced from 4.4MB to 1MB
- **OTA partition size increased** - Each slot now 2MB (was 1.8MB)
- Audio files served from SD card first, LittleFS fallback
- README.md updated with SD card wiring and setup
- QUICKSTART.md updated with SD card instructions
- WARP.md updated with SD card architecture notes

### Fixed
- Flash storage constraints - 85% more free space available
- OTA update size limitations - Now supports 2MB firmware

### Technical Details
- Deferred SD initialization (5 seconds after boot) prevents watchdog timeout
- Non-blocking audio streaming directly from SD card
- Graceful degradation if SD card unavailable or fails

The format is based on [Keep a Changelog](https://keepachangelog.com/en/1.0.0/),
and this project adheres to [Semantic Versioning](https://semver.org/spec/v2.0.0.html).

## [1.2.0] - 2025-12-01

### Added
- **System Self-Test Functionality**: Comprehensive diagnostics for hardware and software validation
  - Tests: RX5808 RSSI module, Lap Timer, Audio/Buzzer, Configuration, Race History, Web Server, OTA Updates, Storage (LittleFS), EEPROM, WiFi, Battery Monitor, RGB LED
  - Accessible via "System Diagnostics" section in Configuration page
  - Visual pass/fail indicators with test duration and detailed error messages
  - REST API endpoint `/api/selftest` for programmatic access
- **PiperTTS Integration**: Lower latency text-to-speech option
  - **Exclusive Mode**: When PiperTTS is selected, it's used exclusively for all announcements (no pre-recorded file attempts)
  - **Fallback Mode**: ElevenLabs voices now fall back to PiperTTS only when pre-recorded files fail
  - Added to Voice dropdown as "PiperTTS (Lower Latency)"
  - Automatic TTS engine selection based on voice choice
- **Enhanced LED Presets**:
  - Renamed "Custom Color" to "Solid Colour" and moved to position 1
  - **Color Pickers**: Added for Solid Colour, Color Fade, and Strobe presets
  - **New Preset**: "Pilot Colour" - uses pilot's color from Pilot Info section
  - **Slowed Effects**: Police (20x slower) and Strobe (15x slower), scaled by effect speed
  - Removed redundant presets: Red Pulse, Green Solid, Blue Pulse, White Solid
- **Enhanced Config Import/Export**: Now includes all frontend settings
  - Theme, Audio settings (format, voice, TTS engine)
  - Pilot settings (callsign, phonetic, color)
  - LED settings (preset, colors, speed, manual override)
  - Battery monitoring toggle state

### Changed
- **UI Organization**: Created dedicated "TTS Settings" section in Configuration page
  - Groups: Announcer Type, Lap Announcement Format, Voice, Announcer Rate, Voice Control buttons
  - Improved logical organization of audio-related settings
- **Voice Selection Logic**: Automatically sets TTS engine based on selected voice
  - PiperTTS voice → sets engine to 'piper'
  - ElevenLabs voices → sets engine to 'webspeech'
- **LED Preset Organization**: Reordered for better usability
  - Order: Off, Solid Colour, Rainbow, Color Fade, Fire, Ocean, Police, Strobe, Comet, Pilot Colour
- **Battery Monitoring**: Now unchecked by default

### Fixed
- **Audio Infinite Loop Bug**: Fixed recursive `speak()` calls when pilot-specific audio files weren't found
  - Changed to direct `useTtsFallback()` calls in `speakComplexWithPilot()` and `speakComplexLapTime()`
  - Prevents infinite recursion when custom pilot audio is missing
- **Voice Control Button Styling**: Removed opacity from disabled state for better visibility
- **Toggle Switch Stretching**: Fixed CSS selector to exclude toggle switches from min-width rule
- **Include Guards**: Added proper include guards to RX5808.h, kalman.h, and laptimer.h
  - Prevents redefinition errors during compilation
  - Enables modular header inclusion

### Removed
- **TTS Fallback Engine Dropdown**: Removed from UI (now automatically determined by voice selection)

### Technical
- **Memory Usage**: Flash: 54.3% (996,581 bytes), RAM: 16.7% (54,632 bytes)
- **New Test Infrastructure**: SelfTest class with 13 individual test methods
- **Forward Declarations**: Used in selftest.h to avoid circular dependencies
- **Filesystem**: 4,653,056 bytes (1,792,357 compressed) - includes updated UI and audio files

## [1.1.0] - 2025-11-28

### Added - Natural Voice TTS System
- **Hybrid TTS System** with three-tier fallback:
  - Primary: ElevenLabs pre-recorded audio (natural, high-quality)
  - Secondary: Piper TTS via WASM (good quality, offline)
  - Fallback: Web Speech API (browser default)
- **Natural Number Pronunciation**: Numbers 0-99 spoken naturally
  - "11.44" → "eleven point forty-four" (not "one one point four four")
  - Instant audio transitions with <50ms gaps between clips
- **Voice Generation Scripts**:
  - `generate_voice_files.py` - Main generator with ElevenLabs API
  - `generate_all_voices.py` - Generate all 4 voice options
  - Support for 4 voices: Sarah (energetic), Rachel (calm), Adam (male), Antoni (male)
- **Comprehensive Audio Library**:
  - 100 number files (0-99) for natural time announcements
  - Race control phrases (arm_your_quad, starting_tone, gate_1, race_complete)
  - Lap numbers 1-50 for "Lap X" announcements
  - Pilot-specific audio (pilot_lap.mp3, test_sound.mp3)
- **Optimized Audio Playback**:
  - 1.3x playback speed for faster announcements
  - Audio caching for instant replay
  - `preservesPitch = false` for better quality at higher speeds
  - Early audio completion detection (50ms before end)

### Added - UI/UX Improvements
- **Redesigned Lap Table**:
  - New columns: Lap No | Lap Time | Gap | Total Time
  - Gap column shows difference from previous lap (+0.23s or -0.15s)
  - Total Time shows cumulative race time
  - Data attributes for lap indexing
- **Fastest Lap Highlighting**:
  - Gold/orange highlight (#f39c12) on fastest lap row
  - Subtle glow effect for visual distinction
  - Dynamically updates as new laps are completed
  - Excludes Gate 1 from fastest lap calculation
- **Enhanced Lap Analysis Stats**:
  - **Fastest Lap**: Shows lap number (e.g., "Lap 5" or "Gate 1")
  - **Fastest 3 Consecutive**: NEW - RaceGOW format support (e.g., "G1-L1-L2")
  - **Best 3 Laps**: Sum of 3 fastest individual laps (non-consecutive)
  - **Median Lap**: Statistical middle lap time
- **Configurable Lap Announcement Formats**:
  - Full: "Richard Lap 5, 12.34"
  - Lap + Time: "Lap 5, 12.34"
  - Time Only: "12.34"
  - Saved to localStorage for persistence

### Changed
- **"Hole Shot" → "Gate 1"**: More intuitive terminology
- **Race Start Audio**: Fixed timing - beep now plays AFTER voice announcements complete
- **Stop Race**: Now clears audio queue to prevent race start sounds
- **Audio File Organization**: Custom 3.94MB filesystem partition for expanded storage
- **Partition Table**: Custom 8MB layout (2MB app0 + 2MB app1 + 3.94MB filesystem)

### Fixed
- **Race stop beep bug**: Removed unwanted start beep when stopping race
- **Audio gaps**: Eliminated 200ms pauses between audio clips
- **Queue processing**: Removed 100ms gaps between announcements
- **Fastest lap color**: Changed from primary theme color to gold for distinction
- **Lap time gaps**: Now calculated correctly (difference from previous lap, not total)

### Technical
- **Audio Caching**: Map-based caching system for instant audio replay
- **Smart Preloading**: `oncanplay` event for faster first-play
- **Filesystem**: Upgraded from 1.5MB to 3.94MB partition
- **Audio Files**: 217 total files, 3.1MB (2.3MB compressed on device)
- **API Usage**: ~5,000 characters of ElevenLabs API (50% of free tier)

### Documentation
- Added `VOICE_GENERATION_README.md` - Complete voice setup guide
- Added `CHANGELOG.md` - Version history tracking
- Updated README.md with v1.1.0 features

### Developer Experience
- Python scripts for voice generation with progress tracking
- Auto-save configuration for voice selection and lap format
- localStorage persistence for frontend-only settings
- Comprehensive console logging for audio debugging

## [1.0.0] - 2025-11-XX

### Initial Release
- Single-node RSSI-based lap timing
- ESP32-S3 support with RX5808 module
- RGB LED indicators (NeoPixel support)
- Web interface with 23 themes
- Basic voice announcements (Web Speech API)
- Real-time RSSI calibration graph
- Race history with lap analysis
- WiFi Access Point mode
- OTA firmware updates
- Battery monitoring with alarms
- Configurable lap count (finite/infinite)
- Pilot profiles with callsigns
- Manual lap entry
- Config import/export

---

## Version Numbering

FPVGate follows [Semantic Versioning](https://semver.org/):
- **MAJOR**: Breaking changes or complete rewrites
- **MINOR**: New features, backwards compatible
- **PATCH**: Bug fixes, minor improvements

[1.2.0]: https://github.com/LouisHitchcock/FPVGate/releases/tag/v1.2.0
[1.1.0]: https://github.com/LouisHitchcock/FPVGate/releases/tag/v1.1.0
[1.0.0]: https://github.com/LouisHitchcock/FPVGate/releases/tag/v1.0.0

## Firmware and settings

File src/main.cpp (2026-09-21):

#include "debug.h"
#include "led.h"
#if RSSI_LOGGING_ENABLED
#include "rssilog.h"
#endif
#include "buzzer.h"
#include "config.h"
#include "cpumon.h"
#include "laptimer.h"
#include "multinode.h"
#include "racehistory.h"
#include "RX5808.h"
#include "selftest.h"
#include "storage.h"
#include "transport.h"
#include "usb.h"
#include "webhook.h"
#include "fpv_webserver.h"
// DISABLED FOR NOW: #include "nodemode.h"  // Uncomment to re-enable RotorHazard support
#include "ota.h"
#ifdef ESP32S3
#include "rgbled.h"
#endif

// ====================================================================
// ROTORHAZARD MODE - CURRENTLY DISABLED
// To re-enable RotorHazard support in the future:
// 1. Uncomment the OperationMode enum below
// 2. Uncomment nodeMode initialization and usage throughout this file
// 3. Uncomment the mode detection logic in setup()
// 4. Uncomment the mode-specific code in loop()
// ====================================================================

// DISABLED: Operation mode enumeration
// enum OperationMode {
//     MODE_WIFI,
//     MODE_ROTORHAZARD
// };
// 
// OperationMode currentMode = MODE_WIFI;
// static NodeMode nodeMode;  // RotorHazard node mode controller

// Mode Switching Information:
// =========================
// SOFTWARE MODE SWITCH:
// - Change "opMode" in config via web interface (0=WiFi, 1=RotorHazard)
// - Requires REBOOT to take effect
// - Setting is stored in EEPROM and persists across reboots
//
// PHYSICAL MODE SWITCH (when installed):
// - GPIO9 to GND = Force WiFi mode (overrides software setting)
// - GPIO9 floating = Use software config setting
// - Hardware switch always takes priority over software setting

static RX5808 rx(PIN_RX5808_RSSI, PIN_RX5808_DATA, PIN_RX5808_SELECT, PIN_RX5808_CLOCK);
static Config config;
static Storage storage;
static SelfTest selfTest;
static Webserver ws;
static USBTransport usbTransport;
static TransportManager transportManager;
static Buzzer buzzer;
static Led led;
static RaceHistory raceHistory;
static WebhookManager webhookManager;
static MultiNodeManager multiNodeManager;
#ifdef ESP32S3
static RgbLed rgbLed;
RgbLed* g_rgbLed = &rgbLed;
#else
void* g_rgbLed = nullptr;
#endif
static LapTimer timer;
#if RSSI_LOGGING_ENABLED
static RssiLogger rssiLogger;
#endif
// Battery monitoring removed - legacy feature no longer used
// static BatteryMonitor monitor;

static TaskHandle_t xTimerTask = NULL;
static bool sdInitAttempted = false;

// Core-0 stall instrumentation.  Tracks the worst single sub-call duration
// across each 10 s window plus the worst gap between consecutive ticks (the
// latter catches FreeRTOS preemption by higher-priority tasks like AsyncTCP).
// If a sub-call takes ≥100 ms it's logged immediately with its name; the 10 s
// summary line then shows the worst seen across the window even if it was
// under that loud-log threshold.
//
// Why this matters: the multi-node timeout symptom is "4 clients flagged
// offline in the same millisecond, all recovering 2 s later" — only possible
// if Core 0 didn't run multiNodeManager.process() for 3+ s.  Finding the
// offender call is the prerequisite for fixing it.
struct Core0CallSample { const char* name = nullptr; uint32_t ms = 0; };
static Core0CallSample worstCallThisWindow;
static uint32_t        worstTickGapThisWindow = 0;
static uint32_t        lastTickEndMs          = 0;
static uint32_t        coreReportLastMs       = 0;

static inline void timeCall(const char* name, void (*invoke)()) {
    // Helper unused — we expand the timing inline below to avoid forcing
    // every sub-call through an indirection.  Kept as documentation.
    (void)name; (void)invoke;
}

// Bring-up window.  Boot legitimately contains multi-second blocking work that
// can never happen again: startAP() runs a full WiFi channel scan (~2.5 s,
// 120 ms x 13 channels), and that scan is load-bearing — clients carry a whole
// tier-3 reconnect path precisely because the master re-picks its channel every
// boot.  Reported identically to a mid-race stall, it teaches you to skim past
// [CORE0] lines, and a 2.5 s stall during a race is a serious event that must
// not look like routine boot noise.  So it is still printed in full, just
// labelled for what it is.
#define CORE0_BOOT_SETTLE_MS 15000

#define CORE0_TIME(NAME, EXPR) do {                                         \
    uint32_t _t0 = millis();                                                \
    EXPR;                                                                   \
    uint32_t _dt = millis() - _t0;                                          \
    if (_dt > worstCallThisWindow.ms) {                                     \
        worstCallThisWindow.ms   = _dt;                                     \
        worstCallThisWindow.name = NAME;                                    \
    }                                                                       \
    if (HARNESS_LOG_ENABLED && _dt >= 100) {                                \
        DEBUG("[CORE0] %s blocked for %u ms at t=%us%s\n", NAME,            \
              (unsigned)_dt, (unsigned)(_t0 / 1000),                        \
              (_t0 < CORE0_BOOT_SETTLE_MS) ? "  (boot bring-up)" : "");     \
    }                                                                       \
} while (0)

static void parallelTask(void *pvArgs) {
    for (;;) {
        uint32_t tickStart = millis();
        if (lastTickEndMs != 0) {
            uint32_t gap = tickStart - lastTickEndMs;
            if (gap > worstTickGapThisWindow) worstTickGapThisWindow = gap;
        }

        uint32_t currentTimeMs = tickStart;
        CORE0_TIME("buzzer",     buzzer.handleBuzzer(currentTimeMs));
        CORE0_TIME("led",        led.handleLed(currentTimeMs));
#ifdef ESP32S3
        CORE0_TIME("rgbLed",     rgbLed.handleRgbLed(currentTimeMs));
#endif
        // OTA update work runs here (blocking) when an apply is pending.
        //
        // NOTE: the ESP32-C6 is SINGLE-core.  An earlier comment here claimed
        // "the RSSI loop on Core 1 is unaffected" — that was never true on
        // this chip.  This task and the Arduino loop task (which samples RSSI)
        // share the one HP core; this task runs at priority 2, loop() at 1.
        // A long blocking call here therefore CAN delay sampling.  In practice
        // most of the blocking is socket I/O, during which the task yields and
        // loop() runs — but that is a property of what we block on, not of
        // core isolation.  Measure it, don't assume it: TIMING_STATS_ENABLED
        // reports the worst sample gap, and the [CORE0] lines below report the
        // worst sub-call duration.
        CORE0_TIME("ota",        otaManager.loop());
        CORE0_TIME("webUpdate",  ws.handleWebUpdate(currentTimeMs));
        CORE0_TIME("usb",        usbTransport.update(currentTimeMs));
        CORE0_TIME("eeprom",     config.handleEeprom(currentTimeMs));
        CORE0_TIME("rxFreq",     rx.handleFrequencyChange(currentTimeMs, config.getFrequency()));
        CORE0_TIME("webhooks",   webhookManager.process());
        CORE0_TIME("multinode",  multiNodeManager.process(currentTimeMs));
#if CPU_MONITOR_ENABLED
        // Closes a load window every CPU_MONITOR_WINDOW_MS and publishes it.
        // Cheap: two uxTaskGetSystemState() calls per window, not per tick.
        CORE0_TIME("cpumon",     CpuMonitor::getInstance().tick(currentTimeMs));
#endif

        uint32_t tickEnd = millis();
        lastTickEndMs = tickEnd;

        // Roll up the window every 10 s.  Even if no individual sub-call
        // crossed the 100 ms loud threshold, this line surfaces the worst
        // measured tick + the worst preemption gap so you can see whether
        // Core 0 is healthy across the whole period.
        if (tickEnd - coreReportLastMs >= 10000) {
            coreReportLastMs = tickEnd;
            // Counters are reset below either way — only the reporting is
            // gated, so a release build still measures, it just stays quiet.
            if (HARNESS_LOG_ENABLED) {
                DEBUG("[CORE0] window 10s: longest sub-call %s=%u ms, longest tick gap=%u ms\n",
                      worstCallThisWindow.name ? worstCallThisWindow.name : "(idle)",
                      (unsigned)worstCallThisWindow.ms,
                      (unsigned)worstTickGapThisWindow);
            }
            worstCallThisWindow.ms   = 0;
            worstCallThisWindow.name = nullptr;
            worstTickGapThisWindow   = 0;

#if CPU_MONITOR_ENABLED
            // Stack headroom, on the same 10 s cadence.  This costs nothing to
            // collect: uxTaskGetSystemState() already fills usStackHighWaterMark
            // for every task and cpumon was discarding it.
            //
            // Read it as "worst free bytes, ever, on the tightest task".  Unlike
            // heap figures it never recovers — it is a high-water mark — so a
            // number that stops falling is a task that has found its true depth.
            // Under ~2000 bytes on any task, stop shrinking stacks: an overflow
            // here is an immediate crash with no warning and no diagnostic.
            const CpuMonitor::Snapshot& cs = CpuMonitor::getInstance().getLast();
            if (HARNESS_LOG_ENABLED && cs.valid && cs.minStackFreeBytes != 0xFFFF) {
                DEBUG("[STACK] tightest: %s=%u B free | loop=%u parallel=%u asyncTcp=%u\n",
                      cs.minStackTask, (unsigned)cs.minStackFreeBytes,
                      (unsigned)cs.stackLoopTask,
                      (unsigned)cs.stackParallelTask,
                      (unsigned)cs.stackAsyncTcp);
            }
#endif
        }

        // Let other tasks run (WiFi/AsyncWebServer/etc.)
        vTaskDelay(1);
    }
}

static void initParallelTask() {
    disableCore0WDT();

    // Priority 2 so it reliably runs even when loop() is busy.
    // (Arduino loop task is typically priority 1.)
    xTaskCreatePinnedToCore(
        parallelTask,
        "parallelTask",
        8192,
        NULL,
        2,
        &xTimerTask,
        0
    );
}


void setup() {

    // Serial must be first so all subsequent DEBUG() calls are visible
    Serial.begin(115200);
    delay(100);
    while (Serial.available()) { Serial.read(); }
    DEBUG_INIT;

    // Bound a blocked USB CDC write to ~2 ms instead of the 100 ms default.
    //
    // Serial here is HWCDC (ARDUINO_USB_CDC_ON_BOOT=1).  Its TX ring is 256
    // bytes.  When USB is PLUGGED BUT NOTHING IS DRAINING the port — a timer
    // powered from a laptop, no terminal open — the ring fills and every write
    // then blocks for tx_timeout_ms.  That is not a bench-only condition, and
    // the writes that matter are the ones on loop(): handleLapTimerUpdate()
    // emits the 10-second [TIMING] summary itself, so the log line stalled the
    // sampler and the NEXT window reported the stall as a 114 ms gap.  The
    // diagnostic was manufacturing the fault it reported.
    //
    // 1, NOT 0.  With 0 the driver's retry counter starts at zero and is
    // decremented BEFORE its `tries == 0` exit test; a full byte-buffer returns
    // pdTRUE for a zero-length send (documented IDF behaviour), so the loop
    // makes no progress, underflows to 0xFFFFFFFF and spins on delay(1) for
    // ~49 days.  1 gives a single retry then a clean exit.
    //
    // Cost: characters are dropped rather than waited on when the host is not
    // reading.  DebugLogger fills its in-memory ring BEFORE calling Serial, so
    // /api/debuglog and the web Serial Monitor keep the full record either way.
    Serial.setTxTimeoutMs(1);

    // Initialize storage first (LittleFS only at boot)
    storage.init();

    // Initialize config and connect to storage for SD backup/restore
    config.setStorage(&storage);
    config.init();

    // Set antenna option from persisted config (must run before WiFi starts)
    if (config.getWifiExtAntenna()) {
        pinMode(WIFI_ENABLE, OUTPUT);
        digitalWrite(WIFI_ENABLE, LOW);   // Activate RF switch control
        delay(200);
        pinMode(WIFI_ANT_CONFIG, OUTPUT);
        digitalWrite(WIFI_ANT_CONFIG, HIGH); // Use external antenna
    }
    
    /* DISABLED: RotorHazard mode detection
    // Check physical mode switch
    pinMode(PIN_MODE_SWITCH, INPUT_PULLUP);
    delay(10);  // Allow pin to settle
    
    int modePin = digitalRead(PIN_MODE_SWITCH);
    
    // Physical switch overrides software setting
    // If pin is explicitly pulled LOW (to GND), force WiFi mode
    // If pin reads HIGH (floating with pullup), use software config
    if (modePin == WIFI_MODE) {
        // Physical switch connected to GND = force WiFi mode
        currentMode = MODE_WIFI;
    } else {
        // Pin is HIGH (floating) = use software config
        uint8_t configMode = config.getOperationMode();
        if (configMode == 0) {
            currentMode = MODE_WIFI;
        } else {
            currentMode = MODE_ROTORHAZARD;
        }
    }
    */

    // set LED pin
    pinMode(LED_BUILTIN, OUTPUT);
    digitalWrite(LED_BUILTIN, HIGH);

    // Suppress VFS file-not-found errors (reduces spam from API endpoint checks)
    esp_log_level_set("vfs_api", ESP_LOG_NONE);
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
void loop() {
    uint32_t currentTimeMs = millis();

    // LED Flashing
    static bool led_on = false;
    static uint32_t t = 0;
    
    if (ws.servicesStarted) {
        if (currentTimeMs - t > 500) {
            t = millis();
            led_on = !led_on;
            digitalWrite(LED_BUILTIN, led_on ? HIGH : LOW);
        }
    } else {
        digitalWrite(LED_BUILTIN, HIGH); // LED off when services not started
    }
    
    // Re-arm the ADC stream if a WiFi bring-up or flash write asked for it,
    // or if the stall watchdog inside finds the stream has stopped.  HERE and
    // nowhere else: this is loopTask, the task that started the stream in
    // setup() and therefore the only one allowed to stop it (the ADC unit
    // lock is a mutex).  Before the timer update so this iteration's sample
    // comes from the re-armed feed.  A counter compare on every other
    // iteration.
    rx.serviceRearm();

    // Timing always runs
    timer.handleLapTimerUpdate(currentTimeMs);
#if RSSI_LOGGING_ENABLED
    rssiLogger.log(timer.snapshot);
#endif
    
    // A scheduled race start just fired (§8).  Tell the UI at the instant the
    // race ACTUALLY began, not when the start command arrived — the command
    // lands up to RACE_START_MARGIN_US early, and at a different moment on
    // every node because the fanout is sequential.  Emitting here is what
    // keeps the displays as synchronised as the timers underneath them.
    if (timer.consumeStartEvent()) {
        // A GO that arrived over UDP did none of the bookkeeping the old HTTP
        // masterStart handler used to do — it only carried a timestamp.  All
        // of it belongs here anyway, at the real start:
        if (multiNodeManager.isClientMode()) {
            multiNodeManager.setTimerRunning(true);    // heartbeat now reports racing
            multiNodeManager.setMasterRaceActive(true);
            // A client's Race View listens on masterRaceState, not raceState,
            // so both have to be released or the pilot's own display never
            // starts at all.
            ws.getEvents()->send("started", "masterRaceState");
        }
        transportManager.broadcastRaceStateEvent("started");
        ws.pushMultiNodeState();
    }

    // Broadcast lap events to all transports (WiFi + USB)
    if (timer.isLapAvailable()) {
        uint32_t lapTime   = timer.getLapTime();
        uint8_t  peakRssi  = timer.getLastLapPeakRssi();
        transportManager.broadcastLapEvent(lapTime, peakRssi);
        // In client mode, also queue the lap to be forwarded to the master node
        multiNodeManager.queueLap(lapTime);
    }
    
    // OTA update progress is driven from parallelTask (otaManager.loop());
    // no per-loop work needed here.

    // Initialize SD card after boot (deferred to prevent watchdog timeout)
    // Try once after 5 seconds of uptime
    if (!sdInitAttempted && currentTimeMs > 5000) {
        sdInitAttempted = true;
        DEBUG("\n=== Deferred SD card initialization ===\n");
        
        if (storage.initSDDeferred()) {
            DEBUG("SD card ready!\n");
            
            // Try to restore config from SD backup if EEPROM was invalid
            // (This handles the case where config was reset to defaults during boot)
            DEBUG("Checking for config backup on SD card...\n");
            if (config.loadFromSD()) {
                DEBUG("Config restored from SD backup after SD mount\n");
            }
            
            // Migrate sounds from LittleFS to SD card
            if (storage.migrateSoundsToSD()) {
                DEBUG("Sound files migrated successfully!\n");
                DEBUG("Recommend: delete /sounds from LittleFS to reclaim space\n");
            }
            
            // Reload race history from SD card
            if (raceHistory.loadRaces()) {
                DEBUG("Race history reloaded from SD card, %d races available\n", raceHistory.getRaceCount());
            } else {
                DEBUG("Race history reload from SD card failed\n");
            }
        } else {
            DEBUG("SD card not available - using LittleFS only\n");
        }
    }
    
    /* DISABLED: RotorHazard mode loop
    if (currentMode == MODE_WIFI) {
        // WiFi mode - original behavior
        ElegantOTA.loop();
        
        // ... SD card initialization code ...
    } else {
        // RotorHazard mode - run node protocol
        nodeMode.process();
        
        // Still update hardware (LED, buzzer) but NOT web server
        buzzer.handleBuzzer(currentTimeMs);
        led.handleLed(currentTimeMs);
#ifdef ESP32S3
        rgbLed.handleRgbLed(currentTimeMs);
#endif
        rx.handleFrequencyChange(currentTimeMs, config.getFrequency());
        monitor.checkBatteryState(currentTimeMs, config.getAlarmThreshold());
    }
    */

    vTaskDelay(1); // so we don't hog the CPU
}

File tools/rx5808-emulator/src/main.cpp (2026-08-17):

// ─────────────────────────────────────────────────────────────────────────────
// RX5808 analog emulator — bench test rig for FPVRaceOne timing measurement
//
// WHAT THIS IS FOR
//
// Real-world stimulus cannot answer "is the lap timer late or inconsistent".
// A servo swinging past an antenna has millisecond-scale variance of its own,
// so you end up characterising the servo. This board replaces the RX5808's
// analog RSSI output with a precisely-timed synthetic envelope, making the
// stimulus deterministic to microseconds.
//
// WHAT IT MEASURES
//
//   1. Lap-time accuracy  — bias between a known pulse interval and the lap
//                           time FPVRaceOne reports
//   2. Lap-time consistency — standard deviation of that error
//   3. Absolute latency   — stimulus-to-detection delay, via the marker pin
//
// WHY NO CLOCK SYNC IS NEEDED (the key idea)
//
// A lap time is a DIFFERENCE measured entirely by FPVRaceOne's own clock. If
// pulses are generated exactly T apart and the device reports L, the error is
// L - T. No relationship between this board's clock and the device's clock is
// involved, so USB jitter is irrelevant. Absolute latency likewise: both the
// stimulus start and the marker edge are timestamped HERE, on one timer.
//
// WHAT IT IS NOT
//
// This reproduces the RSSI ENVELOPE, not RF. No multipath, no antenna nulls,
// no interference. It faithfully exercises the acquisition and detection
// pipeline; it does not predict real-world detection reliability.
//
// WIRING (see tools/timing-harness/README.md)
//
//   GPIO25 (DAC1) --[2.2k]--+-- A2/GPIO2  RSSI input on XIAO C6
//                           |
//                        [1.0k]
//                           |
//   GND --------------------+-- GND       common ground, REQUIRED
//
//   GPIO4 (input) <------------ D3/GPIO21 PIN_TIMING_MARKER on XIAO C6
//
// The real RX5808 must be disconnected from the RSSI line only; the three SPI
// lines may stay wired since this emulator ignores them (analog-only by
// design — verifyFrequency() will log a mismatch, and its return value is
// ignored by the sole caller, so nothing breaks).
// ─────────────────────────────────────────────────────────────────────────────

#include <Arduino.h>
#include <ArduinoJson.h>
#include <esp_system.h>
#include <soc/dac_channel.h>
#include <hal/dac_ll.h>

// ── Pins ────────────────────────────────────────────────────────────────────
static const uint8_t PIN_DAC_RSSI = 25;  // DAC1 on WROOM-32 (header pin 9)
static const uint8_t PIN_MARKER   = 4;   // marker input from FPVRaceOne

// ── Envelope playback ───────────────────────────────────────────────────────
//
// A hardware timer ISR steps through the envelope so playback timing is immune
// to anything happening in loop() or in FreeRTOS. 10 kHz gives 100 us steps —
// 200 points across a 20 ms pass, ample shape resolution, and two orders of
// magnitude finer than the millisecond effects being measured.
static const uint32_t TICK_HZ = 10000;
static const uint32_t TICK_US = 1000000UL / TICK_HZ;

// Profile, set over USB before a run.
struct Profile {
    uint8_t  baseline   = 40;    // DAC counts at rest (noise floor)
    uint8_t  peak       = 200;   // DAC counts at pass apex
    uint32_t widthMs    = 40;    // full width of the pass envelope
    uint32_t intervalMs = 5000;  // start-to-start spacing between passes
    uint32_t count      = 10;    // number of passes in a run
};
static Profile profile;

// Run state. Touched by both the ISR and loop(), so anything shared is
// volatile and anything multi-word is read under a critical section.
static volatile bool     running       = false;
static volatile uint32_t passesDone    = 0;
static volatile uint32_t tickInPass    = 0;   // ticks since current pass began
static volatile uint32_t ticksPerPass  = 0;   // envelope duration in ticks
static volatile uint32_t ticksPerCycle = 0;   // pass start to next pass start
static volatile uint32_t passStartUs   = 0;   // micros() at current pass start
static volatile bool     inPass        = false;

// Marker capture — written by the GPIO ISR, drained by loop().
//
// markerStartUs is latched INSIDE the ISR rather than read later in loop().
// Reading passStartUs at drain time was a latent bug: if the next pass began
// between the edge and the drain, the latency would be differenced against
// the wrong t0 and appear as a large negative outlier.  Latching both values
// together makes each measurement self-consistent by construction.
static volatile uint32_t markerUs      = 0;
static volatile uint32_t markerStartUs = 0;
static volatile bool     markerPending = false;
// Edges discarded because the previous one had not been drained.  Silently
// dropping these hid missing measurements; counting them means the harness
// can say so instead of quietly reporting fewer samples than passes.
static volatile uint32_t markerDropped = 0;

static hw_timer_t* envTimer = nullptr;
static portMUX_TYPE mux     = portMUX_INITIALIZER_UNLOCKED;

// Raised-cosine envelope: 0 at the edges, 1 at the centre, smooth throughout.
// Approximates the RSSI rise and fall of a gate pass far better than a square
// pulse, and its smoothness is what makes the median filter behave the way it
// would on real hardware.
// PRECOMPUTED, because the ISR must not touch floating point.
//
// This originally evaluated 0.5*(1-cos(2*pi*x)) inline in the timer ISR.  That
// is unsafe on ESP32: FreeRTOS does not save or restore FPU state across an
// interrupt, so float arithmetic in an ISR yields intermittently wrong results
// and can corrupt the FPU registers of whatever task was interrupted.  cosf()
// is also a flash-resident libm call being made from an IRAM handler.
//
// The symptom was subtle and easy to misread: most passes were generated
// correctly, but occasional ones came out with the wrong amplitude and simply
// failed to cross the detector's enter threshold — presenting as a lap-timer
// detection failure when the fault was in the stimulus.
//
// The shape is now built once in task context (where float is fine) into an
// integer table of DAC values; the ISR does a bounds-checked index and nothing
// else.
#define ENV_TABLE_SIZE 512
static uint8_t envTable[ENV_TABLE_SIZE];

// Build the raised-cosine envelope for the current baseline/peak.  Called from
// startRun(), never from an ISR.
static void buildEnvelopeTable(uint8_t baseline, uint8_t peak) {
    const float span = (float)peak - (float)baseline;
    for (uint32_t i = 0; i < ENV_TABLE_SIZE; i++) {
        const float x = (float)i / (float)(ENV_TABLE_SIZE - 1);   // 0..1
        const float w = 0.5f * (1.0f - cosf(2.0f * PI * x));      // 0..1..0
        envTable[i] = (uint8_t)(baseline + span * w + 0.5f);
    }
}
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

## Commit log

2025-12-29 fixed calibration tab bug
2025-12-29 enable/disable voice buttons are now persisting. Cleaned up some UI
2025-12-30 Improving lap timer detection by minimizing false positives.
2025-12-30 increased Wifi power and back to internal antenna
2026-01-01 fixed the huge delay to tune a new channel fixed logging and double eeprom writes
    [main.cpp]
2026-01-01 tweaked calibration wizard calculateThresholds to enter higher and exit above the valleys
2026-01-03 cleaned up unused items
    [FPVGate_Carrier.kicad_pcb, FPVGate_Carrier.kicad_sch, custom_8mb.csv]
2026-01-03 calibration recording is now using paging to serve up the json calibration data, to prevent overflow.
2026-01-07 updated partitions for larger firmware size.
    [partitions_two_ota_XIAO_ESP32_C6.csv]
2026-04-07 increased Wifi power and robustness reduced wifi chatter
2026-04-11 added settings to control antenna and power
2026-04-11 added reboot button
2026-04-12 improved filtering and removed delay
2026-04-12 adjusted kalman filter
2026-04-16 added RotorHazard's signal processing and timing method as an mode option (v2) cleaned up the settings save pipeline
2026-04-19 making wifi sockets and SSE connections more robust
2026-04-19 reworked calibration wizard calcs
2026-04-21 bugs fixed added build timestamps to footer
    [extra_script.py]
2026-04-24 adjusting rssi calibration
2026-04-24 added Bessel filtering to lap detection
2026-04-26 fixed filtering bugs
2026-05-05 fixed calibration chart live display smoothing and delay
2026-05-07 adjusted enter and exit for auto calibration
2026-05-10 fixed bugs with OTA
    [Bambu_Top_and_Bot.3mf]
2026-05-10 reverted version tag to 0.1.x pre-release added a pre-release toggle in firmware
    [extra_script.py]
2026-05-10 fixed case bug
2026-05-10 fixed release notes button height loosened the wifi client detection so more than 1 client doesn't trigger all to get temporary disconnect banners.
2026-05-14 updated case bottom updated documentation tweaked UI
    [Bambu_Bot.3mf, Bambu_Top_and_Bot.3mf]
2026-05-21 fixed some ui issues on the race history tab
    [extra_script.py, flash_published_release.py]
2026-05-25 made channel scanning more robust and allows 1 additional client to connect to the master in case there is a stray pilot attached.
2026-05-25 removed track manager features as they were not being used.
2026-06-06 client units can request the same slot they used previously.
2026-06-07 master can now run the calibration wizard on clients and adjust rssi enter and exit cleaned up some connection bugs slots renamed from numbers to letters
2026-06-11 fixed some wifi edge case connection bugs
2026-06-14 cleaned up some host settings sync bugs cleaned up the calibration wizard buttons re-introduced RSSI Live feed for remote pilots during a race (with warning)
2026-06-17 Improve README.md content for clarity and detail
    Updated descriptions for clarity and added details about device accessibility.
2026-06-17 Update power supply requirement to USB-C compatibility
2026-06-19 Heap issue with zombie connection bug fixed. Bug in node disconnect and reconnect detection fixed.
    [main.cpp]
2026-06-20 cleaned up documentation and unused file
    [custom_8mb.csv]
2026-06-20 ota: pause multinode + human-readable errors during firmware update
    - Pause multi-node networking for the home-WiFi excursion: master rejects
    client polls so TCP slots free up, client drops STA from master so the
    radio is free for home WiFi. Persisted mode is unchanged; mesh resumes
    on success, cancel, or via a 5-min safety auto-resume.
    - Frontend confirm dialog explains the consequence in plain English
    before anything is paused, so a director can bail out.
    - Translate ESP HTTPClient negative codes (-1, -7, ...) into actionable
    English instead of surfacing "HTTP -1" verbatim.
    - Wizard modal scrolls when content overflows so the Apply / Calculate
    buttons stay reachable on screens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
    [main.cpp]
2026-06-22 fixing firmware update check bugs
    [main.cpp]
2026-06-29 Update QUICKSTART.md with Lap Timer placement instructions
    Added instructions for placing the Lap Timer at the timing gate.
2026-06-29 Revise FPVRaceOne connection instructions
    Updated instructions for connecting to the FPVRaceOne device, including placement details and clarifications on connectivity.
2026-06-29 Clarify placement instructions for Lap Timer
2026-06-29 Update GETTING_STARTED.md for clarity
    Clarify WiFi connectivity details and VTX power settings.
2026-07-06 added refinement to the new detection routine, including a toggle to disable debounce fixe d a bug with the Calibrating pilot frequency, please wait approx 20 secs banner
2026-07-21 Revise README for clarity and additional details
    Updated README with improved clarity and details about the lap timing solution, including networking capabilities and calibration process.
2026-07-22 updated case
    [Bambu_Bot.3mf, Bambu_Top_and_Bot.3mf, FPVRaceOne_Case_20260722.3mf]
2026-07-22 added schematic and pcb renderings
2026-08-06 added cpu and loop timing monitoring
    [FPVRaceOne_Case_20260730_ironed.3mf]
2026-08-08 DMA sampling by default, lap-time precision setting, and a timing test rig
    FIRMWARE
    - adcMode now defaults to DMA continuous with peak-hold (CONFIG_VERSION 30).
    Measured on the emulator rig, browser closed, 30 passes 1500 ms apart:
    polled 1.21 ms lap-time stdev over a -3..+3 ms range and a 9 ms minimum
    detectable pass; DMA 0.00 ms stdev, +0..+0 ms range, 4 ms minimum. DMA
    reported all 29 lap intervals exactly. Lap time anchors to rssiPeakTimeMs,
    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
2026-08-08 resolved a communication blocking issue
    [gui.py, harness.py, main.cpp]
2026-08-08 fixed emulator test rig causing a reboot added raw device logs view and save to test rig
    [gui.py, harness.py, main.cpp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]
2026-08-08 fixed some bugs related to the a declining heap
    [gui.py]
2026-08-08 now gzipping the web files to reduce heap issues. adjusted CI workflow but need to test.
    [extra_script.py]
2026-08-13 fixed bugs in the fanout mechanism
    [partitions_two_ota_XIAO_ESP32_C6.csv]
2026-08-14 fixed a race start sync bug
    [main.cpp]
2026-08-15 fixed a timing issue
    [gui.py, harness.py]
2026-08-23 fixed USB buffer stalls
    [main.cpp]
2026-09-13 - re-skined UI - repaired multiple bugs - updated some documentation. working on more.
    [partitions_two_ota_XIAO_ESP32_C6.csv]
2026-09-14 documentation and case update
    [Bottom.3mf, Top.3mf]
2026-09-21 Fix intermittent RSSI flatline: re-arm ADC DMA after every WiFi bring-up (required on C6) Fix ~1.5% of boots corrupting the heap by removing a WiFi teardown that ran before the stack existed
    [main.cpp]
2026-09-21 Fix RSSI flatline after config saves: every flash write halts the ADC DMA stream (ISR not IRAM-safe on C6), so re-arm after each write and add a 100ms stall watchdog with a 3-strike cap
    [main.cpp]
2026-09-22 fixed subtle UI issues with rssi live view calibration wizard sample downloads to client are more efficient and self-healing
